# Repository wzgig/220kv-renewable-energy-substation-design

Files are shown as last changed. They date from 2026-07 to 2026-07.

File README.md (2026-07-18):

<div align="center">

# 220kV 新能源汇集变电所电气一次部分初步设计



课程设计工程仓库：主接线方案、负荷与短路计算、设备选型、配电装置设计、CAD 图纸、说明书与答辩材料。

[正式报告](report/README.md) · [交付说明](deliverables/README.md) · [完整性复盘](docs/DESIGN_COMPLETENESS_AUDIT.md) · [执行提示词](docs/EXECUTION_PROMPT.md) · [假设台账](docs/DESIGN_ASSUMPTIONS_REGISTER.md) · [手绘指南](docs/HAND_DRAWING_GUIDE.md) · [总体规划](docs/MASTER_PLAN.md) · [接线基线](docs/MAIN_SCHEME_BASELINE.md) · [设备预筛](docs/EQUIPMENT_SELECTION_BASELINE.md) · [设计输入](data/design_inputs.yaml) · [标准台账](docs/STANDARDS_REGISTER.md) · [需求追踪](docs/REQUIREMENTS_TRACEABILITY.md) · [CAD 工作流](docs/CAD_WORKFLOW.md) · [项目日志](PROJECT_LOG.md)

</div>

> [!IMPORTANT]
> 当前公开树及 `main` 可达历史只保留原创且已脱敏的成果。任务书原件、课程讲义、教材手册、他人设计书、参考 DWG、手稿照片和带个人元数据的文件均保留在本地私有材料区；旧 DWG 与身份记录已通过历史重写从 `main` 可达历史移除，可编辑 DWG 仅在本地保留。

本仓库固定对应第5组。第7组“220kV城市负荷中心变电所”已建立[独立公开仓库](https://github.com/wzgig/220kv-city-load-center-substation-design)，两组只共享通用工作流程，不共享设计数据和成果文件。

## 项目目标

完成一座 220/35/10kV 新能源汇集变电所的电气一次部分初步设计，形成可复核、可编辑、可打印和可答辩的完整交付物。当前任务书对应第 5 组，主变初始方案为 2×180MVA。

| 设计项 | 已确认输入 |
| --- | --- |
| 电压等级 | 220/35/10kV，另设 0.4kV 所用电系统 |
| 主变压器 | 2×180MVA、220/35kV、YNd11、uk=14% |
| 220kV 出线 | 2 回，预留 1 回；LGJ-400/50 |
| 35kV 集电线路 | 12 回，预留 2 回；WA-1～4、WB-1～3 为架空线并配置入口MOA，PVA-1～2、PVB-1～2、ES-1 为电缆并配置零序CT |
| 10kV 系统 | 2×31.5MVA、35/10.5kV、YNd11、uk=8% 的 T10；2×±12Mvar SVG；站用及辅助负荷 |
| 所用电系统 | 2×200kVA、10/0.4kV、SCB14 干式、Dyn11、uk=4%；轮换暗备用 |
| 短路计算基准 | 100MVA；平均额定电压 230/37/10.5kV |
| CAD 图纸范围 | 三张必交图：主接线、配电装置断面、平面布置；一张增强详图：SEC-220-L1-01 L1 线路间隔断面详图 |

## 当前设计基线

| 项目 | 已冻结结论 |
| --- | --- |
| 主变容量 | 2×180MVA、220/35kV、YNd11、uk=14%；正常负载率 77.857%；主变 N-1 需限发 35.780% |
| 10kV 电源与无功 | 2×31.5MVA、35/10.5kV、YNd11、uk=8% 的 T10；2×±12Mvar SVG |
| 所用变 | 2×200kVA、SCB14、Dyn11、uk=4%；正常一台运行，另一台暗备用 |
| 220kV 送出与分段职责 | 正常每回 367.780A；单回全送出及分段事故转供课程持续职责均取 735.559A；41℃课程保守允许载流量 475.242A |
| 220kV 短路职责 | 分列4.033kA/10.266kA，分段条件闭合7.385kA/18.798kA（RMS/峰值，含新能源课程上界）；电网单独3.607/6.500kA不是最终控制职责 |
| 10kV 短路等级 | 单台 T10 条件性最大综合上限 15.638kA；两台健康 T10 并列属禁止方式，敏感性为 28.472kA |
| 正常运行方式 | 220kV分段断路器、35/10kV母联正常断开；0.4kV母联正常闭合，一台所用变运行、另一台暗备用 |
| 中性点接地 | 220kV 中性点经中性点 CT 直接接地；35kV为2×1000kVA ZN接地变+低电阻、400A/10s、R≈50.5Ω；10kV为2×200kVA、200A/10s、R≈28.9Ω |
| 接地源联锁 | 正常分列时每段1套；母联合闸前退出受电/故障段接地源，仅保留健康侧1套；禁止母联闭合且两套接地源并联；重新分列后恢复每段1套 |
| MOA/零序CT | 220/35/10kV分别采用YH10W-204/532、YH5WZ-51/134、YH5WZ-17/45；7回35kV架空入口设MOA，5回35kV电缆及10kV电缆/SVG回路设零序CT；TOV/能量和精确型号待专题 |

这些数值是任务书缺项条件下的课程设计基线；教师明确口径、现行标准原文或厂家项目资料可以覆盖相应假设。

## 已形成的核心交付物

- 技术设计说明书：DOCX/PDF，正式 PDF 35 页 A4。
- 技术设计计算书：DOCX/PDF，29 页 A4。
- 课程设计总结：DOCX/PDF，4 页 A4。
- 答辩汇报：PPTX/PDF，11 页 16:9。
- 答辩问题清单：DOCX/PDF，7 页 A4。
- CAD 图纸按“三张必交图 + 一张增强详图”组织，共四张 A1 图：SLD-01、LAY-220-01、SEC-220-01 和 SEC-220-L1-01；公开 DXF/PDF/PNG，并在本地生成可编辑 DWG。四图已完成统一语义校验、AutoCAD AUDIT、A1 PDF/PNG 导出和逐图目检。
- 可再生的计算数据、脚本和 CAD 数据源。

## 仓库结构

~~~text
calculations/   可复核的负荷、电流、短路和设备校验计算
data/           任务书参数与后续设备数据
deliverables/   最终交付说明；压缩包本身不进入 Git 历史
docs/           项目范围、总体计划、决策、追踪矩阵与发布边界
drawings/       CAD 标准、块库、源图、导出图和绘图脚本
report/         说明书、计算书、总结和答辩材料
scripts/        项目健康检查及后续自动化工具
materials-private/  本地私有资料，仅 README 进入公开仓库
~~~

## 当前进度

- [x] 完成 128 个文件、约 283MiB 资料的结构与公开风险审计
- [x] 提取并冻结本组任务书的核心参数与交付要求
- [x] 确认 AutoCAD Core Console、A1 打印和 PDF/PNG 复核环境可用
- [x] 建立公开/私有边界、仓库结构和持续同步规则
- [x] 建立负荷/变压器、无功、LGJ温度修正、短路和设备预筛的可重复计算
- [x] 完成主接线技术经济比较并冻结可推进基线
- [x] 建立现行标准、废止版本和原文复核门槛台账
- [x] 完成220/35/10kV三相短路、变流器课程上界和1.10s I²t预校核
- [x] 建立220/35/10kV设备职责注册表和额定值等级预筛
- [x] 完成制图前拓扑复核：补入两回35kV电源变间隔并修正0.4kV暗备用正常状态
- [x] 冻结2×±12Mvar SVG、2×31.5MVA T10、海拔/污秽/保护时间等课程假设
- [x] 生成三张必交 A1 CAD 工程底图；公开 DXF/PDF/PNG，本地 DWG 通过 AutoCAD 原生 AUDIT，且通过 PDF/PNG 目检和 47 项阶段单元测试
- [x] 生成第四张 SEC-220-L1-01 A1/1:50 线路间隔增强详图的 DXF/PDF/PNG
- [x] 对本轮四图集成结果统一重跑 AutoCAD AUDIT、PDF/PNG 目检与语义检查；四图均为0错误并通过语义一致性校验
- [x] 完成四份正式报告 DOCX/PDF，并通过隐私、可访问性、审阅残留和逐页视觉终审
- [x] 完成11页答辩 PPTX/PDF，通过逐页渲染、画布溢出和元数据复核
- [x] 补齐课程级CT/PT与零序CT、MOA、接地变/NGR和接地开关；220kV管母完成载流/热稳/简化弯曲/电晕，35/10kV母线完成载流/热稳，绝缘子/套管完成电压、LIWV和持续/短时/峰值检查
- [ ] 完成精确设备型号、完整二次负荷、厂家动热稳定/温升、TOV/能量、外绝缘和真实场址校验
- [x] 完成本轮当前树隐私扫描、70 项测试、68 项健康检查及 GitHub Actions 等价再生成核验
- [x] 经授权完成含旧身份/DWG 的公开历史改写和精确租约强推；可达历史、GitHub Actions、远端提交与本地工作树均已核验

## 本地验证状态

| 验证对象 | 已完成 | 尚待完成 |
| --- | --- | --- |
| 四份正式报告 | 正式 PDF 为 35/29/4/7 页 A4，DOCX 与 PDF 已逐页终审 PASS；说明书和计算书已补充正式论证、编号公式、代入过程与结果分析；隐私、可访问性和审阅残留检查 PASS | 若后续重新生成，需重做目录、PDF 和隐私闭环 |
| 11 页答辩汇报 | PPTX/PDF 逐页渲染、画布溢出、页数和元数据检查 PASS | 当前树发布检查已通过 |
| 四张 A1 CAD 图（3+1） | 四图均完成DXF语义一致性校验、AutoCAD原生AUDIT（0错误）、单页A1 PDF/PNG导出和逐图目检 | 厂家外形、真实场址和施工级净距仍由后续工程资料覆盖 |
| 仓库发布 | 当前树隐私扫描、70 项测试、68 项健康检查、四图再生成校验和公开历史治理均已通过 | 后续有效修改继续执行提交、推送、Actions 和远端一致性闭环 |

## 工作方式

每个有效修改批次都执行以下闭环：

1. 更新计算、文档或图纸源文件。
2. 更新 PROJECT_LOG.md 和相关决策/追踪状态。
3. 运行项目检查：

   ~~~powershell
   powershell -NoProfile -ExecutionPolicy Bypass -File scripts/project_health_check.ps1
   ~~~

4. 使用 Conventional Commit 提交并推送到 main。
5. 核对 GitHub Actions、远端提交和工作区状态。

> [!NOTE]
> 任务书写明文档一般手写、图纸手绘。用户已确认CAD图作为完整工程底稿，最终按图手绘临摹；课程假设均可由教师或真实工程资料覆盖。

## 权利与资料边界

仓库目前不附开放源代码或内容许可证。第三方资料不在仓库中；后续若拆分原创脚本与原创图纸的授权，将分别处理，不能将第三方材料的权利扩展到本项目。

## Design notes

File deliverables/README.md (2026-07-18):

# 最终交付区

本目录只记录交付边界和打包规则；提交压缩包本身不进入 Git 历史。当前课程成果已存放在 `report/` 和 `drawings/` 中。

## 已形成的交付成果

| 类别 | 成果 | 位置与格式 | 本地验证 |
| --- | --- | --- | --- |
| 正式报告 | 技术设计说明书、计算书、课程设计总结、答辩问题清单 | `report/`，DOCX/PDF，正式 PDF 为35/29/4/7页 A4 | 逐页终审及 DOCX 隐私/可访问性/审阅残留检查 PASS |
| 答辩汇报 | 220kV 新能源汇集变电所答辩汇报 | `report/`，PPTX/PDF，11 页 16:9 | 逐页渲染、画布溢出、PDF 页数和公开元数据检查 PASS |
| 电气主接线简图 | `single_line_a1` | 公开 DXF/PDF/PNG；DWG 本地生成 | AutoCAD AUDIT、A1 PDF/PNG 目检和生成测试通过 |
| 配电装置平面布置图 | `switchyard_plan_a1` | 公开 DXF/PDF/PNG；DWG 本地生成 | AutoCAD AUDIT、A1 PDF/PNG 目检和生成测试通过 |
| 配电装置断面图 | `switchyard_section_a1` | 公开 DXF/PDF/PNG；DWG 本地生成 | AutoCAD AUDIT、A1 PDF/PNG 目检和生成测试通过 |
| L1线路间隔增强详图 | `switchyard_line_bay_detail_a1`（SEC-220-L1-01） | 公开 DXF/PDF/PNG；DWG 本地生成 | A1/1:50；AutoCAD AUDIT、PDF/PNG目检和语义生成测试通过 |

## 提交包应包含

- 课程设计任务书（仅提交，不公开原件）；
- 技术设计说明书；
- 技术设计计算书；
- 三张必交图：电气主接线图、配电装置断面图、平面布置图；
- 一张增强详图：SEC-220-L1-01 220kV I段L1线路间隔断面详图；
- 课程设计总结与答辩材料；
- 必要时提供 CAD 可编辑源文件和兼容版。

任务书原件、课程资料和含个人信息的提交版只能从本地私有材料区取用，不应复制到公开仓库。用户已确认CAD图可作为完整工程底稿，后续按“三张必交图+一张增强详图”手绘临摹。

## 打包前检查

- [x] 四份正式 PDF 页数和 A4 纸张规格已核对。
- [x] 答辩 PPTX/PDF 的 11 页渲染、溢出和元数据已核对。
- [x] 四张 CAD PDF 均为单页横向 A1，四份 DWG 的 AutoCAD AUDIT 均为0错误，PDF/PNG逐图目检和DXF语义检查通过。
- [x] SEC-220-L1-01 已核对1:50、设备链、ES、MOA、基础、接地接口和课程净距。
- [x] SLD-01 已核对线路侧ES位置、35/10kV接地变容量、母联接地源联锁、7回架空入口MOA、35/10kV电缆ZCT和三相CT职责分离。
- [x] 公开版姓名、学号、班级和签字字段保持留空。
- [x] 完成本轮当前树隐私与公开边界扫描；公开文件未发现身份、邮箱、绝对用户路径或生成器残留。
- [x] 复跑 70 项测试并完成 68 项 `scripts/project_health_check.ps1` 检查。
- [x] 核对实际提交文件、Office/PDF 元数据、CAD PDF/PNG 与可打开性。
- [x] 经授权完成含旧身份/DWG 的公开历史改写和精确租约强推，并核对 `main` 可达历史、GitHub Actions、远端提交和工作树状态。

提交压缩包、视频、页面渲染中间件和大型临时导出文件不进入 Git 历史。

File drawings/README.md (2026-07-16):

# 图纸工作区

本目录保存本项目原创的 CAD 标准、块库、结构化绘图数据、源图和导出图。第三方参考 DWG 位于本地私有材料区，不进入仓库。

本项目按“三张必交图 + 一张增强详图”组织四张 CAD 图纸。

三张必交图纸：

1. 电气主接线简图；
2. 配电装置断面图；
3. 配电装置平面布置图。

一张增强详图：

4. 220kV I 段 L1 线路间隔断面详图，用于补足设备链、接地开关、基础和净距表达。

所有图纸共用一份设备表、间隔表和尺寸/净距数据。公开仓库以可再生 DXF 为编辑源，PDF/PNG 预览放在 exports/；AutoCAD 生成的 DWG 保留在本地并由 `.gitignore` 排除，避免公开机器写入的 LastAuthor 元数据。详细流程见 [CAD 工作流](../docs/CAD_WORKFLOW.md)。

## 四张工程底图范围

| 图号 | 图纸 | 图幅/比例 | 可再生源 | AutoCAD与预览 |
| --- | --- | --- | --- | --- |
| SLD-01 | 电气主接线简图 | A1/NTS | `data/single_line_layout.yaml`、`scripts/generate_single_line.py` | 公开 `source/single_line_a1.dxf`、`exports/single_line_a1.pdf/.png`；DWG 本地生成 |
| LAY-220-01 | 220kV户外AIS平面布置图 | A1/1:200 | `data/switchyard_layout.yaml`、`scripts/generate_switchyard_drawings.py` | 公开 `source/switchyard_plan_a1.dxf`、`exports/switchyard_plan_a1.pdf/.png`；DWG 本地生成 |
| SEC-220-01 | 220kV户外AIS典型间隔断面图 | A1/1:100 | 同上 | 公开 `source/switchyard_section_a1.dxf`、`exports/switchyard_section_a1.pdf/.png`；DWG 本地生成 |
| SEC-220-L1-01 | 220kV I段L1线路间隔断面详图 | A1/1:50 | `data/switchyard_layout.yaml`、线路间隔详图生成逻辑 | 公开 `source/switchyard_line_bay_detail_a1.dxf`、`exports/switchyard_line_bay_detail_a1.pdf/.png`；DWG 本地生成 |

平面图表达两段三相母线、正常断开的分段间隔、L1/L2、远期L3、T1/T2、母线PT/CVT、道路、主控楼和35/10kV配电楼。SEC-220-01 同页表达线路间隔A-A与主变间隔B-B，标注母线/构架标高、相间距、设备序列和课程净距表。SEC-220-L1-01 将线路设备链放大到 1:50，表达母线侧QS、QF、TA、线路侧QS+常开ES、CVT、MOA、出线构架、基础及接地连接；地下接地网只作接口示意，不虚构接地电阻、接触电压或跨步电压计算。

~~~powershell
.venv\Scripts\python.exe drawings\scripts\generate_single_line.py
.venv\Scripts\python.exe drawings\scripts\generate_switchyard_drawings.py
powershell -NoProfile -ExecutionPolicy Bypass -File drawings\scripts\export_all_drawings.ps1
pdftoppm -png -r 150 -singlefile drawings\exports\single_line_a1.pdf drawings\exports\single_line_a1
pdftoppm -png -r 150 -singlefile drawings\exports\switchyard_plan_a1.pdf drawings\exports\switchyard_plan_a1
pdftoppm -png -r 150 -singlefile drawings\exports\switchyard_section_a1.pdf drawings\exports\switchyard_section_a1
pdftoppm -png -r 150 -singlefile drawings\exports\switchyard_line_bay_detail_a1.pdf drawings\exports\switchyard_line_bay_detail_a1
~~~

`normalize_pdf.py` 会在规范化元数据时清除 AutoCAD 为 SHX 文字自动写入的 PDF 批注层；公开版四图必须保持单页横向 A1、`/Annots` 为 0，且规范化前后 PNG 像素哈希一致。

主接线图统一采用：主变2×180MVA、220/35kV、YNd11、uk=14%；T10 2×31.5MVA、35/10.5kV、YNd11、uk=8%；所用变2×200kVA、SCB14、Dyn11、uk=4%；SVG 2×±12Mvar。35kV每段采用1000kVA ZN接地变+低电阻，400A/10s、R≈50.5Ω；10kV每段采用200kVA，200A/10s、R≈28.9Ω。正常每段1套，母联合闸前退出受电/故障段接地源，只保留健康侧1套，禁止母联合闸且两套并联。7回35kV架空入口标MOA，5回35kV电缆及10kV电缆/SVG回路标ZCT。`R`表示预留；CT/PT完整二次负荷、ZCT窗口/负担、41℃厂家适配、MOA能量/TOV和真实场址资料仍由后续专题覆盖。

平断面图中的A1/A2/B1/B2/C/D来自课程第七章表7-2；14m典型间隔、4m相间距、9m母线标高、道路、建筑和设备外形均明确标为课程设计几何假设，不得当作施工放样尺寸。

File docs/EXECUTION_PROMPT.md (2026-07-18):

# 课程设计执行提示词

## 本轮说明书与计算书补充重构提示词

> 以当前项目中的技术设计说明书、技术设计计算书、统一 YAML 参数、可再生计算结果和已冻结设计决策为依据，对报告进行实质性补充与结构优化。保留可靠的原始数据、表格、图纸和结论，不把课程假设写成任务书原值，也不虚构尚缺的厂家或现场参数。每个设计与计算环节均按“设计目的与依据—计算或选择方法—符号及单位—公式—参数取值—逐步代入—结果—合理性校验—工程含义与边界”的顺序展开；将现有以表格汇总为主的表达改为“正文论证为主、公式推导支撑、表格归纳结果”的正式工科课程设计结构。重点补充主接线方案取舍、负荷与变压器容量、N-1限发、SVG与T10、所用电、持续电流、标幺短路计算、变流器贡献、设备额定/开断/峰值/I²t校验、母线、接地变与低电阻、MOA和事故运行联锁。所有新增数值优先从统一结果文件读取；发现不同计算口径时必须并列说明，不得用含混文字掩盖差异。完成后重新生成 DOCX/PDF，更新目录和页码，运行计算、测试、隐私清理及逐页渲染检查，并保留修改前原版。

## 可直接复用的重构版提示词

> 你是本项目的电力工程课程设计协作代理。总目标是完成“第5组 220kV 新能源汇集变电所电气一次部分初步设计”，形成计算可复核、图纸可手绘临摹、文档与图纸一致、公开仓库可持续维护的完整工程底稿。
>
> ### 1. 输入与证据优先级
>
> 1. 任务书、教师明确要求和本组原始数据优先级最高，不得用网络资料覆盖。
> 2. 任务书缺项时，优先使用现行国家标准、行业标准的官方题录或合法取得的正文，以及设备厂家正式样本。
> 3. 仍无法取得唯一值时，采用偏保守且适合课程设计的工程假设继续推进。每项假设必须记录类别、数值、理由、影响、替换触发条件和复核状态。
> 4. 教师新口径或真实场址/设备资料到达后，统一输入文件中的新值覆盖课程假设，并同步重算、重绘、重写。
>
> ### 2. 设计范围
>
> - 完成原始资料整理、主接线方案比较、负荷与变压器选择、最大持续工作电流、短路电流、设备选择与动热稳定校验、配电装置设计、说明书、计算书、总结和答辩提纲。
> - 必须完成任务书要求的三张图：电气主接线简图、220kV 户外 AIS 配电装置典型断面图、220kV 户外 AIS 平面布置图；另增加一张 `SEC-220-L1-01` 线路间隔 A1/1:50 断面详图，作为设备校核和手绘临摹增强成果。
> - CAD 图按完整工程底图绘制，并导出 DWG、DXF、PDF、PNG；最终由用户按底图手绘临摹。
>
> ### 3. 一致性规则
>
> - `data/design_inputs.yaml` 保存题目输入和显式假设，`data/design_baseline.yaml` 保存冻结方案；计算、设备职责、图纸和文档必须读取同一数据源。
> - 不允许在图纸、说明书或设备表中单独手填与统一输入不一致的容量、电流、编号、母联状态或设备数量。
> - 预留回路、正常断开、事故切换、条件性运行方式和禁止运行方式必须在计算与图纸中明确区分。
>
> ### 4. 研究与计算规则
>
> - 网络检索优先官方标准平台、政府/电网机构和厂家正式资料；搜索摘要、百科、论坛和营销转载只能作为线索，不能单独支撑数值结论。
> - 所有公式保留变量定义、单位、代入值、结果和判据。关键结果至少做自动测试或独立数量级复核。
> - 课程设计假设不能伪装成标准固定值；标准题录不能替代需要逐条核对的标准正文。
>
> ### 5. CAD 规则
>
> - 使用参数化 YAML/CSV、Python/ezdxf 和 AutoCAD Core Console 生成、审计、转换和出图。
> - CAD 批处理以 Core Console、PDF 渲染和 PNG 目检形成可重复闭环。
> - 平面图与断面图共用设备外形、间隔宽度、道路、净距和标高数据；不得从旧参考图按比例猜尺寸。
> - 每张图必须有图框、图号、比例、图例、设计说明、关键尺寸、设备编号和课程假设标识，且适合打印后手绘临摹。
> - 对照任务书、指导书和参考设计逐项检查设备完整性。确认需要的断路器、隔离开关、接地开关、三相CT、零序CT、PT/CVT、MOA、母线、绝缘子、套管及接地变+低电阻设备包必须同步进入数据、计算、图纸和报告；35/10kV母联转供必须固化“先退出受电/故障段接地源、仅保留健康侧1套”的联锁。经计算判定不需要的限流电抗器等设备，也要写明“不采用”的判据，不能以沉默代替设计结论。
> - 避雷器与避雷针分开处理：完成各电压等级 MOA 配置和课程级绝缘配合；缺少雷暴日、土壤电阻率、厂家外形等资料时，不伪造直击雷保护范围、接地网电阻或施工放样尺寸。
>
> ### 6. 版本与公开规则
>
> - 原始任务书、私人资料、受限标准全文、旧参考设计和第三方 DWG 仅保存在 `materials-private/`，不得进入公开 Git 历史。
> - 每个有效批次依次完成：重新生成结果、单元测试、项目健康检查、CAD/PDF 目检、项目日志更新、逐文件暂存、提交、推送、远端 Actions 核验。
> - 不使用 `git add .`；不得提交浏览器缓存、临时文件、自动保存文件或提交压缩包。
>
> ### 7. 完成判据
>
> - 任务书追踪矩阵覆盖全部要求；关键未决项只剩教师或真实工程数据才能替换的复核项。
> - 计算结果、设备表、主接线、平面图、断面图和说明书中的容量、电流、编号、运行方式完全一致。
> - 三张必交 CAD 图和一张增强详图均可编辑、可再生、无缺字和裁切，DXF 经语义检查，DWG 经 AutoCAD AUDIT，PDF/PNG 已逐图目检；用户能够据此手绘临摹。
> - 本地分支与 GitHub `main` 一致，自动检查通过，公开仓库不含私人或受限材料。

## 本轮已确认授权

- 用户已确认允许完成完整 CAD 工程底图，最终自行手绘临摹。
- 用户已允许对任务书未给参数进行官方资料检索，或采用明确标注的合理课程设计假设。
- 只有改变根本拓扑、造成明显安全风险或无法形成保守取值的问题才需要再次询问。

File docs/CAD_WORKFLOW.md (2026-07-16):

# CAD 制图与自动化工作流

## 已确认环境

本项目使用 AutoCAD Core Console、GB A0-A4 图框、DWG To PDF 打印配置和黑白打印样式。Core Console 已实测完成 DXF 原生 AUDIT、2018 DWG 保存和 A1 PDF 打印，并以 PDF/PNG 渲染目检完成闭环。

现有 17 个参考 DWG 仅作版式和布置理解。其中部分旧图引用本机缺失的第三方 SHX 字体，直接复用可能导致乱码和尺寸漂移，因此新图从统一标准与块库开始构建。

## 目录约定

~~~text
drawings/
├── standards/  图层、文字、标注、线宽、图框与打印标准
├── blocks/     一次设备与电气符号块
├── data/       拓扑、设备、间隔、坐标和净距参数
├── source/     公开原创 DXF；DWG 仅本地生成并忽略
├── scripts/    生成、校核、转换和批量打印脚本
└── exports/    PDF/PNG 预览与兼容版输出
~~~

## 技术路线

1. 用 YAML/CSV 保存主接线拓扑、设备表、间隔顺序、尺寸和安全净距。
2. 使用 Python ezdxf 参数化生成 ASCII DXF，保证源文件可再生。
3. 使用 AutoCAD Core Console 执行 SCR/AutoLISP 校核、转换和批量出图。
4. 使用项目 PowerShell 脚本调用 AutoCAD Core Console，执行 AUDIT、保存 2018 DWG 并通过官方 PC3/CTB 打印。
5. 用 Poppler 将 PDF 渲染为 PNG，目检文字、线宽、图框、比例、标注和打印范围。

Python 依赖统一写入根目录 `requirements.txt` 并安装到项目虚拟环境，不污染系统环境：ezdxf 用于 DXF 生成和语义审计，pypdf 用于规范化 AutoCAD PDF。

CI不直接比较平断面DXF的原始字节，而比较实体、图层、线型、字体和文字/几何的语义指纹；这样可忽略ezdxf在独立进程中可能出现的CLASSES表顺序差异，同时仍能阻止真实图面漂移。

## 当前四张图纸范围

~~~text
drawings/data/single_line_layout.yaml
drawings/data/switchyard_layout.yaml
drawings/standards/single_line_standard.yaml
drawings/standards/switchyard_standard.yaml
drawings/scripts/sld_symbols.py
drawings/scripts/generate_single_line.py
drawings/scripts/generate_switchyard_drawings.py
drawings/scripts/export_single_line.ps1
drawings/scripts/export_all_drawings.ps1
drawings/scripts/normalize_pdf.py
drawings/source/single_line_a1.dxf
drawings/source/switchyard_plan_a1.dxf
drawings/source/switchyard_section_a1.dxf
drawings/source/switchyard_line_bay_detail_a1.dxf
drawings/exports/single_line_a1.pdf
drawings/exports/single_line_a1.png
drawings/exports/switchyard_plan_a1.pdf
drawings/exports/switchyard_plan_a1.png
drawings/exports/switchyard_section_a1.pdf
drawings/exports/switchyard_section_a1.png
drawings/exports/switchyard_line_bay_detail_a1.pdf
drawings/exports/switchyard_line_bay_detail_a1.png
~~~

中文文字采用本机已验证的 `txt.shx + gbcbig.shx` 大字体组合，避免 Core Console 对 TTC 字体替换成问号。DXF 使用 R2018/AC1032、毫米单位、A1 横向 841×594 模型空间纸面坐标；DWG 作为本地 AutoCAD 兼容输出，不进入公开 Git 历史。

三张必交图已有AutoCAD Core Console原生AUDIT与目检PASS证据，SEC-220-L1-01的DXF/PDF/PNG也已生成。四图集成后必须统一重跑AUDIT、A1单页PDF、150dpi PNG、逐图目检和语义检查；PDF规范化还须清除AutoCAD SHX文字批注层并确认`/Annots=0`，且规范化前后PNG像素哈希一致。公开仓库使用DXF/PDF/PNG，本地DWG不进入Git。

## 制图顺序

### 1. 电气主接线简图

- 输入：最终主接线方案、主变/T10/所用变联结组与阻抗、回路/母线/母联、三相CT/PT、零序CT、MOA、接地变+低电阻和接地开关配置。
- 重点：220、35、10、0.4kV 电压层次清晰；本期与预留回路区分；设备编号唯一；220kV ES接在线路侧QS之后；35/10kV接地设备包容量与母联接地源联锁说明齐全。
- 验收：图中回路数与任务书、回路表、设备表完全一致；7回35kV架空入口MOA、5回35kV电缆ZCT、10kV电缆/SVG ZCT及“母联合闸前仅保留健康侧1套接地源”均可在图面或说明中定位。

### 2. 配电装置断面图

- 输入：典型间隔设备型号、外形尺寸、安全净距、支架和母线标高。
- 重点：剖切位置、设备中心线、相间/相地净距、基础与检修空间。
- 验收：所有尺寸有来源，不能从参考图按比例猜测。

### 3. 配电装置平面布置图

- 输入：间隔表、出线方向、道路、建筑/构架、设备坐标和断面参数。
- 重点：220kV 向西北出线，35kV 向东/向南，站内与备用电源方向合理；预留间隔清楚。
- 验收：平面与断面使用同一设备、间隔宽度、编号和标高体系。

### 4. SEC-220-L1-01 线路间隔增强详图

- 图幅与比例：A1横向、1:50。
- 设备链：220kV I段管形母线→母线侧QS→QF→TA→线路侧QS+常开ES→CVT→YH10W-204/532 MOA→出线构架。
- 表达内容：设备编号、课程额定参数、基础、构架与设备接地、地下接地网接口、主要标高、水平尺寸及A1/A2/C类净距。
- 边界：设备外形、基础荷载和端子方向由厂家图覆盖；缺少土壤电阻率和接地网几何时，不填写接地网电阻、接触电压、跨步电压，也不声称避雷针已覆盖全站。

## 平断面统一参数

- 220kV户外AIS、分相中型布置；分段正常断开；
- 相间中心距4.0m，典型相邻功能中心按14m节距组织；
- 母线中心标高9.0m、线路构架挂线点14.5m、主变构架挂线点11.5m；
- 课程表7-2净距：A1=1800、A2=2000、B1=2550、B2=1900、C=4300、D=3800mm；
- SEC-220-L1-01 采用A1/1:50放大线路间隔，净距、标高和设备编号必须与LAY-220-01、SEC-220-01同源；
- 设备外形、道路、建筑和基础是课程几何假设，精确厂家图优先覆盖。

## 图形标准草案

- 当前中文文字使用 AutoCAD 自带 `txt.shx + gbcbig.shx`，西文与数字使用兼容字体，并以最终 PDF/PNG 打印效果为准。
- 不提交版权不明的第三方 SHX；避免外部参照和绝对路径。
- 图层至少区分：母线、一次设备、导线、符号、文字、尺寸、中心线、构筑物、道路、预留和图框。
- 黑白打印依赖线宽表达，不以屏幕颜色代替最终线宽。
- 原生文件保存为 2018 格式，并输出 PDF 与 PNG；如教师或提交平台要求，再另存 2013 兼容版。

## CAD 质量检查

- 无缺失字体、代理对象、未绑定外部参照和不可解析路径；
- 图形范围正常，无远离原点的垃圾对象；
- 图层、块名、设备编号和属性命名稳定；
- 图框、比例、单位、线宽和打印区域正确；
- PDF 中无裁切、重叠、黑块、乱码或过细线条；
- 当前候选树以公开 DXF/数据/脚本重建关键图形，本地 DWG 不再进入新提交；既有历史的旧 DWG 待用户确认后清理。

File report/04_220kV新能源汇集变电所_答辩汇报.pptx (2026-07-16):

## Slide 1

《发电厂电气部分》课程设计 · 第5组

220kV新能源汇集变电所
电气一次部分初步设计

主接线 · 容量与短路 · 设备及防雷接地预筛 · AIS平断面与L1详图

公开答辩版｜姓名、学号、班级与签字留空

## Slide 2

本设计以270MW新能源汇集与四级电压系统为主线

设计对象

220 / 35 / 10 / 0.4kV

12回35kV集电线路

两回220kV本期送出，预留L3

交付范围

技术设计说明书 + 计算书

SLD-01 主接线图
LAY-220-01 平面图
SEC-220-01 典型断面图
SEC-220-L1-01 L1线路间隔详图

答辩清单与可追溯计算脚本

2

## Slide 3

最终主接线通过分段与分列运行控制风险

方案结论

220kV采用单母线分段；35kV和10kV均采用单母线两分段；0.4kV采用单母线分段。

正常运行：220kV分段断路器断开；
35/10kV母联断开；0.4kV母联闭合。

T1、T2分别带35kV I/II段，T10与SVG按段配置。

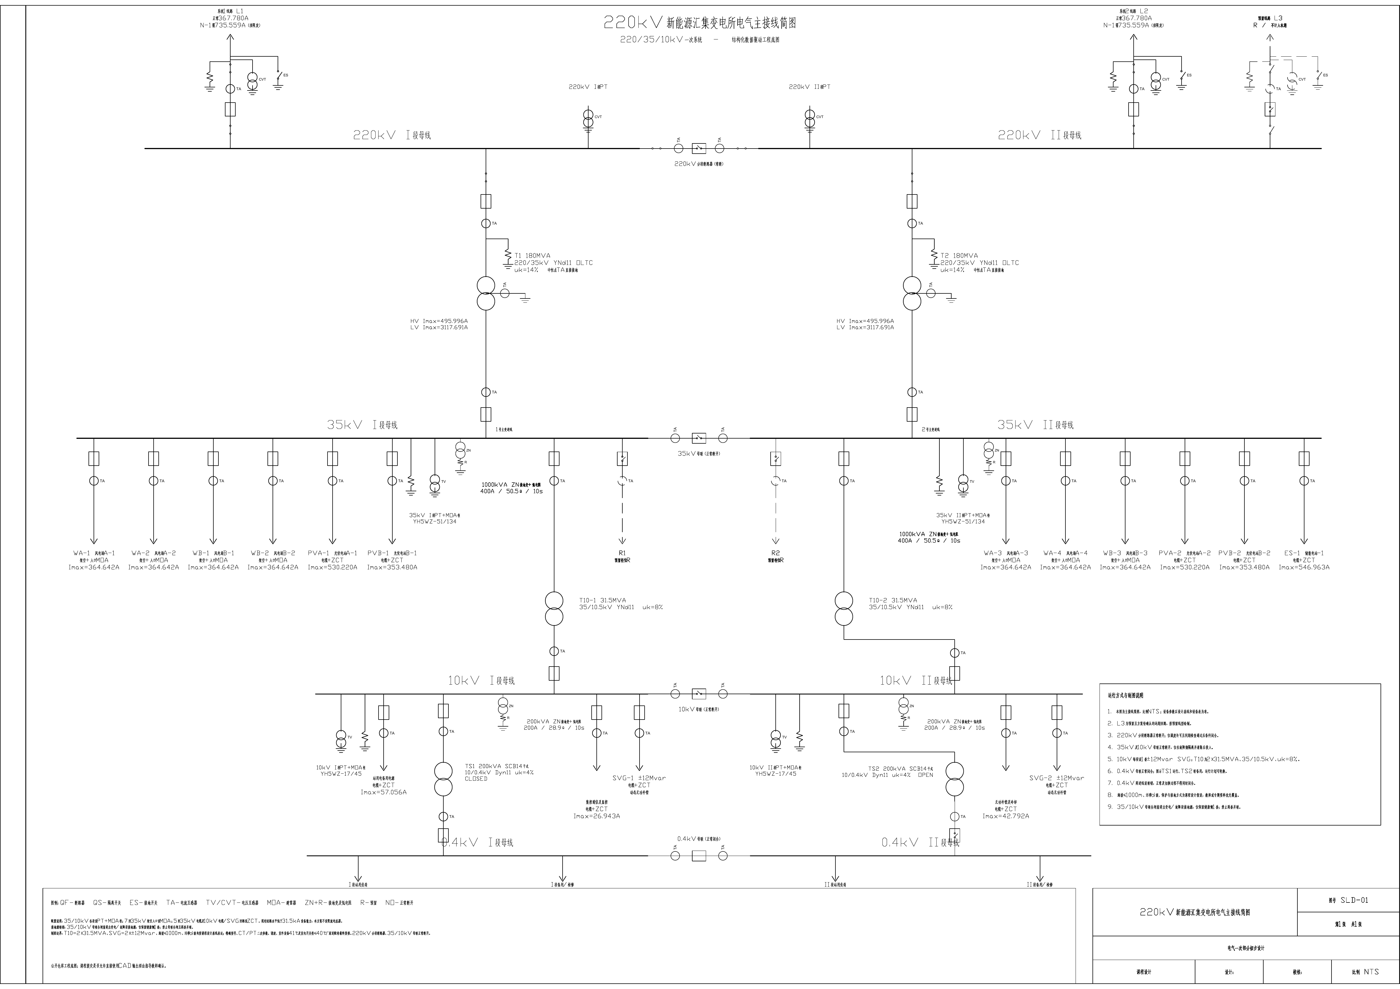
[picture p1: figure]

3

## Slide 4

2×180MVA主变满足正常方式，N-1成为容量约束

主变采用2×180MVA、220/35kV油浸有载调压、YNd11、uk=14%。35kV计算容量280.286MVA，正常负载率77.857%；N-1需限发35.780%。

77.857%

正常双机平均负载率

35.780%

主变N-1限发比例

100.286

单台容量缺口 / MVA

4

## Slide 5

T10、SVG与所用变构成完整的辅助供电链

容量选择与主接线保持逐段对应，兼顾正常运行、单元退出和站用电连续性。

2×31.5MVA T10

35/10.5kV，YNd11，uk=8%
正常均衡负载率39.58%
N-1最严负载率79.17%

2×±12Mvar SVG

总容量24Mvar
保守需求21.8875Mvar
补偿后功率因数0.98147

2×200kVA SCB14所用变

10/0.4kV，干式，Dyn11
uk=4%；最严192.913kVA
一运一备，0.4kV母联闭合

5

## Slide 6

主变N-1是当前控制瓶颈，线路裕量仅2.864A

正常方式

367.780A/回
双回平均分担

线路单回N-1

735.559A
单看线路需限发35.390%

主变N-1限发后

472.377A
距课程载流量仅2.864A

6

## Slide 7

短路职责支持设备等级，35/10kV无需限流电抗器

基准100MVA，设备按条件性最大职责预筛；16.291/15.638kA低于31.5kA能力。高压熔断器不作主回路设备；阻波器仅在采用电力载波时配置。

电压级 | 必选许可/kA | 条件最大/kA | 禁止敏感性/kA | 峰值预筛/kA | 候选开断/kA
220kV | 4.033 | 7.385 | — | 18.798 | 50
35kV | 13.265 | 16.291 | 25.694 | 41.470 | 31.5
10kV | 14.492 | 15.638 | 28.472 | 39.808 | 31.5

7

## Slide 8

220kV户外AIS按145m×90m课程站区组织

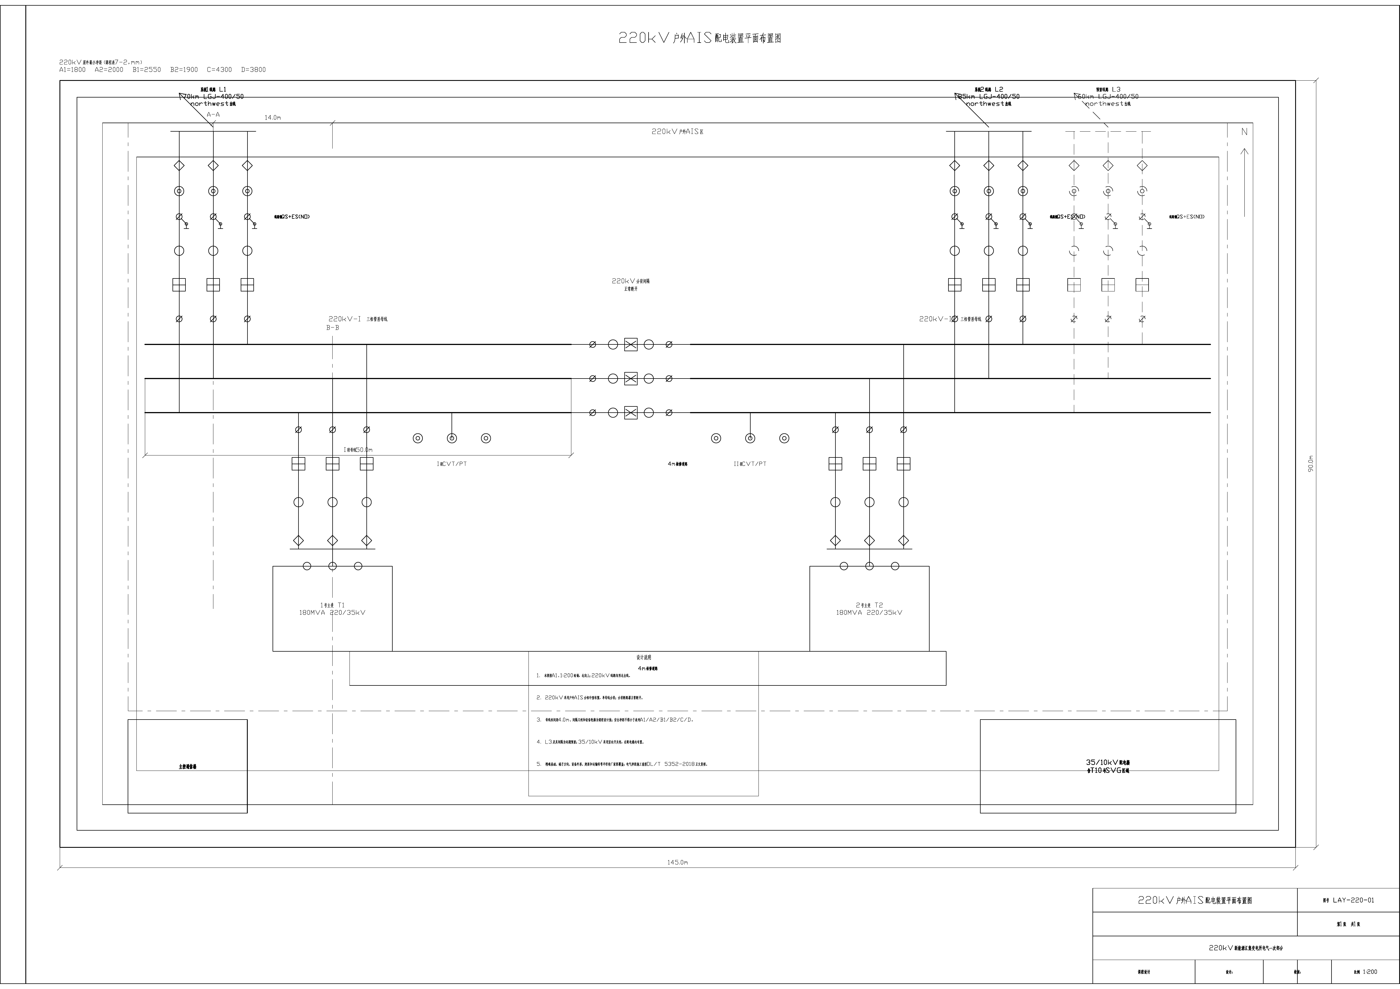
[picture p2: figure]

分相中型布置

线路、分段、主变间隔按14m典型功能节距组织

运输与检修

4m道路贯通，设备区、主变区与扩建区边界明确

课程几何

相间中心距4m；保留L3远期出线位置

8

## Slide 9

L1线路间隔详图补齐QS+ES、CVT与MOA设备链

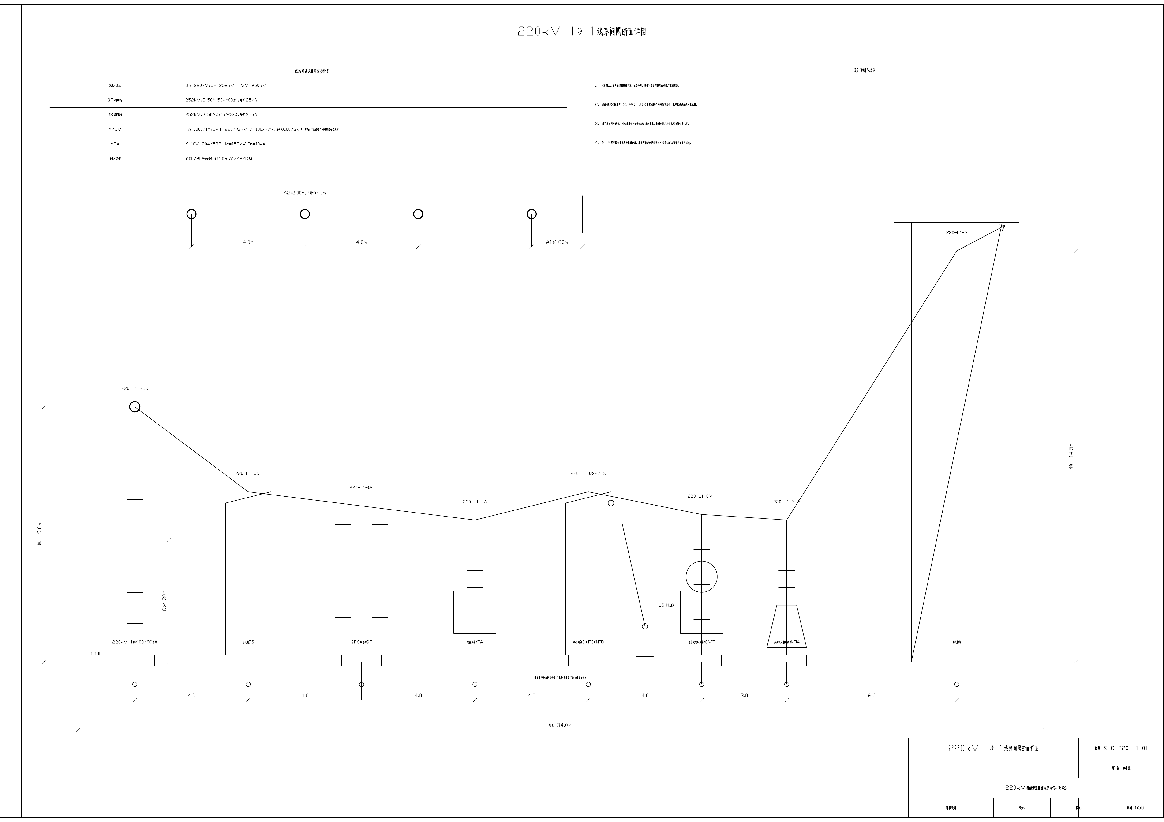
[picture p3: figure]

SEC-220-L1-01（A1，1:50）按管母—QS1—QF—TA—QS2+ES—CVT—MOA—出线构架组织；ES常开。设备外形与端子方向由厂家图覆盖。

A1
1800 mm

相对地
最小净距

C
4300 mm

带电体至
围栏/建筑

其余课程净距：A2=2000mm · B1=2550mm · B2=1900mm · D=3800mm

9

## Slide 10

220kV分段及35/10kV母联断开

分段并非默认并列。系统转供、检修或事故恢复必须满足调度许可、同期检查、限发与保护联锁条件。

正常保持分列

220kV分段断开
35kV母联断开
10kV母联断开

禁止未经许可并列两套220kV系统
禁止两台健康主变经35kV母联并列
禁止两台健康T10经10kV母联并列

仅0.4kV母联闭合

一台所用变运行
另一台进线断开
形成轮换暗备用

母联合闸前退出受电/故障段接地源
仅保留健康侧1套低电阻接地源
禁止两套低电阻接地源并联

10

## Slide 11

设计结论

方案完整，边界清晰，
四张A1图可直接临摹

2×180MVA主变 + 2×31.5MVA T10
2×±12Mvar SVG + 2×200kVA所用变
SLD-01 / LAY-220-01 / SEC-220-01
SEC-220-L1-01：四张A1图已完成

课程设计底稿，非施工图；工程实施前须按现行标准与厂家资料复核。

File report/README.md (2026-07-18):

# 课程设计文档与答辩成果

本目录已形成按学校模板编制的正式报告、答辩汇报和问题清单。说明书负责方案、依据、比较和结果；计算书保留公式、代入、单位和可追溯计算结果。

> [!IMPORTANT]
> 当前正式生成品已由最新 `report/scripts/build_reports.py` 统一再生成，并在 Word 中更新目录、导出 PDF、清理公开元数据后完成逐页视觉复核。页数以下方正式 Word PDF 为准；LibreOffice 对含 CAD 大图的说明书可能多分页 1 页，但不影响 Word/PDF 提交口径。

## 成果清单

| 序号 | 成果 | 格式 | 规模 | 本地验证状态 |
| --- | --- | --- | ---: | --- |
| 01 | 技术设计说明书 | DOCX / PDF | 35 页 A4 | 正式 PDF 逐页终审 PASS；DOCX 隐私、可访问性和审阅残留检查 PASS |
| 02 | 技术设计计算书 | DOCX / PDF | 29 页 A4 | 公式、数值、表格和分页逐页终审 PASS |
| 03 | 课程设计总结 | DOCX / PDF | 4 页 A4 | 逐页终审 PASS |
| 04 | 答辩汇报 | PPTX / PDF | 11 页，16:9 | PPTX/PDF 逐页渲染、PDF 检查和画布溢出检测 PASS；公开版元数据已清理 |
| 05 | 答辩问题清单 | DOCX / PDF | 7 页 A4 | 逐页终审 PASS |

## 文档质量与隐私状态

- 四份正式 DOCX/PDF 已完成独立只读终审，未发现裁切、重叠、表格破损或数值歧义；说明书、计算书、总结和问题清单正式 PDF 分别为35/29/4/7页。说明书各章按正式报告习惯另起页，章节前一页可能保留结构性留白。
- 四份 DOCX 已清除作者、最后修改者、自定义属性和修订标识；图片已补充替代文本。
- 答辩 PPTX/PDF 的标题已设为正式答辩标题，作者与最后修改者已统一为“课程设计项目组（公开版）”；清理前后 11 页渲染哈希一致。
- 公开版本保持姓名、学号、班级和签字字段留空；如需填写，应在本地私有提交版中完成。

## 本轮报告源同步范围

- 变压器冻结值：主变2×180MVA、220/35kV、YNd11、uk=14%；T10 2×31.5MVA、35/10.5kV、YNd11、uk=8%；所用变2×200kVA、SCB14、Dyn11、uk=4%。
- 35kV接口与接地：WA-1～4、WB-1～3为架空线并配置入口MOA，PVA-1～2、PVB-1～2、ES-1为电缆并配置ZCT；35kV采用2×1000kVA、10kV采用2×200kVA ZN接地变+低电阻课程设备包。
- 接地源联锁：正常分列时每段1套；35/10kV母联合闸前退出受电/故障段接地源，仅保留健康侧1套；禁止母联合闸且两套并联；重新分列后恢复每段1套。
- 补充设备：MOA参数及绝缘裕度、8类三相CT、35/10kV电缆零序CT、三类PT/CVT、管形/矩形母线、绝缘子/套管、220kV线路侧ES及35/10kV柜内ES。
- 校验边界：220kV管母完成载流、热稳、简化弯曲和电晕；35/10kV矩形母线只完成载流与热稳；套管完成最高电压、LIWV、持续、短时和峰值课程检查，机械/爬距仍待厂家。
- 负面选择：35/10kV短路职责低于31.5kA设备能力，当前不设限流电抗器；高压熔断器不作为主回路设备，仅在PT柜按厂家方案配置；阻波器仅在确定电力线载波通信时设置。
- 图纸口径：三张必交图+SEC-220-L1-01 A1/1:50增强详图，共四张CAD图；四图引用、DXF语义、AutoCAD AUDIT和PDF/PNG目检均已闭环。
- 工程边界：不虚构避雷针保护范围，也不虚构接地网电阻、接触电压或跨步电压；这些内容等待真实雷暴日、建筑高度、土壤电阻率和接地网几何。

## 再生成顺序

DOCX 每次重大修改后均需渲染为页面图片逐页检查，再输出最终 PDF。如果必须重新生成报告，顺序应为：

1. 生成 DOCX。
2. 在 Word 中更新目录并导出 PDF。
3. 对最终 DOCX/PDF 执行隐私和元数据清理。
4. 逐页渲染复核，确认页数、图表和数值未漂移。
5. 确认四张CAD图引用齐全，并复核四图语义、AutoCAD AUDIT和A1 PDF/PNG。

> [!WARNING]
> 已完成隐私清理的 DOCX 不应再用 Word 保存，否则可能重新写入本机的最后修改者信息。

报告与答辩成果、本轮当前树隐私扫描、70 项测试和 68 项健康检查均已通过；含旧身份/DWG 的公开历史已获授权完成重写并精确租约强推，后续每次修改继续由 GitHub Actions 复跑同等发布门。

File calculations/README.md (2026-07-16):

# 计算工作区

本目录用于保存可复核、可重复运行的设计计算，不把最终数值只写在说明书正文里。

当前已建立：

~~~text
load_and_transformers/         负荷、持续电流与主变/T10/所用变初算
short_circuit/                 220/35/10kV标幺网络、变流器课程上界与短路初算
equipment_selection/           回路职责、场景门控、设备额定值和一次设备专项预筛
results/                       JSON、CSV 和 Markdown 统一结果
~~~

设备模块当前已集成：

~~~text
conductor_and_bus_checks        LGJ、220kV管母及35/10kV矩形母线载流/热稳，220kV简化弯曲/电晕
instrument_transformers        三相CT、零序CT、PT/CVT的一次配置与课程职责
insulation_and_arresters        绝缘子/套管、MOA、Um、LIWV及电流/短时/峰值课程检查
grounding_packages              35/10kV接地变+低电阻设备包、馈线柜、CT目标及母联联锁
~~~

仍待工程专题闭合的内容包括：35/10kV母线机械与支撑受力、CT/PT/ZCT完整负担和暂态性能、套管爬距与机械破坏负荷、MOA TOV/能量、接地设备包厂家参数和接地故障/接地网计算。

计算规则：

- 原始参数统一读取 data/design_inputs.yaml；
- 每个结果同时保存输入、公式、单位、中间值和最终设计取值；
- 关键结果采用独立复算或单元测试；
- 报告中的表格和 CAD 标注优先从统一结果文件生成；
- 不使用参考设计书中的旧题数值替代本题输入。

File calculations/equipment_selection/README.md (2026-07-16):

# 主要电气设备预筛选模块

该模块把设备选择拆成三个层次：

1. 从现有负荷、持续电流、短路结果和主接线基线生成回路职责；
2. 用 `data/equipment_selection.yaml` 管理场景、回路组和候选分配；
3. 用 `data/equipment_catalog.yaml` 管理候选额定值及证据状态。

运行：

~~~powershell
python -m calculations.load_and_transformers.calculate
python -m calculations.short_circuit.calculate
python -m calculations.equipment_selection.calculate
python -m unittest discover -s tests -v
~~~

当前输出同时包含“开关设备额定值等级预筛选”和“课程设计专项闭环”，但不把课程目标表伪称为厂家订货型号。任何最终工程缺失值都会传播为 `pending`，不会被当成零、跳过或自动通过。

当前可以自动完成：

- 220kV线路N-1、主变高低压侧和35kV各类馈线持续电流职责；
- 220kV分段按735.559A保守持续职责闭环；
- 35kV两段按实际馈线分配的电流复核；
- 220kV、35kV、10kV必选、条件性和禁止运行方式的短路场景分级；
- 候选额定电流、开断电流、关合/峰值和短时耐受电流的算术预筛；
- 220kV Φ100/90铝合金管形母线、35kV每相3×125×10及10kV每相2×125×10铝母线的载流与C=87、t=1.10s热稳定校核；
- 220kV管形母线的简化动稳定与Peek公式电晕预校核；
- 220/35/10kV金属氧化物避雷器持续运行电压和LIWV/残压保护裕度校核；
- 35kV架空入口MOA与实际架空馈线组的接口映射，以及35/10kV电缆馈线ZCT覆盖与限定接地电流目标校核；
- CT变比、准确级目标及对应回路动热稳定预校核，以及PT、绝缘子/套管、接地开关课程选择表；套管补齐Um、LIWV、持续电流及动热稳定；
- 35kV每段一套ZN接地变+低电阻设备包（400A/10s、约50.5Ω、约8.083MVA、最小约808kVA、选1000kVA）和10kV每段一套设备包（200A/10s、约28.9Ω、约1.155MVA、最小约115.5kVA、选200kVA）；
- 接地变馈线开关柜、相/中性CT课程目标、保护功能及“母联合闸前退出受电/故障段接地源、禁止两套并联、分段恢复后各段一套”的联锁逻辑；
- 35/10kV短路水平低于31.5kA开关设备能力，课程方案不设限流电抗器；高压熔断器仅保留为PT柜厂家配置项。

当前必须保持待定：

- 厂家最终绝缘水平、外绝缘爬距、机械负荷、海拔和污秽适配；
- 最终保护配合、断路器开断数据及标准化短路热效应；
- 新能源和SVG的精确故障电流及动态峰值模型；
- 避雷器接地方式、能量耐受和完整绝缘配合；
- CT/PT负担、饱和、暂态级、铁磁谐振及二次回路最终分配；
- 母线支撑共振、端部受力、厂家温升和连接金具；
- 35/10kV矩形母线的支撑几何、共振、连接受力和机械动稳定（当前明确为 `pending`，不得视为已校核通过）；
- 接地变零序阻抗、接地电阻10s温升、相/中性CT饱和、保护定值、硬接点/软件联锁和完整厂家设备包；
- ZCT窗口尺寸、电缆屏蔽层接地回流路径、负担、拐点与精确型号；
- 厂家精确型号、当前样本、外形尺寸和室内40℃/室外41℃载流确认；
- 接地开关感应电流开合等级，以及PT柜熔断器的厂家配合与选择性。

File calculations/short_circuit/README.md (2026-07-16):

# 短路电流计算模块

该模块按任务书给定的100MVA标幺制、平均额定电压和X-only简化口径，完成220kV、35kV和10kV三相短路课程初算。GB/T 15544.1-2023作为最终复核依据，但本模块当前不是该标准的完整实现。

运行：

~~~powershell
python -m calculations.short_circuit.calculate
python -m unittest discover -s tests -v
~~~

当前计算点：

- 220kV分段断路器闭合的条件性最大方式，等待两系统并列许可确认；
- 220kV两段分列的正常可行方式；
- 35kV保持两段分列，并分别计算220kV分段断路器闭合与分列两种上游方式；
- 35kV 两台健康主变低压侧并列的非正常敏感性方式；
- 10kV两段分别由单台31.5MVA T10供电，并计算上游220kV分列/条件闭合方式；
- 两台健康T10经10kV母联并列的禁止敏感性方式；
- 220/35kV新能源贡献和10kV SVG贡献按额定电流1.1～1.2倍形成RMS课程上界。

10kV课程输入已冻结为2×31.5MVA、35/10.5kV、uk=8%的T10和2×±12Mvar SVG，因此10kV分列与禁止并列敏感性均已纳入可再生结果。

初算按任务书口径忽略电阻，并把k=1.8作为可配置的课程假设作用于电网和变流器RMS算术上界，形成等级预筛用的课程综合峰值。该k值不是由“忽略电阻”自动推导；设备最终校验必须结合R/X、标准电压系数、变压器修正系数、峰值系数κ和厂家变流器动态模型重新核对。

当前控制职责包括：220kV分列4.033kA/10.266kA、分段条件闭合7.385kA/18.798kA；35kV条件性上限16.291kA/41.470kA；10kV条件性上限15.638kA/39.808kA（RMS/课程综合峰值）。输出中的`grid_peak_current_ka`仍只表示电网分量，不能与课程综合峰值混用。新能源和SVG的精确动态、衰减、相位、R/X及标准峰值模型尚未建立，因此不得把课程峰值写成最终动稳定结论。第三回220kV线路L3不参加本期基准计算，远期投入场景另算。

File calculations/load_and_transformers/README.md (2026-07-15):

# 负荷与变压器计算模块

该模块直接读取 data/design_inputs.yaml，生成：

- 35kV、10kV 综合视在功率；
- 各类单回线路基础最大持续工作电流；
- 2×180MVA 主变正常负载率与 N-1 限发量；
- 220kV 出线均分电流基础值；
- 0.4kV 所用电连续/短时负荷统计和所用变初选；
- JSON、CSV 和 Markdown 结果文件。

运行：

~~~powershell
python -m calculations.load_and_transformers.calculate
python -m unittest discover -s tests -v
~~~

当前计算口径：

- 0.95 新能源同时出力系数只用于主变综合容量，不用于单回线路最大电流；
- 单回线路按该类最大负荷在回路间平均分配，并计 5% 线损；
- 主结果按乘 1.05 处理线损，同时保留除以 0.95 的敏感性值；
- 10kV 综合负荷暂计入主变总需求；
- 所用变初选的功率因数 0.80 为显式假设，最终设备选型前必须复核。

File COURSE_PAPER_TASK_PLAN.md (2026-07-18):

# 说明书与计算书补充重构计划

## 任务目标

将现有《技术设计说明书》和《技术设计计算书》从以结果表格为主的生成稿，扩充为具有完整设计论证、公式推导、数值代入、结果校核和工程边界说明的正式课程设计报告。

## 交付物

- 更新后的 `report/01_220kV新能源汇集变电所_技术设计说明书.docx/.pdf`
- 更新后的 `report/02_220kV新能源汇集变电所_技术设计计算书.docx/.pdf`
- 同步更新的报告生成脚本、报告说明、项目日志和验证期望
- 修改前 DOCX/PDF 的本地备份，位于忽略目录 `tmp/original_reports_20260718/`

## 内容约束

- 以 `data/*.yaml`、`calculations/results/**`、`docs/DESIGN_ASSUMPTIONS_REGISTER.md` 和既有设计决策为唯一数值来源。
- 不新增无法追溯的设备型号、标准数值、现场条件或保护定值。
- 每个关键环节至少包含方法说明、公式、符号和单位、代入、结果及工程解释。
- 保留“课程预筛”和“最终工程待复核”的边界，不把缺失输入按零处理或自动判为通过。
- 说明书突出方案与工程含义；计算书突出完整计算链，避免两份文档机械重复。

## 重点补充范围

1. 主接线方案比较、各电压级接线和事故转供逻辑。
2. 35kV/10kV负荷、主变、所用变、T10和SVG的容量计算。
3. 各回路持续工作电流、母线段多口径说明和LGJ-400/50温度修正。
4. 标幺基准、系统/线路/变压器电抗、220/35/10kV短路点及变流器贡献。
5. 设备额定电压、电流、开断、峰值与热稳定I²t校验。
6. 母线截面与热稳定、220kV管母简化弯曲和电晕。
7. 35/10kV接地电阻及接地变容量、MOA绝缘裕度和联锁边界。

## 验证清单

- 重新运行负荷、短路和设备选择计算，确认结果无漂移。
- 运行报告生成脚本、单元测试和项目健康检查。
- 用 Word 更新目录、域和页码并导出 PDF，随后清理公开元数据。
- 检查正文量、公式数量、章节编号、表格和图纸引用。
- 渲染两份最终 DOCX 的全部页面并逐页检查裁切、重叠、断表、孤立标题、公式换行和异常空白。
- 更新 `report/README.md`、`PROJECT_LOG.md` 和 PDF 页数测试。

## 完成状态（2026-07-18）

- 已先在 `docs/EXECUTION_PROMPT.md` 固化本轮重构提示词，再实施文档补充。
- 说明书已扩充至正式PDF 35页，正文约13307字符、28个表格、32个编号公式。
- 计算书已扩充至正式PDF 29页，正文约14082字符、19个表格、63个编号公式。
- 两份报告均已完成Word目录、域、罗马/阿拉伯页码和PDF导出闭环，全部64页逐页视觉复核通过。
- 表格窄列、孤立字符/单行、章节分页、项目符号和事故步骤编号等版式问题均已修复并复核。
- 已固化正式报告深度、前置页/正文页码、表格版式、列表编号语义和PDF页数回归测试；当前全量70项测试通过。
- 最终数值继续以结构化输入和三组计算脚本为准，35kV母线段多口径及3117.691A设备职责未被回退。

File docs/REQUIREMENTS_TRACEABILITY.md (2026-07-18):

# 需求追踪矩阵

来源页码指本地私有的本组任务书 PDF；公开仓库不包含原件。

| ID | 任务要求 | 来源 | 计划产物 | 验收证据 | 状态 |
| --- | --- | --- | --- | --- | --- |
| R-01 | 确定电气主接线 | 页 2、7-8 | 方案比较、最终拓扑、主接线图 | 技术经济比较表；图纸与回路表一致 | 基线完成，待教师口径复核 |
| R-02 | 确定主变台数、容量和型式 | 页 2、5、7-8 | 负荷计算、N-1 校验、设备参数表 | 容量、负载率、限发说明和型式依据 | 课程基线完成：主变2×180MVA、220/35kV、YNd11、uk=14%；T10 2×31.5MVA、35/10.5kV、YNd11、uk=8% |
| R-03 | 确定所用电接线及所用变压器 | 页 2-3、6-7；学生指导书页9 | 所用电负荷统计、0.4kV 接线、变压器选择 | 经常负荷、裕度、正常一台运行、母联闭合及暗备用切换校验 | 课程基线完成：2×200kVA、SCB14干式、Dyn11、uk=4%；正常一台运行、0.4kV母联闭合、另一台暗备用；精确型号待厂家资料复核 |
| R-04 | 确定各电压等级配电装置型式 | 页 2-3、8 | 220/35/10kV 型式比较与选择 | 环境、可靠性、占地和设备适配说明 | 基线完成：220kV户外AIS；35/10kV室内金属铠装开关柜 |
| R-05 | 配置电流、电压互感器 | 页 2、7-8 | CT/PT、零序CT配置表和主接线标注 | 测量、保护、同期、剩余电流/单相接地和自动装置需求覆盖 | 课程配置完成：8类三相CT、35kV五回电缆零序CT、10kV电缆/SVG零序CT、220kV CVT及35/10kV母线VT目标已冻结；负担、饱和、暂态性能、窗口尺寸、电缆压降和精确型号仍待工程复核 |
| R-06 | 选择主要电气设备并校验 | 页 2-3、7-8 | 开关设备、母线、互感器、绝缘子/套管、MOA、接地设备包、ES及适用性结论 | 电压、电流、开断、动稳、热稳、绝缘配合课程预筛；不适用设备有审查结论 | 课程闭环完成：220kV管母完成载流/热稳/简化弯曲/电晕，35/10kV母线完成载流/热稳；套管完成最高电压、LIWV、持续/短时/峰值检查；2×1000kVA与2×200kVA接地设备包、MOA、ZCT和ES已补齐。35/10kV母线机械、爬距、机械负荷、TOV/能量及精确厂家数据仍待复核 |
| R-07 | 编写技术设计说明书 | 页 3、8 | report/ 说明书 DOCX/PDF | 章节、表格、图号、引用和结论完整 | 完成：正式PDF 35页 A4，正文约1.33万字符、28个表格、32个编号公式，已补充方案论证、结果分析和工程边界；隐私、可访问性、审阅残留和逐页视觉终审 PASS |
| R-08 | 编写技术设计计算书 | 页 3、8 | report/ 计算书 DOCX/PDF | 每项结果可追溯到公式、输入和脚本 | 完成：正式PDF 29页 A4，正文约1.40万字符、19个表格、63个编号公式，关键计算均保留方法、代入、单位、结果和解释；逐页终审 PASS |
| R-09 | 计算各回路最大持续工作电流 | 页 3、8 | 回路电流表与计算文件 | 回路数、负荷分配、功率因数和电压一致 | 核心完成：含T10、SVG、10kV进线/母联职责 |
| R-10 | 计算三相短路电流 | 页 3、7-8 | 等值网络、标幺值表、短路结果表 | 100MVA 基准；关键母线和分段点齐全 | 课程模型完成：220kV控制职责为分列4.033kA/10.266kA、分段条件闭合7.385kA/18.798kA；电网单独3.607/6.500kA仅作分量；35/10kV及禁止并列敏感性齐全 |
| R-11 | 绘制电气主接线简图 | 页 3-4、8 | 公开 DXF/PDF/PNG；本地 DWG | 回路、设备、编号、CT/PT/ZCT、MOA、ES、接地设备包和联结组一致；35kV含两回T10电源变间隔；母联接地源联锁说明明确 | 完成：SLD-01已表达线路侧ES、架空MOA/电缆ZCT、接地变容量和母联转供接地源规则；重新生成后以语义校验、AutoCAD AUDIT和单页A1目检为发布门 |
| R-12 | 绘制配电装置断面图 | 页 3-4、8 | SEC-220-01与SEC-220-L1-01公开DXF/PDF/PNG；本地DWG | 设备尺寸、净距、标高、剖切位置、基础和接地接口可核查 | 完成：SEC-220-01 A1/1:100与SEC-220-L1-01 A1/1:50均通过语义校验、AUDIT和PDF/PNG目检 |
| R-13 | 绘制配电装置平面布置图 | 页 3-4、8 | 公开 DXF/PDF/PNG；本地 DWG | 间隔顺序、道路、出线方向和断面一致 | 完成：LAY-220-01 A1/1:200，AIS两段母线、间隔、道路、建筑和剖切线齐全，并通过语义校验、AUDIT和目检 |
| R-14 | 总结课题并准备答辩 | 页 3-4 | 总结、答辩提纲、关键问题表 | 能解释方案、公式、设备余量和图纸 | 完成：4页总结、11页答辩 PPTX/PDF 和7页问题清单；渲染、溢出、页数和公开元数据检查 PASS |
| R-15 | 文档一般手写、图纸一般手绘 | 页 4 | 三张必交图+一张增强详图的CAD工程底图与手绘临摹策略 | 四张CAD图完整可复核；用户按图手绘临摹 | 完成：四图已统一验证并冻结为临摹底图；用户后续按图手绘 |

## 验证边界

- 四份正式报告的正式PDF为35/29/4/7页，均已逐页审阅；DOCX已完成隐私、可访问性和审阅残留检查。
- 11 页答辩 PPTX/PDF 已完成逐页渲染、画布溢出、PDF 页数和元数据复核，清理前后渲染哈希一致。
- 四张A1图均已生成并完成统一验证：四份DWG的AutoCAD AUDIT均为0错误，DXF语义一致，PDF/PNG逐图目检通过。
- 当前树70项测试、68项健康检查、隐私扫描、计算结果再生成和四图DXF语义漂移检查均已重跑通过；远端由本次推送后的GitHub Actions再次复核。

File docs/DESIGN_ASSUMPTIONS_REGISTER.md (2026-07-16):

# 设计依据与假设台账

## 1. 分类规则

| 等级 | 含义 | 使用规则 |
| --- | --- | --- |
| A | 任务书或教师给定 | 不得被网络资料覆盖 |
| B | 现行标准、官方资料或本课程正式课件采用 | 记录版本、页码/链接和适用条件 |
| C | 课程设计假设 | 明确理由、保守性、影响和替换触发条件 |
| D | 最终待教师/真实场址复核 | 不阻塞课程底稿，但不得冒充施工设计条件 |

## 2. 已冻结输入

| ID | 项目 | 冻结值 | 等级 | 依据与理由 | 影响与替换条件 |
| --- | --- | --- | --- | --- | --- |
| A-001 | 题目与组别 | 第5组，220kV新能源汇集变电所电气一次部分初步设计 | A | 本组任务书 | 不变 |
| A-002 | 主变 | 2×180MVA，220/35kV，双绕组，`uk=14%`；课程联结组 `YNd11` | A/B/C | 容量、电压比来自任务书；阻抗按任务书允许值；联结组用于满足220kV中性点直接接地并使35kV侧采用独立接地变 | 教师或厂家参数覆盖阻抗与联结组 |
| A-003 | 220kV线路 | 本期2回、预留1回，LGJ-400/50，向西北出线 | A | 本组任务书 | 不变 |
| A-004 | 35kV集电线路 | 本期12回、预留2回，架空线与电缆混合，向东/南 | A | 本组任务书 | 不变 |
| A-005 | 自然温度 | 最高41℃、最低-12℃、年平均15℃ | A | 本组任务书 | 用于设备和导体环境校核 |
| B-001 | 220kV配电装置型式 | 户外AIS、分相中型布置 | B/C | 课程第七章说明110kV及以上通常采用屋外式；分相中型便于课程平断面表达 | 教师指定GIS或高型布置时重绘 |
| B-002 | 220kV屋外最小电气净距 | A1=1800mm，A2=2000mm，B1=2550mm，B2=1900mm，C=4300mm，D=3800mm | B/D | 本课程《第七章 配电装置》第13页表7-2的220J列；最终施工口径仍须按DL/T 5352-2018正文复核 | 作为课程CAD尺寸下限；标准正文核对值优先覆盖 |
| C-001 | 海拔 | `≤1000m`，按1000m上限校核 | C/D | 任务书缺失；采用高压设备常规使用条件，不进行高海拔修正 | 场址高于1000m时重做绝缘、净距和设备校核 |
| C-002 | 污秽等级 | d级（重污秽） | C/D | 任务书缺失；为新能源汇集站采用保守课程假设 | 设备外绝缘不低于d级；真实污区图或教师值覆盖 |
| C-003 | 220kV分段正常状态 | 正常断开 | C/D | 无调度并列许可和同期条件时避免系统1、系统2经本站并列 | 闭合只作条件性最大短路敏感性；调度许可可覆盖 |
| C-004 | 主保护动作时间 | 0.05s | C/D | 快速主保护课程统一假设 | 实际保护整定覆盖 |
| C-005 | 后备保护动作时间 | 1.00s | C/D | 偏保守课程统一假设 | 实际保护配合覆盖 |
| C-006 | 断路器固有分闸/全开断时间 | 0.04s / 0.08s | C/D | 课程预校核用暂定设备能力参数 | 精确型号厂家样本覆盖 |
| C-007 | 触头分离时刻 | 0.09s | C | 主保护0.05s加固有分闸0.04s | 用于开断时刻说明；初始短路电流预筛为保守上界 |
| C-008 | 热稳定计算时间 | 1.10s | C/D | 后备保护1.00s加全开断0.08s后向上取整 | 按 `I²t` 与设备额定短时耐受能力比较 |
| C-009 | 配电装置图范围 | 220kV户外AIS平面图A1 1:200；双典型间隔断面图A1 1:100；L1线路间隔详图A1 1:50 | C | 任务书未限定电压级、图幅、比例或张数；课程第七章说明断面图应按比例表达所取间隔，新增详图便于完整校核和手绘临摹 | 教师指定其他范围时调整 |
| C-010 | LGJ-400/50课程参考载流量 | 25℃参考592A；41℃修正系数0.802773；课程保守允许载流量475.242A | C/D | 本地课程温度公式与标注GB1179-83的旧版二手参数表；条件不完整，故只作保守课程参考 | 现行厂家在明确风速、日照和环境下的热额定值覆盖 |
| C-011 | LGJ-400/50 N-1结论 | 正常双回通过；单回独立承担全送出需限发35.390%；主变N-1限发35.780%略严，故总N-1仍由主变控制 | C/D | 475.242A对比367.780A/735.559A；主变限发后线路约472.377A | 厂家热额定值或运行限额覆盖 |
| C-012 | 220kV AIS平断面课程几何 | 站区145m×90m、道路4m、相间4m、典型功能中心14m；母线至线路构架29m、至主变构架20m、至主变中心27m；母线+9.0m、线路构架+14.5m、主变构架+11.5m | C/D | 为A1/1:200平面和A1/1:100断面建立同源、可临摹的几何基线 | 精确设备、基础、运输和厂家端子图覆盖 |
| C-013 | 35kV与10kV中性点接地方式 | 各分段按接地变压器加低电阻接地 | A/C | 任务书已规定35kV、10kV属于非直接接地系统；具体采用低电阻而非不接地或消弧线圈，是考虑多回电缆、快速选择性切除和限制暂态过电压的课程假设 | 教师口径、系统电容电流和保护专题覆盖 |
| C-014 | 中性点接地课程参数 | 35kV每段1套ZN接地变+低电阻，2×1000kVA、400A/10s、`R≈50.5Ω`；10kV每段1套，2×200kVA、200A/10s、`R≈28.9Ω` | C/D | 按 `R=Un/(√3Ig)` 取电阻，接地变容量按10s短时过载系数10形成可画图、可答辩的课程设备包 | 精确零序阻抗、损耗、温升、热容量、CT/NGR成套厂家参数和保护配合覆盖 |
| C-015 | 35kV馈线接口分配 | 7回风电线路按架空并在入口配置MOA；4回光伏与1回储能按电缆并配置零序CT | C/D | 任务书只给“架空线与电缆混合”；按场站距离和典型接入方式形成课程分配，用于MOA、零序CT和柜型配置 | 实际线路路径与场站接口资料覆盖 |
| C-016 | 变压器型式与联结组 | 主变、T10采用`YNd11`；所用变采用SCB14干式`Dyn11`、`uk=4%` | C/D | 使220/35/10/0.4kV接地路径自洽，并补齐任务书要求的所用变型式 | 厂家订货数据和教师口径覆盖 |
| B-003 | 无间隙金属氧化物避雷器课程系列 | 220kV `YH10W-204/532`；35kV `YH5WZ-51/134`；10kV `YH5WZ-17/45` | B/C/D | 220kV参数由国家电网采购规范与GB/T 11032系列核对；35/10kV采用课程常用站用型参数并做绝缘裕度校验 | 绝缘配合、TOV与能量专题及厂家样本覆盖 |
| C-017 | 220kV管母机械校核支撑跨距 | 8.0m；电动力校核相距取3.0m，不大于CAD布置4.0m | C/D | 8m为管母简化机械预校核的课程支撑跨距；3m相距比实际布置更不利，故用于保守电动力筛查 | 厂家支柱、金具、端部荷载、风冰震与共振计算覆盖 |
| C-018 | 35/10kV接地源母联联锁 | 正常每段1套；母联合闸前退出受电/故障段接地源，仅保留健康电源侧1套；禁止母联闭合且两套接地源并联；重新分列后恢复每段1套 | C/D | 避免两套低电阻接地源并联使目标接地故障电流和保护配合失去课程设定边界 | 最终硬接线/软件联锁、控制电源失效模式和保护跳闸矩阵由厂家与保护专业覆盖 |
| C-019 | 零序CT课程配置 | 35kV五回电缆馈线取100/1A；10kV两回SVG和三类电缆辅助馈线取50/1A | C/D | 零序CT承担剩余电流/单相接地保护，职责与三相相CT分开管理 | 电缆外径、窗口尺寸、屏蔽接地回路、负担、拐点和精确型号覆盖 |

## 3. 仍需工程专题覆盖的输入

| ID | 项目 | 当前方向 | 关闭条件 |
| --- | --- | --- | --- |
| P-004 | 220kV AIS设备外形及间隔尺寸 | 平断面已按共用课程几何基线完成；精确厂家外形、基础和端子方向仍待覆盖 | 精确型号厂家外形图到达后重出两图 |
| P-005 | 直击雷与接地网专题 | 课程图纸表达设备、构架和MOA接至站接地网；不虚构保护范围、接触电压或跨步电压 | 场址雷暴日、建筑高度、土壤电阻率与接地网几何齐全 |
| P-006 | CT/PT二次参数 | 已冻结一次变比量级、接线和用途；完整芯数、准确级组合、二次负荷与电缆压降仍需保护计量清册 | 二次系统与保护配置确定 |
| P-007 | 接地设备包与母联联锁 | 已冻结课程容量、电阻、电流、馈线等级、相/中性点CT目标和切换顺序 | 接地变/NGR厂家成套数据、接地故障计算、保护整定、联锁原理图和失效模式齐全 |

## 4. 使用声明

本台账服务于课程设计与手绘临摹底稿，不是现场施工设计输入。任何 A/B/C 类值被修改时，必须同步更新统一 YAML、计算结果、设备职责、四张图纸、说明书和项目日志。

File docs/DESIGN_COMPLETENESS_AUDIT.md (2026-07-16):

# 课程设计完整性复盘与补充决策

## 1. 审计目标

本次复盘以本组任务书为硬约束，以本地课程第六、七章课件、《发电厂变电所课程设计》学生指导书及现行标准台账为补充依据，对主接线、主要设备选择、过电压保护、接地、配电装置和图纸表达进行逐项核对。旧学生设计只用于识别内容范围，不直接继承其型号、数值或图形。

## 2. 关键结论

| 项目 | 任务书属性 | 复盘前状态 | 决策 |
| --- | --- | --- | --- |
| 避雷器 | 未逐字单列，但包含在“主要电气设备”工程完整性范围 | 220kV线路和主变已画MOA；35/10kV仅在报告中写原则 | 补35/10kV PT+MOA配置，并完成Ur、Uc、残压和绝缘裕度课程校验 |
| 接地开关 | 非独立硬项 | 主接线、平断面均未表达 | 220kV线路侧QS补常开ES；35/10kV柜内ES写入配置与联锁 |
| CT/PT | 任务书硬项 | 位置原则已完成，课程级一次参数不完整 | 冻结变比量级、一次/二次电压、接线和用途；完整二次负荷仍保留为工程边界 |
| 220kV短路职责 | 任务书计算项 | 文档混用电网单独贡献与含新能源课程上界 | 设备控制职责统一为分列4.033kA/10.266kA、分段条件闭合7.385kA/18.798kA；3.607/6.500kA仅保留为电网分量 |
| 中性点接地 | 任务书硬项 | 接地方式有文字，但接地变用纯接地符号表示，易误读 | 220kV直接接地并补中性点CT；35kV采用2×1000kVA、10kV采用2×200kVA的ZN接地变+低电阻课程设备包 |
| 接地源母联逻辑 | 工程完整性项 | 每段均画接地源，但未说明母联转供时如何避免两套并联 | 正常每段1套；母联合闸前退出受电/故障段接地源；禁止母联闭合且两套接地源并联；分列后恢复每段1套 |
| 母线/导体 | 任务书硬项 | CAD写管形母线，报告仍写“软导线或管母线待定” | 冻结220kV铝合金管形母线、35/10kV矩形母线；220kV完成载流、热稳、简化弯曲和电晕，35/10kV仅完成载流和热稳 |
| 绝缘子/穿墙套管 | 任务书参考目录明确期待 | 只有待复核边界 | 补最高电压、LIWV、套管持续电流、短时和峰值课程检查；爬距、机械破坏负荷及精确型号仍待厂家 |
| 35kV线路接口 | 任务书只给“架空+电缆混合” | 未分配到12回具体回路 | 风电7回按架空并在入口配置MOA；光伏4回与储能1回按电缆并配置零序CT，作为可替换课程假设 |
| 变压器联结组/所用变型式 | 任务书要求型式，未给联结组 | 容量、电压已定，联结组缺失 | 主变与T10取`YNd11`；所用变取SCB14干式`Dyn11` |
| 断面图 | 任务书硬项，未规定张数和比例 | 一张A1图含线路、主变两个典型断面 | 保留原图，新增A1 1:50 L1线路间隔详图，便于设备校核和手绘临摹 |

## 3. 避雷器与防雷边界

避雷器和避雷针不是同一设备。MOA用于限制线路、母线和变压器端的雷电/操作过电压；避雷针、构架避雷线用于直击雷保护。课程设计补齐MOA配置和绝缘配合，但不在缺少雷暴日、建筑高度和保护范围模型时虚构“避雷针已覆盖全站”。

课程选择采用：

- 220kV：`YH10W-204/532`，Ur=204kV、Uc=159kV、In=10kA、10kA雷电残压不大于532kV；
- 35kV：`YH5WZ-51/134`，Ur=51kV、Uc=40.8kV、In=5kA、残压不大于134kV；
- 10kV：`YH5WZ-17/45`，Ur=17kV、Uc=13.6kV、In=5kA、残压不大于45kV。

220kV参数已与国家电网220kV无间隙金属氧化物避雷器采购规范核对；35/10kV参数作为课程常用站用型参数，仍由最终TOV、能量和厂家样本覆盖。配置范围明确为：220kV线路入口和主变高压端，35kV母线PT柜、主变端及7回架空馈线入口，10kV母线PT柜和T10/SVG端。

## 4. 接地源、零序CT与母联联锁

- 35kV每段1套ZN接地变+低电阻，课程容量1000kVA/套，目标400A/10s、R≈50.5Ω；10kV每段1套，课程容量200kVA/套，目标200A/10s、R≈28.9Ω。容量按10s短时过载系数10形成课程假设，不能写成厂家订货型号。
- 正常分列时每个独立带电母线段各保留1套接地源。母联事故转供前先断开受电侧或故障侧接地源，仅保留健康电源侧1套；联锁禁止“母联闭合且两套接地源同时投入”。重新分列后再恢复每段各1套。
- 35kV五回电缆馈线单列零序CT，课程目标100/1A；10kV两回SVG及三类电缆辅助馈线单列零序CT，课程目标50/1A。零序CT承担剩余电流/单相接地保护，不套用三相CT职责。
- 两级接地变馈线均纳入1250A、31.5kA/4s、80kA峰值开关柜等级预筛；精确零序阻抗、CT负担、保护整定、联锁回路和厂家成套设计仍待专题闭合。

## 5. 新增线路间隔详图

新增图号 `SEC-220-L1-01`，图名“220kV I段L1线路间隔断面详图”，A1横向、比例1:50。设备链为：

`220kV I段管形母线 → 母线侧QS → QF → TA → 线路侧QS+ES → CVT → MOA → 出线构架`

详图同时表达基础、地下接地网、设备/构架接地、主要标高、水平尺寸、A1/A2/C类净距、设备编号和课程额定参数表。设备外形和基础仍以最终厂家图为准。

## 6. 已审查但不采用或不单独选型的项目

- **限流电抗器**：35kV与10kV最严允许运行方式下的课程短路电流水平均低于所选31.5kA开关设备能力，本方案不靠限流电抗器降低短路电流；若后续并列方式、SVG贡献或系统等值阻抗改变，应重新判定。
- **高压熔断器**：不作为35/10kV主回路开断设备。PT柜的一次熔断器及二次熔断器/小型断路器按柜内成套保护配置说明，不替代断路器职责。
- **阻波器**：只有在二次通信方案明确采用电力线载波时才配置；当前任务书未给通信制式，因此不画入一次主接线。
- **穿墙套管**：仅在裸母线或导体确实穿越建筑墙体的位置选用；当前220kV户外AIS线路间隔无此构造，不为凑齐设备表虚设套管。35/10kV成套柜和电缆终端按厂家柜体绝缘接口处理。

## 7. 不在本轮冒充完成的工程专题

- 直击雷保护范围、独立避雷针最终位置；
- 接地网电阻、接触电压和跨步电压；
- CT/PT完整二次负荷、保护芯暂态性能与电缆压降；
- MOA能量吸收、线路放电等级和完整TOV曲线；
- 35/10kV矩形母线电动力、支撑机械和厂家温升；
- 绝缘子/套管爬距、机械破坏负荷、端子荷载和精确厂家型号；
- 接地源硬接线/软件联锁、保护跳闸矩阵及接地变/NGR成套厂家协调；
- 厂家订货型号、基础荷载、端子荷载和施工放样尺寸。

这些边界不影响课程设计成果闭环，但在施工或设备订货前必须由真实场址、保护专题和厂家资料覆盖。

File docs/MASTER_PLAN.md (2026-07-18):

# 220kV 新能源汇集变电所课程设计总体计划

## 当前执行状态（2026-07-18）

| 阶段 | 当前状态 | 已形成证据或边界 |
| --- | --- | --- |
| P0-P4 | 课程设计基线完成 | 任务与公开边界、主接线、负荷/变压器、持续电流及 220/35/10kV 短路计算已闭环 |
| P5 | 课程设备闭环完成，工程定型待补 | 开关设备、变压器、三相CT/PT、零序CT、MOA、接地设备包和ES已纳入；220kV管母完成载流/热稳/简化弯曲/电晕，35/10kV母线仅完成载流/热稳；套管完成Um/LIWV/持续/短时/峰值课程检查，机械、爬距与厂家定型仍待复核 |
| P6 | 课程布置基线完成 | 220kV 户外 AIS、35/10kV 室内金属铠装开关柜及平断面共用几何基线已冻结 |
| P7 | 完成 | SLD-01、LAY-220-01、SEC-220-01与SEC-220-L1-01均已形成DXF/PDF/PNG；四图语义一致、AutoCAD AUDIT均为0错误，单页A1 PDF/PNG目检通过 |
| P8 | 完成 | 四份正式报告DOCX/PDF与11页答辩PPTX/PDF已形成；正式PDF为35/29/4/7页，其中说明书和计算书已补充正式论证、公式、代入与结果分析，并完成逐页视觉终审 |
| P9 | 当前树本地发布门通过 | 70项测试、68项健康检查、计算结果再生成、四图语义校验、Office/PDF元数据和当前树隐私检查通过；远端由每次推送触发GitHub Actions复核 |

## 1. 总体目标

在任务书截止窗口内完成 220/35/10kV 新能源汇集变电所电气一次部分初步设计。设计必须同时满足工程逻辑、课程格式、计算可复核、图纸一致和公开仓库合规五项要求。

当前日期为 2026-07-16，任务书截止日期为 2026-07-17。课程设计交付物已进入最终发布闭环；后续只允许修复验证发现的问题，不再无依据扩大工程定型范围。

## 2. 依赖关系

~~~mermaid
flowchart LR
    A[任务书与参数冻结] --> B[主接线方案比较]
    A --> C[负荷与主变配置]
    B --> D[回路与运行方式]
    C --> D
    D --> E[最大持续工作电流]
    D --> F[短路等值与短路电流]
    E --> G[设备选择与校验]
    F --> G
    G --> H[配电装置型式与尺寸]
    B --> I[主接线 CAD]
    G --> I
    H --> J[断面图与平面图 CAD]
    E --> K[说明书与计算书]
    F --> K
    G --> K
    I --> L[一致性审查]
    J --> L
    K --> L
    L --> M[最终交付与答辩]
~~~

## 3. 工作分解与验收标准

| 阶段 | 工作包 | 主要输入 | 主要输出 | 前置依赖 | 完成标准 |
| --- | --- | --- | --- | --- | --- |
| P0 | 项目治理与资料审计 | 全部本地文件 | 仓库结构、公开边界、设计输入、日志 | 无 | 私有材料未进入 Git；参数可追溯 |
| P1 | 任务与运行方式冻结 | 任务书、统一原则 | 决策清单、短路场景、图纸范围 | P0 | 未决问题有默认策略和责任人 |
| P2 | 主接线与变压器方案 | 回路数、负荷、可靠性要求 | 各电压等级候选方案、技术经济比较、最终方案 | P1 | 方案满足正常、检修、故障和扩建要求 |
| P3 | 负荷与持续电流计算 | 负荷表、功率因数、同时系数、线损 | 综合负荷、主变校验、各回路电流表 | P2 | 所有回路数和分配假设明确；单位统一 |
| P4 | 短路电流计算 | 系统容量、电抗、线路长度、变压器参数 | 标幺网络、计算点、三相短路结果和敏感性场景 | P2 | 100MVA 基准转换正确；关键母线/分段齐全 |
| P5 | 设备选择与校验 | P3、P4 结果、产品样本 | 开关设备、变压器、母线、三相CT/PT、零序CT、绝缘子/套管、MOA、接地设备包、ES及适用性结论 | P3、P4 | 课程目标有计算或边界；35/10kV母线机械等未完成项显式保留；工程定型项不冒充完成 |
| P6 | 配电装置设计 | 设备尺寸、净距、出线方向、环境 | 220/35/10kV 型式说明、间隔表、布置参数 | P5 | 型式与设备、气温、占地和检修条件匹配 |
| P7 | CAD 图纸 | P2、P5、P6 的统一数据 | 三张必交图+一张L1线路间隔增强详图的公开DXF/PDF/PNG，本地DWG | P5、P6 | 四图设备链、编号、间隔、净距和接地接口一致；无缺字 |
| P8 | 说明书与计算书 | 全部计算、决策、图纸 | 课程模板下的 DOCX/PDF | P3-P7 | 目录、公式、表格、图号、引用和结论完整 |
| P9 | 总审与答辩 | 全部交付物 | 检查报告、总结、答辩提纲和最终包 | P7、P8 | 追踪矩阵全覆盖；关键结论可口头解释 |

## 4. 分阶段执行细目

### P1 - 冻结任务与运行方式

1. 确认第 5 组题目和 220/35/10kV 系统范围。
2. 明确 220kV 两回在运、一回预留的本期与远期场景。
3. 明确 35kV 两段母线的馈线分配、母联运行方式和 N-1 限发策略。
4. 明确 10kV 系统是由主变第三绕组供电，还是由 35/10.5kV 辅助变压器供电；两种方案都要先做可行性核对。
5. 明确 0.4kV 所用电采用两台所用变、单母线分段、轮换暗备用；正常一台运行、母联闭合、另一台进线断开。
6. 将 110kV 通用负荷项标记为本题不适用，避免误计。
7. 决定主短路场景与敏感性场景：预留线投入/不投入、35kV 新能源贡献忽略/保守估算。
8. 冻结35kV接口：WA-1～4、WB-1～3按架空，PVA-1～2、PVB-1～2、ES-1按电缆；冻结各段接地变+低电阻的课程参数。

### P2 - 主接线与变压器方案

#### 220kV 侧

至少比较以下方案：

- 单母线分段：经济、清晰，但母线检修和故障影响范围较大；
- 双母线接线：运行灵活、检修便利，但设备多、占地和投资高；
- 必要时将带旁路或简化旁路作为课程比较项，而不是默认采用。

比较维度：回路数量、可靠性、检修方式、倒闸复杂度、扩建、占地、断路器数量和课程图纸可表达性。

#### 35kV 侧

以单母线分段的金属铠装开关柜方案为优先候选。两台主变分别接入两段，12 回本期集电线路和 2 回预留均衡分配；另在两段分别设置 `T10-1-HV`、`T10-2-HV` 电源变馈线间隔，设置母联并明确正常分列/并列方式。

#### 10kV 与 0.4kV

10kV 优先采用单母线分段，分别承载站用、无功补偿和辅助系统；0.4kV 按任务书采用三相四线制单母线分段，两台所用变轮换暗备用，正常一台运行并经闭合母联带两段。最终供电来源在 P1 冻结。

#### 变压器

- 计算每类 35kV 电源的视在功率并叠加 0.95 同时出力系数和 5% 线损。
- 校验 2×180MVA 的正常负载率、单台退出时的可送出比例和需要限发的容量。
- 对双绕组 220/35kV + 35/10.5kV 辅助变方案与三绕组主变方案进行结构、短路、运行和设备可得性比较。
- 所用变容量按全部经常负荷并留约 10% 裕度选择，短时负荷用于校验。
- 冻结主变2×180MVA、220/35kV、YNd11、uk=14%；T10 2×31.5MVA、35/10.5kV、YNd11、uk=8%；所用变2×200kVA、SCB14、Dyn11、uk=4%。

### P3 - 负荷与最大持续工作电流

统一使用以下计算链：

1. 单项视在功率：S_i = P_i / cosφ_i。
2. 35kV 综合汇集容量：各项 S_i 求和后乘 0.95，同时考虑 5% 线损。
3. 10kV 综合负荷：各项视在功率求和后乘 0.80，同时考虑 5% 线损。
4. 线路单回负荷按任务书给定回路数平均分配；计算书保留未取整值和最终设计值。
5. 三相回路电流：I = S / (sqrt(3) U)；最大持续工作电流所用系数必须说明来源。
6. 计算主变高、低压侧，220kV 线路，35kV 各类集电线路，35/10.5kV电源变馈线，10kV 各回路，母联和所用变回路电流；依赖未确认容量的职责必须显式保持待定。
7. 对 4% 年增长率进行远景敏感性说明，但不与本期设备额定值混写。

初步数量级校核：35kV 已装有功容量合计为 270MW；在逐项功率因数、0.95 同时出力和 5% 线损处理后，主变正常总负荷约处于 280MVA 量级。该值仅用于发现输入错误，正式结果以计算文件为准。

### P4 - 短路电流计算

1. 采用 100MVA 基准容量和 230/37/10.5kV 平均额定电压。
2. 系统电抗换算：X*_sys = x_c × S_B / S_i。
3. 线路电抗换算：X*_line = x × L × S_B / U_B^2。
4. 变压器电抗换算：X*_T = (u_k% / 100) × S_B / S_N；三绕组方案需先完成绕组电抗分解。
5. 至少设置 220kV 母线、35kV I/II 段及分段处、10kV I/II 段短路点；必要时增加设备端点。
6. 对最大运行方式计算三相短路初始对称电流、冲击电流和热效应所需量。
7. 主结果按新能源贡献忽略计算，保守场景按额定电流 1.1～1.2 倍补充，避免设备裕度判断偏乐观。
8. 用独立复算表或脚本进行一次基准值、串并联和单位检查。

### P5 - 设备选择与校验

每类设备至少核对：

- U_e >= U_n；
- I_e >= I_max；
- 断路器额定开断电流不小于计算短路电流；
- 额定峰值耐受电流不小于冲击电流；
- 短时耐受电流与持续时间满足热稳定；
- 环境温度、安装方式、海拔（任务书未给时不得擅自假定高海拔）和污秽条件适配。

设备范围：220kV SF6 断路器、隔离开关和线路侧接地开关，35kV/10kV开关柜及柜内接地开关，母线/导体、绝缘子和套管、三相CT、零序CT、PT/CVT、MOA、主变、T10、接地变+低电阻成套设备和所用变。

母线按适用范围校验长期载流、温度修正和热稳定；220kV管母补充简化弯曲与电晕。35/10kV矩形母线电动力、支撑机械、连接金具及厂家温升在输入不足时显式保持待复核，不得笼统宣称动稳定完成。所有最终型号必须有可追溯的厂家样本或可靠产品数据。

课程级选择同步包含负面结论：35/10kV条件短路职责低于31.5kA设备能力，当前不设限流电抗器；高压熔断器不作为主回路设备，只在PT柜按厂家方案设置；阻波器仅在通信专业确定采用电力载波时配置。

### P6 - 配电装置设计

- 220kV：比较户外 AIS 与 GIS。课程断面/平面表达优先考虑户外 AIS，但最终以可靠性、占地、气候、设备尺寸和教师要求为准。
- 35kV：优先室内金属铠装移开式开关柜，形成两段母线、母联、主变进线、12 回本期馈线、2 回T10电源变馈线和 2 回预留的间隔表。
- 10kV：室内开关柜，按站用、无功补偿、冷却及备用电源组织间隔。
- 35kV每段采用1000kVA ZN接地变+低电阻400A/10s、R≈50.5Ω；10kV每段采用200kVA、200A/10s、R≈28.9Ω。正常每段1套；母联合闸前退出受电/故障段接地源，禁止母联闭合且两套并联，分列后恢复每段1套。220kV线路侧QS配置常开ES，35/10kV柜内ES落实机械/电气联锁。
- 断面与平面必须使用同一设备外形尺寸、安全净距、间隔宽度、道路和出线方向参数。

### P7 - CAD 图纸

1. 建立 GB 图框、图层、线型、线宽、文字、标注和设备编号规范。
2. 建立断路器、隔离开关、CT、PT、避雷器、变压器、母线和接地符号块库。
3. 用结构化拓扑生成主接线简图，人工复核回路和设备配置。
4. 设备与净距冻结后绘制典型间隔断面图。
5. 按出线方向、间隔顺序、道路和检修要求绘制平面布置图。
6. 新增SEC-220-L1-01 A1/1:50线路间隔详图，表达管母→QS→QF→TA→QS+ES→CVT→MOA→构架、基础、接地接口和课程净距。
7. 通过 accoreconsole 批量检查图层、范围、字体、打印和格式。
8. 对四张最终 PDF/PNG 完成逐图目检和打印范围复核。
9. 交付可再生 DXF/数据、PDF 和 PNG 预览；本地保留可编辑的 2018 兼容 DWG。

### P8 - 说明书、计算书与答辩

说明书按任务书建议目录组织：原始资料、主接线、负荷与变压器、持续电流与短路结果、设备选择、配电装置、设备总表。计算书保留完整代入、单位和中间结果。图纸以附录或独立图册提交。

答辩材料至少覆盖：为什么选该主接线、2×180MVA 是否合理、N-1 如何处理、短路点为何这样选、断路器开断与动热稳定如何通过、为什么不设限流电抗器/主回路高压熔断器/阻波器、35kV 如何分段、四张图如何保持一致。

## 5. 冲刺日程

| 时间 | 主线任务 | 可并行任务 | 当日出口条件 |
| --- | --- | --- | --- |
| 7 月 15 日 | P1-P3：方案、负荷、变压器、持续电流框架 | 建立计算模板、设备资料清单、报告骨架 | 主接线候选与变压器路径冻结 |
| 7 月 16 日上午 | P4：短路等值与结果 | 搜集设备样本、建立 CAD 标准与块库 | 关键短路点结果复核通过 |
| 7 月 16 日下午 | P5-P6：设备校验、配电装置和间隔表 | 开始主接线 CAD、填充说明书 | 设备表和布置参数冻结 |
| 7 月 16 日晚至 17 日上午 | P7-P8：三张必交图+一张增强详图、说明书、计算书 | 答辩提纲、一致性检查 | 全部产物形成可审阅版本 |
| 7 月 17 日 | P9：总审、打印/手绘策略、最终交付 | GitHub 发布验证 | 追踪矩阵关闭，最终包可提交 |

## 6. 质量门槛

- 输入门：设计输入表与任务书逐项核对，无未解释的 110kV 或旧题参数。
- 计算门：两种独立方式复核关键负荷、标幺电抗和短路结果。
- 设备门：设备表中的每个额定值都能回指计算结果和产品数据。
- 图纸门：主接线、间隔表、断面和平面编号一致；无缺字、外部参照丢失或超图框内容。
- 文档门：公式编号、表图标题、单位、参考文献和附录完整；DOCX/PDF 逐页目检。
- 发布门：健康检查通过，私有材料与机器写入元数据的 DWG 未被跟踪，远端分支与本地一致。

当前门槛状态：

| 门槛 | 状态 |
| --- | --- |
| 输入门 | 通过：第 5 组任务及 220/35/10/0.4kV 范围已冻结 |
| 计算门 | 课程模型通过：负荷、持续电流、短路及设备等级结果可由脚本复算；工程精细模型仍保留边界 |
| 设备门 | 条件通过：课程等级预筛和 I²t 预校核完成；精确型号和环境适配待补 |
| 图纸门 | 通过：四张A1图完成DXF语义一致性检查、AutoCAD原生AUDIT（0错误）、PDF/PNG目检和可再生性测试 |
| 文档门 | 通过：正式PDF为35/29/4/7页，四份报告及11页答辩PPTX/PDF完成逐页终审、溢出和元数据复核；说明书与计算书已达到正式课程设计报告的叙述与计算深度 |
| 发布门 | 本地当前树通过：70项测试、68项健康检查、计算结果再生成、四图DXF语义检查、隐私/元数据检查和`git diff --check`纳入最终提交门；远端由推送后的GitHub Actions复核 |

## 7. 主要风险与缓解

| 风险 | 严重度 | 缓解措施 |
| --- | --- | --- |
| 截止时间紧，先画图导致返工 | 高 | 先冻结方案、设备和净距；CAD 数据驱动生成 |
| CAD 与手绘提交要求冲突 | 高 | 尽早确认；CAD 同时作为打印/临摹底稿 |
| 主变 10kV 供电路径不明确 | 高 | 对三绕组与 35/10.5kV 辅助变两案比较后冻结 |
| 参考设计沿用旧题 110kV 参数 | 高 | 输入文件只使用本题参数；自动检查禁用不适用项 |
| 短路贡献和预留线路场景不确定 | 中 | 主场景 + 保守敏感性场景并列报告 |
| 设备型号资料陈旧或不可追溯 | 高 | 优先厂家现行样本；记录来源与访问日期 |
| 旧 DWG 字体缺失、图形错位 | 中 | 不复用旧底图；统一字体和块库；PDF 目检 |
| 公开仓库泄露原始材料 | 高 | 允许清单、健康检查、逐文件暂存和远端核验 |

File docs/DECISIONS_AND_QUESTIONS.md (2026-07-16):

# 设计决策与待确认事项

## 已作出的项目级决策

| 编号 | 决策 | 理由 | 状态 |
| --- | --- | --- | --- |
| D-001 | 当前任务按第 5 组“220kV 新能源汇集变电所”执行 | 任务书标题与九组任务包中的第 5 组一致 | 已确认 |
| D-002 | 采用公开成果允许清单，原始资料全部本地私有 | 避免第三方版权、个人信息和团队权属风险 | 已执行 |
| D-003 | 仓库暂不附统一开放许可证 | 原创与第三方材料的权利边界尚未最终拆分 | 已执行 |
| D-004 | CAD 采用“结构化数据 -> DXF/DWG -> 核心控制台校核 -> PDF/PNG渲染目检” | 可复现、便于版本控制，并保证三张必交图和一张增强详图参数一致 | 已执行 |
| D-005 | 参考 DWG 只用于理解，不作为最终底图 | 旧图字体缺失、版权不明，且不匹配本题参数 | 已确认 |
| D-006 | 主接线和设备型号在技术经济比较与计算完成前不提前定稿 | 防止图纸、报告和计算发生返工 | 已确认 |
| D-007 | 主变容量主校核按35kV汇集负荷，10kV负荷作为保守敏感性场景 | 符合任务书“按汇集容量校验”口径，同时保留供电路径未冻结的不确定性 | 已确认 |
| D-008 | 所用变采用2×200kVA、10/0.4kV、SCB14干式、Dyn11、uk=4%，轮换暗备用；正常一台运行、0.4kV母联闭合、另一台进线断开 | 连续/经常负荷、10%裕度和0.80功率因数保守校核均落在200kVA以内；学生指导书第9页明确正常仅一台所用变运行 | 课程设计冻结值，精确型号待厂家覆盖 |
| D-009 | 220kV采用单母线分段、不设旁路；35/10/0.4kV采用单母线两分段 | 当前回路规模下兼顾可靠性、经济性、扩建和课程图纸可表达性 | 基线冻结 |
| D-010 | 主变采用220/35kV双绕组，10kV由两台35/10.5kV电源变供电 | 任务书阻抗齐全，独立T10可限制10kV短路电流并便于事故切换 | 基线冻结 |
| D-011 | 设备选择采用“职责注册表—场景门控—候选证据”三层结构 | 防止把全站总电流、禁止运行方式、缺失值或厂家家族上限误当成精确设备结论 | 已执行 |
| D-012 | 35kV进线/母联按3150A、馈线按1250A、全系统按31.5kA等级预筛 | 3117.691A主变回路和16.291kA条件性RMS上界可被覆盖；进线仅余32.309A，必须依赖室内≤40℃控制及厂家温升确认 | 条件性预筛，不是最终订货选型 |
| D-013 | 35kV-I、II段分别设置T10-1-HV、T10-2-HV电源变馈线间隔 | 两台35/10.5kV电源变必须具有独立、可保护和可隔离的35kV电源回路 | 拓扑和545.596A职责已冻结 |
| D-014 | CAD图按完整工程底图继续绘制，最终由用户手绘临摹 | 用户已明确确认；既满足可复核和持续修改，也符合任务书手绘提交口径 | 已确认 |
| D-015 | 10kV采用2×±12Mvar SVG，T10采用2×31.5MVA、35/10.5kV、uk=8% | 目标功率因数0.98时保守所需21.8875Mvar，取24Mvar有9.65%裕度；T10 N-1最严负载率79.17% | 课程设计冻结值，待专题与精确型号覆盖 |
| D-016 | 220kV分段正常断开，闭合仅作调度许可下的条件性最大方式 | 无调度并列许可和同期条件时不得把系统1、系统2经本站长期并列 | 已冻结 |
| D-017 | 海拔按≤1000m、污秽按d级；热稳定按1.10s；平断面优先画220kV户外AIS | 任务书缺项，采用可替换的保守课程设计假设继续完成计算和CAD | 已冻结，教师/真实场址数据优先覆盖 |
| D-018 | LGJ-400/50按41℃课程保守载流量475.242A校核 | 592A旧表基准经课程公式修正；正常双回通过，单回需限发35.390%，但主变N-1限发35.780%略严 | 课程结论冻结，厂家热额定值待覆盖 |
| D-019 | 主变、T10联结组取YNd11；35kV采用2×1000kVA、10kV采用2×200kVA的ZN接地变+低电阻课程设备包 | 使220kV直接接地、35/10kV非直接接地路径自洽；课程值分别取400A/10s、50.5Ω和200A/10s、28.9Ω，容量按10s短时过载系数10形成假设 | 课程设计冻结值；精确零序阻抗、热容量、损耗、温升及厂家成套参数待覆盖 |
| D-020 | 220/35/10kV配置MOA，220kV线路侧和35/10kV柜内配置接地开关；电缆回路另配零序CT | 7回35kV架空入口需MOA，5回35kV电缆及10kV电缆/SVG回路需零序CT，才能完整表达过电压、单相接地保护和检修接地 | 课程配置完成；TOV、能量、零序CT负担/窗口和感应电流开合等级待专题 |
| D-021 | 保留SEC-220-01双典型断面，并新增SEC-220-L1-01 A1/1:50线路间隔详图 | 放大表达QS+ES、QF、TA、CVT、MOA、基础、接地、标高和净距，便于校核及手绘临摹 | 已完成并通过AutoCAD AUDIT与PDF/PNG目检 |
| D-022 | 35/10kV不设限流电抗器；高压熔断器不作为主回路设备 | 条件性短路16.291/15.638kA低于31.5kA设备能力；熔断器只作为PT柜厂家成套保护项 | 已审查并记录不采用判据 |
| D-023 | 35/10kV母联转供前退出受电/故障段接地源，只保留健康电源侧1套 | 两套低电阻接地源并联会改变接地故障电流和保护配合；正常分列时仍需每个独立带电段各有1套接地源 | 联锁禁止母联闭合且两套接地源同时投入；重新分列后恢复每段1套 |
| D-024 | 母线与绝缘校验按实际完成度表述 | 220kV管母已完成载流、热稳、简化弯曲和电晕；35/10kV矩形母线仅完成载流/热稳；套管已做持续、短时和峰值课程检查 | 不宣称35/10kV机械动稳定、爬距和机械破坏负荷已完成 |

## 待确认事项

| 优先级 | 问题 | 不确认的影响 | 默认处理 |
| --- | --- | --- | --- |
| 高 | 组员姓名、学号、分工与共同成果公开授权 | 影响封面、签字和公开范围 | 公开版本持续脱敏，提交版最后填写 |
| 中 | 教师是否要求平断面另覆盖35kV或10kV室内开关柜 | 可能增加一张附加图 | 必交两张先按220kV AIS完成；35/10kV在总平面表示配电楼并保留柜列方案 |
| 中 | 第三回 220kV 预留线路是否参与本期最大运行方式短路计算 | 影响 220kV 等值电抗 | 本期不投入，远期场景单列敏感性计算 |
| 中 | LGJ-400/50现行厂家在明确风速、日照和环境下的热额定值 | 决定是否可放宽课程保守限额 | 当前按475.242A保守值；不采用条件不明的735/800/835/922A搜索摘要 |
| 中 | 35kV开关柜精确厂家、型号、3150A配置与安装外形图 | 决定室内≤40℃温升、柜体尺寸、泄压和CAD平断面 | 暂按目标等级预筛，不采用网页与目录冲突的3150A声明定稿 |
| 中 | SVG/T10与10kV开关柜精确厂家型号、谐波与变流器短路模型 | 决定最终产品；室外设备按41℃、室内柜按≤40℃复核 | 当前2×12Mvar、2×31.5MVA、2500A进线及31.5kA等级作为课程冻结基线 |
| 中 | CT/PT保护、计量、同期和自动装置二次清册 | 决定负担、饱和、拐点、暂态级、电缆压降和最终型号 | 一次变比、芯级/准确级目标已冻结；精确二次参数保持pending |

## 任务书中的一致性问题

所用电负荷表含 110kV 配电装置电源和 110kV 断路器加热，但本项目电压等级为 220/35/10kV。除非指导教师另有说明，这两项在本题所用电容量计算中标记为“不适用”，并在计算书中解释。

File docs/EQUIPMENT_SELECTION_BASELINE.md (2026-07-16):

# 主要电气设备选择与校验基线

## 1. 当前结论

本阶段已完成“回路职责 + 额定值等级 + 1.10s热效应 + 课程级补充设备”的预筛闭环，覆盖开关设备、变压器、母线、三相CT/PT、零序CT、绝缘子/套管、MOA、接地变+低电阻和接地开关，但不等于厂家精确订货定型。220kV管母已完成载流、热稳、简化弯曲及电晕课程预筛；35/10kV矩形母线仅完成载流和热稳，电动力、支撑机械与厂家温升仍待复核。绝缘子/套管已完成最高电压、LIWV、套管持续电流、短时及峰值课程检查，爬距和机械破坏负荷仍为 `pending`。凡仍缺少室外41℃或室内受控≤40℃厂家适配、完整二次负荷、TOV/能量、精确变流器模型、标准完整短路计算或厂家页级证据的项目，最终工程状态保持 `pending`。

任务书要求的设备章至少覆盖：高压断路器、隔离开关、母线、绝缘子与穿墙套管、电流互感器、电压互感器、配电装置及主要设备结果总表。依据本地私有《本组任务书.pdf》第2、7、8页。

统一校验链为：

- 额定电压：设备额定电压等级不低于系统要求；
- 持续电流：额定电流或环境修正后允许电流不小于最大持续工作电流；
- 断路器开断：额定短路开断电流不小于触头分离时的短路全电流有效值；
- 关合与动稳定：额定关合电流、峰值耐受电流不小于短路峰值；
- 热稳定：设备允许的短时耐受热量不小于短路等值热效应；
- 环境：复核最高温度、海拔、污秽、安装位置及厂家特殊使用条件。

课程公式及边界核对自本地私有《发电电气部分-第六章-导体和电气设备的选择与原理.pdf》第3-10、80-83、92-94、133-151页。旧指导书中的历史型号、价格和例题数值均不作为本项目输入。

## 2. 变压器与35kV线路接口冻结值

| 设备/接口 | 课程采用值 | 说明 |
| --- | --- | --- |
| 主变 T1/T2 | 2×180MVA、220/35kV、YNd11、uk=14% | 220kV星形中性点经中性点CT直接接地，35kV三角形绕组 |
| T10-1/T10-2 | 2×31.5MVA、35/10.5kV、YNd11、uk=8% | 分别由35kV-I/II段供电，健康T10禁止经10kV母联并列 |
| 所用变 TS1/TS2 | 2×200kVA、10/0.4kV、SCB14干式、Dyn11、uk=4% | 轮换暗备用；正常一台运行，0.4kV母联闭合 |
| 35kV架空接口 | WA-1～WA-4、WB-1～WB-3 | 共7回风电线路，按架空入口配置MOA及线路保护接口 |
| 35kV电缆接口 | PVA-1～PVA-2、PVB-1～PVB-2、ES-1 | 共5回光伏/储能线路，柜内配置接地开关与零序CT |
| 35kV接地设备包 | 2×1000kVA、ZN接地变+低电阻 | 每段1套；400A/10s、R≈50.5Ω；馈线按1250A柜、600/1A相CT和400/1A中性点CT课程配置 |
| 10kV接地设备包 | 2×200kVA、ZN接地变+低电阻 | 每段1套；200A/10s、R≈28.9Ω；馈线按1250A柜、300/1A相CT和200/1A中性点CT课程配置 |

## 3. 已生成的回路职责

| 回路 | 最大持续工作电流 | 采用口径 |
| --- | ---: | --- |
| 220kV线路间隔 | 735.559A | 一回线路退出，另一回承担全部本期汇集负荷 |
| 主变220kV侧 | 495.996A | 180MVA额定电流乘课程1.05系数 |
| 主变35kV侧、35kV母联预筛 | 3117.691A | 180MVA额定电流乘课程1.05系数 |
| 35kV-I段实际馈线分配基础值 | 2230.732A | 按I段6回馈线逐回累加，不使用简单均分 |
| 35kV-II段实际馈线分配基础值 | 2404.371A | 按II段6回馈线逐回累加，不使用简单均分 |
| 35kV单回馈线最大值 | 546.963A | 储能电站单回，含5%线损，不重复叠加同时系数 |
| 35kV至T10-1/T10-2馈线 | 545.596A | 31.5MVA T10额定电流乘1.05 |
| 10kV T10进线及母联 | 1909.586A | 31.5MVA按10kV设备口径并乘1.05 |
| 10kV SVG馈线 | 692.820A | 单套12Mvar按10.5kV额定电流乘1.05 |
| 10kV三类辅助负荷馈线 | 57.056/42.792/26.943A | 负荷自身最大值计5%线损 |
| LGJ-400/50课程载流量 | 41℃修正475.242A | 正常每回367.780A通过；单回735.559A需限发35.390%，主变N-1限发35.780%略严 |

220kV分段设备按“一段事故转供全部本期送出功率”的课程保守场景冻结持续职责735.559A。该值服务于课程等级选择，不等同于最终潮流分布；第三回线路投运、母线保护分区和调度转供方案明确后仍须复核。

## 4. 短路职责分级

| 场景 | RMS职责 | 峰值职责 | 用途 |
| --- | ---: | ---: | --- |
| 220kV分列必选方式 | 4.033kA，含新能源课程上界 | 10.266kA | 正常分列方式控制职责；电网单独贡献3.607kA仅作分量说明 |
| 220kV分段闭合条件性方式 | 7.385kA，含新能源课程上界 | 18.798kA | 条件性最大预校核；电网单独贡献6.500/16.546kA不是最终控制职责 |
| 35kV分列必选方式 | 13.265kA，含新能源RMS上界 | 峰值模型未完整 | 正常允许方式 |
| 35kV上游分段闭合条件性方式 | 16.291kA，含新能源RMS上界 | 课程敏感性41.470kA | 当前额定值预筛控制场景 |
| 两台健康主变低压侧并列 | 25.694kA，含新能源RMS上界 | 课程敏感性65.406kA | 基线禁止，仅用于提示联锁与误操作风险 |

课程敏感性峰值按固定k作用于保守RMS上界得到，只用于额定值预筛，不能替代现行标准下的R/X、直流分量和变流器动态模型。220kV已计新能源RMS课程上界，但精确动态、衰减、相位和峰值模型尚未建立，因此开断与动稳定仍不是最终值。

## 5. 目标额定值等级

| 设备用途 | 目标等级 | 当前证据状态 | 结论 |
| --- | --- | --- | --- |
| 220kV户外SF6断路器 | 252kV、3150A、50kA开断、125kA关合/峰值、50kA/3s | 仅为目标等级；CHINT LW43-252官方页面证明252kV户外SF6活罐式家族存在，未公开核实所列电流组合 | 数值预筛通过，型号和参数待厂家样本 |
| 220kV隔离开关 | 252kV、3150A、125kA峰值、50kA/3s | 尚无精确厂家候选证据 | 只作目标等级，不得写成已选型号 |
| 35kV主变进线、母联开关柜 | 40.5kV、3150A、31.5kA、80kA峰值 | Siemens NXAirS官方页面证明最高3150A/31.5kA家族可得；峰值和持续时间待精确样本 | 余量仅32.309A，约1.04%；必须依赖室内受控≤40℃及厂家温升确认，保持待定 |
| 35kV馈线开关柜 | 40.5kV、1250A、31.5kA、80kA峰值、31.5kA/4s | CHINT KYN61-40.5(Z)官方目录第22页提供家族参数 | 家族级数值预筛通过，精确柜型和订单配置待定 |
| 35kV接地变馈线柜 | 40.5kV、1250A、31.5kA、80kA峰值、31.5kA/4s | 与35kV馈线柜共用课程等级 | 覆盖400A课程馈线职责；接地变、NGR、CT和保护须成套协调 |
| 10kV T10进线、母联开关柜 | 12kV、2500A、31.5kA、80kA峰值、31.5kA/4s | 目标等级；厂家家族可得性已登记 | 相对1909.586A余590.414A；按室内受控≤40℃，精确柜型和厂家温升待定 |
| 10kV SVG及辅助负荷馈线 | 12kV、1250A、31.5kA、80kA峰值、31.5kA/4s | 目标等级；厂家家族可得性已登记 | 数值与1.10s I²t预筛通过，精确柜型待定 |
| 10kV接地变馈线柜 | 12kV、1250A、31.5kA、80kA峰值、31.5kA/4s | 与10kV馈线柜共用课程等级 | 覆盖200A课程馈线职责；接地变、NGR、CT和保护须成套协调 |

官方可访问证据：

- [CHINT LW43-252官方产品页](https://www.chintglobal.com/global/en/products/power-transmission-and-distribution/transmission/lw43-252.html)
- [Hitachi Energy LTB E官方产品页](https://www.hitachienergy.com/products-and-solutions/high-voltage-switchgear-and-breakers/air-insulated-switchgear/live-tank-circuit-breaker-ltb-e-72-5-800-kv)
- [CHINT KYN61-40.5(Z)官方目录](https://www.chintglobal.com/content/dam/chint/global/product-center/power-transmission-and-distribution/distribution/mv-switchgear/mv-air-insulated-switchgear/kyn61-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)
- [Siemens NXAirS官方页面](https://www.siemens.com/zh-cn/products/energy-systems/nxairs/)

目标等级与厂家家族证据分开管理。一个家族“最高可到某额定值”不能证明本项目所需组合已经形成精确订单型号。

## 6. CT/PT课程级配置

### 6.1 电流互感器

| 安装位置 | 课程变比 | 课程芯级组合 | 短时/峰值等级 |
| --- | --- | --- | --- |
| 220kV线路 | 1000/1A | 0.2S计量、0.5测量、5P30保护，按需要设PX差动 | 50kA/3s、125kA峰值 |
| 220kV主变回路 | 600/1A | 0.2S、0.5、5P30、PX差动 | 50kA/3s、125kA峰值 |
| 220kV主变中性点 | 600/1A | PX限制接地故障保护、5P30中性点过流 | 单相接地/零序专题待定，不沿用三相回路职责 |
| 220kV分段 | 1000/1A | 0.5测量、5P30母线保护、PX母差 | 50kA/3s、125kA峰值 |
| 35kV主变进线/母联 | 4000/1A | 0.2S、0.5、5P30、PX差动 | 31.5kA/4s、80kA峰值 |
| 35kV馈线/T10 | 800/1A | 0.2S、0.5、5P30 | 31.5kA/4s、80kA峰值 |
| 10kV进线/母联 | 2500/1A | 0.2S、0.5、5P30、PX差动 | 31.5kA/4s、80kA峰值 |
| 10kV馈线/SVG | 1000/1A | 0.2S、0.5、5P30 | 31.5kA/4s、80kA峰值 |

### 6.2 零序电流互感器

| 安装范围 | 数量/覆盖回路 | 课程变比与目标 | 安装边界 |
| --- | --- | --- | --- |
| 35kV电缆馈线 | 5套：PVA-1/2、PVB-1/2、ES-1 | 100/1A；一次剩余电流目标400A；5P20或厂家等效零序保护级 | 三相电缆芯线同穿窗口，屏蔽接地回流线不得穿入；窗口、负担和拐点待精确电缆/厂家核对 |
| 10kV电缆馈线/SVG | 5套：SVG-1/2及三类辅助负荷馈线 | 50/1A；一次剩余电流目标200A；5P20或厂家等效零序保护级 | 三相电缆芯线同穿窗口，屏蔽接地回流线不得穿入；窗口、负担和拐点待精确电缆/厂家核对 |

零序CT单列是为了承担单相接地/剩余电流保护，不能把三相相CT的额定电流、动热稳定职责直接套用为零序CT职责。

### 6.3 电压互感器

| 电压级 | 课程配置 | 二次绕组与准确级目标 |
| --- | --- | --- |
| 220kV | 每段单相CVT组，220/√3kV | 100/√3V测量、100/√3V保护、100/3V开口三角；0.2、3P |
| 35kV | 每段三台单相电磁式VT，35/√3kV | 100/√3V测量、100/√3V保护、100/3V开口三角；0.5、3P |
| 10kV | 每段三台单相电磁式VT，10/√3kV | 100/√3V测量、100/√3V保护、100/3V开口三角；0.5、3P |

上述为课程目标配置，不是订货规范。CT负担、饱和、拐点电压、暂态级和电缆压降，以及PT/CVT容量、铁磁谐振、同期抽取和精确型号仍需保护计量清册与厂家设计闭合。

已核验但尚未定型的220kV家族参考包括：[CHINT LB-35~275 CT](https://www.chintglobal.com/global/en/products/power-transmission-and-distribution/transmission/lb-35~275.html)、[CHINT LVB-35~275 CT](https://www.chintglobal.com/global/en/products/power-transmission-and-distribution/transmission/lvb-35~275.html)、[CHINT TYD-35~220 CVT](https://www.chintglobal.com/global/en/products/power-transmission-and-distribution/transmission/tyd-35~220.html)和[CHINT JDCF-66~220 VT](https://www.chintglobal.com/global/en/products/power-transmission-and-distribution/transmission/jdcf-66~220.html)。这些公开页面未提供本项目所需的完整变比、芯数、准确级、额定负荷和暂态保护参数，只能证明产品家族范围。

## 7. 母线、绝缘子/套管与MOA课程级选择

### 7.1 母线

| 电压级 | 课程选择 | 主要课程校验 |
| --- | --- | --- |
| 220kV | 铝合金管形母线Φ100/90mm | 41℃修正允许电流1605.546A＞735.559A；1.10s热稳定允许123.785kA＞7.385kA；简化弯曲应力10.048MPa＜70MPa；电晕起始相电压330.444kV＞最高运行相电压145.492kV |
| 35kV | 每相3×125×10mm矩形铝母线 | 课程表载流量4194A＞3117.691A；1.10s热稳定允许311.067kA＞16.291kA |
| 10kV | 每相2×125×10mm矩形铝母线 | 课程表载流量3282A＞1909.586A；1.10s热稳定允许207.378kA＞15.638kA |

220kV管母已完成载流、热稳、简化弯曲和电晕课程预筛；支撑共振、连接金具、温升、无线电干扰和精确厂家机械参数仍属于最终工程复核。35/10kV矩形母线当前只完成载流和热稳，不得表述为机械动稳定已完成；电动力、支撑绝缘子受力、连接金具和厂家温升仍待复核。

### 7.2 绝缘子与套管

| 电压级 | 最高电压/雷电冲击耐受 | 套管持续/短时/峰值课程目标 | 课程用途与边界 |
| --- | --- | --- | --- |
| 220kV | 252kV/950kV | 630A；50kA/3s；125kA峰值 | 户外支柱绝缘子及主变套管，按d级污秽提出目标；爬距和机械破坏负荷待厂家型号 |
| 35kV | 40.5kV/185kV | 4000A；31.5kA/4s；80kA峰值 | 室内支撑绝缘子及主变/开关柜套管；户外接口按d级污秽，机械及安装图待核 |
| 10kV | 12kV/75kV | 2500A；31.5kA/4s；80kA峰值 | 室内支撑绝缘子及T10/开关柜套管；户外接口按d级污秽，机械及安装图待核 |

当前35/10kV方案没有裸母线直接穿墙，独立裸母线穿墙套管不作为单列设备；若最终改为裸母线穿墙，则按持续电流、短路动热稳定、爬距和厂家安装图重新选择。

### 7.3 无间隙金属氧化物避雷器

| 电压级 | 课程型号 | Ur/Uc/In/雷电残压 | 课程绝缘裕度 |
| --- | --- | --- | --- |
| 220kV | YH10W-204/532 | 204kV/159kV/10kA/≤532kV | Uc比Um/√3余13.508kV；950/532=1.786＞1.15 |
| 35kV | YH5WZ-51/134 | 51kV/40.8kV/5kA/≤134kV | Uc比40.5kV仅余0.300kV（约0.74%）；185/134=1.381＞1.15 |
| 10kV | YH5WZ-17/45 | 17kV/13.6kV/5kA/≤45kV | Uc比12kV余1.600kV；75/45=1.667＞1.15 |

220kV MOA布置在线路入口和主变高压端；35kV布置在母线PT柜、主变端及7回架空馈线入口；10kV布置在母线PT柜和T10/SVG端。上述仅完成持续运行电压与LIWV/残压课程预筛；其中35kV Uc余量仅约0.74%，必须专项复核接地方式、10s TOV、能量吸收和引线压降。线路放电等级与精确厂家型号同样待专题覆盖。可得性参考为[CHINT YH10W家族](https://www.chintglobal.com/global/en/products/power-transmission-and-distribution/transmission/yh10w.html)和[Hitachi Energy PEXLIM](https://www.hitachienergy.com/products-and-solutions/surge-arresters/high-voltage-surge-arresters/silicone-housed-surge-arrester-pexlim)。

## 8. 中性点接地、接地开关与适用性结论

### 8.1 中性点接地与接地开关

- 220kV主变星形中性点经600/1A专用中性点CT直接接地。
- 35kV每段采用1套ZN接地变+低电阻，课程设备包为2×1000kVA、400A/10s、R≈50.5Ω；10kV每段为2×200kVA、200A/10s、R≈28.9Ω。10s容量按短时过载系数10形成课程假设，精确零序阻抗、损耗、温升和热容量仍待厂家协调。
- 正常分列时每个独立母线段各投入1套接地源；母联转供前先退出受电侧/故障侧接地源，只保留健康电源侧1套。联锁禁止“母联闭合且两套接地源同时投入”；重新分列后再恢复每段各1套。
- 35kV和10kV接地变馈线均按1250A开关柜、31.5kA/4s和80kA峰值课程等级预筛；相CT分别取600/1A、300/1A，中性点CT分别取400/1A、200/1A。
- 220kV线路侧配置常开ES，课程等级252kV、50kA/3s、125kA峰值；线路感应电流开合能力待厂家专用等级。
- 35kV与10kV开关柜内ES分别按40.5kV和12kV、31.5kA/4s、80kA峰值提出课程目标，并与断路器、隔离位置及带电显示设置机械/电气联锁。

接地变、低电阻和ES的课程参数不等于接地网已完成。土壤电阻率、接地网电阻、接触电压、跨步电压和单相接地保护配合仍须真实场址专题闭合。

### 8.2 已审查但不适用或暂不配置

| 设备 | 结论 | 依据与复核触发条件 |
| --- | --- | --- |
| 限流电抗器 | 当前35kV 16.291kA、10kV 15.638kA均低于所选31.5kA开关设备能力，课程方案不设 | 最终电网、变流器或允许并列方式使短路职责超过31.5kA时重审 |
| 高压熔断器 | 不作为主回路设备 | 仅在35/10kV PT柜按厂家方案设置一次熔断器及二次保护，型号、整定和选择性由VT柜设计确定 |
| 阻波器 | 当前不配置 | 仅在通信专业确定采用电力线载波通信及相应耦合方案时配置 |

## 9. 必须补齐后才能转为最终选型

1. 室外主变/T10/可能的户外SVG及LGJ-400/50按41℃复核，35/10kV室内开关柜和柜内母线统一按受控≤40℃复核；LGJ当前仅按475.242A课程保守参考闭环；
2. 220kV分段断路器精确潮流及第三回线路远期运行方式；
3. 按GB/T 15544.1-2023复核R/X、电压系数、触头分离电流与峰值；
4. 新能源变流器、SVG和必要的电动机反馈及衰减模型；
5. 厂家精确型号、正式样本版本、页码、室外41℃/室内受控≤40℃服务条件、d级外绝缘和外形安装图；
6. SVG无功电压/谐波专题及T10精确损耗、温升和接地参数；
7. CT/PT二次负荷、保护与计量准确级、同期和自动装置清册；
8. 接地故障、接地源切换联锁、接地网、接触/跨步电压与接地开关感应电流开合专题；
9. 35/10kV母线电动力和支撑机械、绝缘子/套管爬距与机械破坏负荷，以及避雷器TOV/能量和精确厂家参数；
10. 第四张SEC-220-L1-01详图中的设备外形、基础荷载和端子方向由最终厂家图覆盖。

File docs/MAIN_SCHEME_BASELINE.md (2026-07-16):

# 电气主接线与变压器配置基线

## 结论

本项目先按以下基线进入短路计算、设备选择和 CAD：

| 电压等级 | 基线方案 | 正常母联状态 |
| --- | --- | --- |
| 220kV | 单母线分段，不设旁路母线 | 正常断开；仅调度许可并经同期检查后条件闭合 |
| 35kV | 单母线两分段，室内金属铠装移开式开关柜 | 断开 |
| 10kV | 单母线两分段，由2×31.5MVA、35/10.5kV电源变分别供电，每段1套±12Mvar SVG | 断开 |
| 0.4kV | 单母线分段，两台 10/0.4kV 所用变轮换暗备用 | 一台所用变运行时闭合 |
| 主变 | 2×180MVA、220/35kV 双绕组、`YNd11`、油浸、有载调压、户外 | 两台正常运行 |

该结论为“课程设计冻结基线”，不是现场施工定值。只有指导教师口径、无功电压/谐波专题、真实场址条件或已核验设备参数改变设计基础时才修改，并同步更新计算、图纸和决策记录。

## 220kV 方案比较

| 方案 | 优点 | 主要问题 | 结论 |
| --- | --- | --- | --- |
| 内桥 | 两线两变时断路器少、经济 | 第三回线路扩建改造大；运行灵活性和可靠性较低 | 作为比较方案，不采用 |
| 单母线分段 | 清晰、经济；母线故障限制在一段；便于预留第三回线 | 一段检修会退出该段线路和主变 | 当前推荐 |
| 双母线不带旁路 | 母线检修灵活、扩建方便、可靠性高 | 隔离开关多、占地与投资大、倒闸复杂 | 教师提出更高可靠性时升级 |

现代 SF6 断路器可靠性和检修周期较高，本题无需默认设置旁路母线。

## 35kV 分段与馈线分配

两台主变各接一段，母联正常断开。12 回本期集电线路按 6+6 分配，2 回预留按 1+1 设置：

| 母线段 | 本期馈线 | 有功容量/MW | 预留 |
| --- | --- | ---: | ---: |
| 35kV-I | 风A 1-2、风B 1-2（架空）；光A-1、光B-1（电缆） | 130 | 1 |
| 35kV-II | 风A 3-4、风B-3（架空）；光A-2、光B-2、储能-1（电缆） | 140 | 1 |

除 12 回集电线路和 2 回预留外，35kV-I、II 段还分别设置 `T10-1-HV`、`T10-2-HV` 电源变馈线间隔，接至两台31.5MVA、35/10.5kV变压器；每回1.05倍最大持续电流职责为545.596A。

多回路场站尽量拆分到两段，避免单段母线故障切除整个场站。母联只在一台主变或一侧电源已经隔离且故障清除后投入，不允许两台健康主变通过 35kV 母联长期并列。

## 主变与 10kV 电源路径

### 当前推荐

- 主变：2×180MVA、220/35kV 双绕组，`YNd11`，短路电压暂按 14%；220kV星形中性点经中性点CT直接接地，35kV为三角形绕组。
- 10kV 电源：2×31.5MVA、35/10.5kV、`YNd11`、`uk=8%`，分别经 `T10-1-HV`、`T10-2-HV` 间隔接 35kV-I/II 段。
- 动态无功补偿：2×±12Mvar SVG，分别接10kV-I/II段；按目标功率因数0.98的保守计算需21.8875Mvar，选24Mvar后裕度9.65%。
- 0.4kV 所用变：2×200kVA、SCB14干式、10/0.4kV、`Dyn11`、`uk=4%`，分别接 10kV-I/II 段，轮换暗备用；正常仅一台运行并通过闭合的 0.4kV 母联向两段供电。

### 中性点与过电压保护

- 任务书规定220kV为直接接地系统，35kV和10kV为非直接接地系统。
- 35kV-I、II段各设1套ZN接地变+低电阻，课程设备包取2×1000kVA、400A/10s、`R≈50.5Ω`；10kV-I、II段各设1套ZN接地变+低电阻，取2×200kVA、200A/10s、`R≈28.9Ω`。容量按10s短时过载系数10形成课程假设，精确零序阻抗、损耗、温升和厂家成套参数仍待覆盖。
- 正常分列时，每个独立带电母线段各保留1套接地源。35kV或10kV母联事故转供前，必须先退出受电侧或故障侧接地源，只保留健康电源侧1套；联锁禁止“母联合闸且两套接地源同时投入”。母线重新分列后，再恢复每段各1套接地源。
- 220kV线路入口和主变高压端配置MOA；35kV、10kV各段设置PT+MOA柜。7回35kV架空馈线在入口配置MOA，5回35kV电缆馈线配置零序CT；10kV电缆馈线和SVG回路配置零序CT，零序CT职责与三相CT分开管理。
- 220kV线路侧隔离开关配置常开接地开关；35/10kV柜内接地开关与断路器、隔离位置、带电显示和接地源切换设置机械/电气联锁。

### 为什么暂不采用 220/35/10kV 三绕组主变

1. 任务书明确给出 220/35kV 双绕组和 35/10.5kV 变压器阻抗，却未给出本题三绕组容量比与三对短路电压。
2. 已知 10kV 辅助计算负荷仅约 1.757MVA，相对 180MVA 主变很小，低压绕组可能严重闲置。
3. 独立 35/10.5kV 电源变有利于限制 10kV 短路电流，10kV 故障不直接迫使主变退出。
4. 本轮已确认10kV接入2×±12Mvar SVG；独立T10在N-1最严满额吸收时负载率79.17%，无需改为三绕组主变。

## 运行方式

### 正常方式

- L1、L2 和 T1、T2 投入，L3 为远期预留。
- 35kV、10kV 母联断开；0.4kV 母联闭合。
- 35kV和10kV各自分列运行，每个带电母线段投入本段1套接地变+低电阻；两级均为每段1套、全站各2套。
- 两台所用变按运行计划轮换，正常仅一台所用变及其进线断路器投入，另一台所用变和进线断路器处于暗备用；三只主开关设置联锁，禁止两个进线同时闭合并列运行。
- 220kV 分段断路器正常断开；只有调度许可且同期检查通过时才允许条件闭合。

### 一台主变退出

1. 完全隔离故障主变。
2. 退出待转供35kV母线段的接地变+低电阻，确认健康主变侧仅保留1套接地源。
3. 故障清除、接地源联锁许可后合 35kV 母联。
4. 将存活主变通过容量限制在 180MVA 以内。
5. 按当前负荷基线限发约 35.780%，容量缺口约 100.286MVA。
6. 优先保留 10kV、0.4kV 重要负荷。

### 一回 220kV 线路退出

另一回线路若独立承担约280.286MVA，电流约735.559A。按旧版课程参考592A和41℃温度修正系数0.802773，课程保守允许载流量为475.242A，单看线路需限发35.390%。主变N-1本身需限发35.780%，对应线路电流约472.377A，略低于课程保守限值，因此当前总N-1仍由主变容量控制，但导线余量仅约2.864A；现行厂家热额定值到达后必须覆盖复核。

### 35kV 或 10kV 母线段故障

母联不得向故障母线强送。故障段隔离，健康段继续运行。最大短路方式也不能虚构两台健康变压器低压侧长期并列。

### 35kV/10kV母联转供时的接地源切换

1. 先隔离退出的主变、T10或故障母线段，确认故障已清除且受电段允许转供。
2. 母联合闸前断开受电侧/故障侧接地变馈线，只保留健康电源侧1套接地变+低电阻。
3. 联锁同时校验母联位置和两套接地源状态；禁止母联闭合且两套接地源并联，否则目标接地故障电流将失去课程设定边界。
4. 母联断开、两段恢复独立供电后，再分别恢复每段自己的接地源。

### 0.4kV 所用变切换

正常运行所用变退出时，先隔离故障所用变及其进线，再投入备用所用变进线；0.4kV 母联保持闭合。任何切换步骤都不得造成两台所用变经低压侧并列。

## 证据来源

- 本组任务书页 5-7：2×180MVA、220kV 2+1 回、35kV 12+2 回、N-1 可限发、0.4kV 单母线分段、双绕组与 35/10.5kV 阻抗。
- 主接线讲解 PDF 第 2-6 页：单母线、单母线分段、双母线和桥形接线适用范围。
- 课程第四章 PPT 第 33、37、48-49、59、69-71、96-100 页：接线适用条件、旁路需求、桥形扩建和主变绕组选择。
- 学生指导书第 2、3、6、8、9、18 页：35/10kV 分段、桥形、三绕组经济性、N-1、所用电暗备用和设备资料可得性；其中第 9 页明确正常仅一台所用变运行，另一台暗备用。

以上来源均保存在本地私有材料区，公开仓库只保留脱敏后的工程结论。

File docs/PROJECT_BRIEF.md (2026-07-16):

# 项目执行规范

## 重构后的工作提示词

> 以“完成第5组220kV新能源汇集变电所电气一次部分课程设计，并形成可手绘临摹、可复核、可持续维护的完整工程底稿”为总目标。完整使用本地任务书、课程资料和已冻结计算；CAD图作为正式工程底图，用户最终按图手绘临摹。参数采用三级证据优先级：第一，任务书和教师口径；第二，现行国家/行业标准及官方厂家资料；第三，任务书确实缺失时采用偏保守、适合课程设计的工程假设。所有第三类取值必须写明“课程设计假设”、选择理由、适用条件和对结果的影响，但不因缺少非关键现场数据而无限期停留在pending。设计计算、设备职责、主接线、平面图、断面图、说明书和计算书必须使用同一数据源；每个有效批次完成再生成、测试、CAD/PDF目检、日志、提交、推送和GitHub Actions核验。只有会改变根本拓扑、造成明显安全风险或无法合理保守取值的问题才再次向用户提问。

完整、可直接复用的结构化版本见 [课程设计执行提示词](EXECUTION_PROMPT.md)，全部题目给定值、标准采用值和课程设计假设见 [设计依据与假设台账](DESIGN_ASSUMPTIONS_REGISTER.md)。

## 本轮用户授权

- CAD图可以完整绘制并作为手绘临摹依据；最终提交形式仍按课程要求由用户手绘。
- 任务书未给出的海拔、污秽、保护时间、无功容量、系统运行许可等参数，可以通过现行标准、官方资料和课程设计计算自行拟定。
- 拟定值不是现场施工设计参数；若后续获得教师或真实场址数据，必须由统一输入文件触发计算、图纸和文档同步更新。

## 成功标准

项目只有在以下条件同时满足时才算完成：

1. 任务书中的每项内容都有明确产物，并能在需求追踪矩阵中定位。
2. 说明书、计算书、设备表、三张必交图和一张增强详图使用同一组参数，不互相矛盾。
3. 每个适用设备按其职责完成可用输入范围内的额定电压、持续电流、开断、峰值/动稳定、热稳定和绝缘检查，并明确未完成项；35/10kV母线机械、爬距、机械破坏负荷、中性点CT及零序CT等依赖专题的项目保持待定，不套用错误职责。
4. CAD 图纸可编辑、可打印、字体不缺失，并导出兼容版 DWG 与 PDF。
5. 原始资料和公开成果严格分离，Git 历史中不出现隐私或第三方受限文件。
6. 每个有效修改批次完成检查、日志、提交、推送和远端验证。
7. 任务书缺失参数形成独立假设台账，能区分“题目给定”“标准采用”“课程假设”和“最终待教师复核”。
8. 35/10kV母联转供必须先退出受电/故障段接地源，只保留健康侧1套；测试、图纸和报告均不得出现母联闭合且两套低电阻接地源并联的允许状态。

## 工作边界

- 不把参考设计书直接改名为本项目成果。
- 不从旧参考图按比例猜尺寸；缺失尺寸必须来自现行标准、官方厂家外形图或明确标注的课程设计假设。
- 不把课程设计假设伪装成任务书原始条件或现场施工定值。
- 不把 CAD/Office 自动保存文件、提交压缩包或本地环境写入仓库。

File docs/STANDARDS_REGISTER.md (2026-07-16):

# 标准与权威资料台账

## 1. 文档目的

本台账用于管理本项目采用的国家标准、电力行业标准、工程建设标准和设备厂家正式样本，为以下工作提供可追溯依据：

- 220kV 新能源汇集变电站电气主接线方案比选；
- 三相短路电流计算；
- 导体和一次设备选择、动稳定及热稳定校验；
- 220kV 户外配电装置与 35kV、10kV 开关设备布置；
- 接地、过电压保护和绝缘配合；
- 电气主接线简图、配电装置断面图和平面布置图的 CAD 制图；
- 技术设计说明书、计算书、设备表和答辩材料的引用核查。

核验日期：2026-07-15。

本台账中的“现行”“废止”和替代关系，按核验日期从国家标准全文公开系统、全国标准信息公共服务平台、国家数字标准馆等官方来源确认。标准在后续设计阶段仍可能修订，正式交付前应再次核验状态。

## 2. 使用规则

### 2.1 证据优先级

1. 国家标准及工程建设国家标准；
2. 国家能源局发布的电力行业标准；
3. 与上级标准不冲突的其他现行行业标准；
4. 最终选定设备厂家的当前正式样本、外形图和技术协议；
5. 教材、设计手册和既有课程设计仅作解释或复核材料，不作为标准状态和强制数值的最终证据。

当不同文件规定不一致时，不直接自行选择较宽松数值，应核对适用范围、标准层级、实施日期、强制性条文及最新替代关系，并在设计决策记录中说明处理结论。

### 2.2 数值条文和表格复核门槛

> 安全净距、通道宽度、设备安装高度、海拔修正值、短路计算系数、允许温度、动热稳定公式、接触电压、跨步电压、接地导体截面以及其他数值性条文，不得仅依据搜索摘要、网络转载、教材转述或本台账直接采用。必须从合法取得的对应版本标准全文中核对，并记录标准编号、年份、条文号或表号、页码、适用条件和复核日期后，方可进入正式计算、设备表或 CAD 图纸。

受版权限制的标准全文和厂家受限资料应保存在非公开资料区，不得上传到公开 Git 仓库。公开仓库可以保存标准题录、官方链接、核对记录和依法形成的设计结果。

### 2.3 状态标识

- 现行：截至 2026-07-15，官方标准平台显示该版本有效。
- 核心：本项目相应设计环节的直接依据，必须获得原文并逐条核对。
- 配套：用于设备或专项设计的补充依据。
- 条件适用：仅在选定对应方案或设备时使用。
- 废止：不得作为本项目主设计依据，只能用于识别旧资料。

## 3. 主接线、总体布置与设计深度

| 标准 | 状态 | 项目应用 | 官方来源 |
| --- | --- | --- | --- |
| DL/T 5218-2012《220kV～750kV变电站设计技术规程》 | 现行；核心；替代 DL/T 5218-2005 | 220kV 主接线、主变压器配置、站用电、无功补偿及变电站电气总体设计 | [全国标准信息公共服务平台](https://std.samr.gov.cn/hb/search/stdHBDetailed?id=8B1827F23CB5BB19E05397BE0A0AB44A) |
| DL/T 5452-2025《变电工程初步设计内容深度规定》 | 现行；核心；2026-03-28 实施；替代 DL/T 5452-2012 | 约束说明书、计算书、设备表、主接线图、平面图和断面图应达到的初步设计深度 | [全国标准信息公共服务平台](https://std.samr.gov.cn/hb/search/stdHBDetailed?id=424790975E72BCA9E06397BE0A0A3788) |
| DL/T 5056-2024《变电工程总布置设计规程》 | 现行；核心；替代 DL/T 5056-2007 | 站区功能分区、主变及配电装置相对位置、道路、运输和检修通道 | [全国标准信息公共服务平台](https://std.samr.gov.cn/hb/search/stdHBDetailed?id=1B4DE7F0E05DB814E06397BE0A0A5DEE) |
| DL/T 5458-2012《变电工程施工图设计内容深度规定》 | 现行；配套 | 辅助检查 CAD 平面图、断面图和设备标注的信息完整性，不替代课程任务书对初步设计的要求 | [全国标准信息公共服务平台](https://std.samr.gov.cn/hb/search/stdHBDetailed?id=8B1827F23CCEBB19E05397BE0A0AB44A) |

适用边界：本项目最高电压等级为 220kV。GB 50059-2011《35kV～110kV变电站设计规范》不能替代 DL/T 5218-2012 作为全站总体设计依据。

## 4. 短路电流、导体与电器选择

| 标准 | 状态 | 项目应用 | 官方来源 |
| --- | --- | --- | --- |
| GB/T 15544.1-2023《三相交流系统短路电流计算 第1部分：电流计算》 | 现行；核心；替代 GB/T 15544.1-2013 | 最大和最小短路电流、初始对称短路电流、峰值电流及开断相关电流计算 | [国家标准全文公开系统](https://openstd.samr.gov.cn/bzgk/gb/newGbInfo?hcno=D86399BB0989F89A79B6CACBB666DA09) |
| GB/T 15544.2-2017《三相交流系统短路电流计算 第2部分：短路电流计算应用的系数》 | 现行；配套 | 核对短路计算所用系数及适用条件 | [国家标准全文公开系统](https://openstd.samr.gov.cn/bzgk/gb/newGbInfo?hcno=5D0E7DDDB4F76AB1891D0B35977E958D) |
| GB/T 15544.3-2017《三相交流系统短路电流计算 第3部分：电气设备数据》 | 现行；配套 | 规范系统、线路、变压器等元件数据的选取 | [国家标准全文公开系统](https://openstd.samr.gov.cn/bzgk/gb/newGbInfo?hcno=691C753840801F6FD5E17A86BBA9E50D) |
| GB/T 15544.5-2017《三相交流系统短路电流计算 第5部分：算例》 | 现行；配套 | 用标准算例复核短路计算程序和手算链路 | [国家标准全文公开系统](https://openstd.samr.gov.cn/bzgk/gb/newGbInfo?hcno=B46A703A3A607C50E04F95E5C7831596) |
| DL/T 5222-2021《导体和电器选择设计规程》 | 现行；核心；替代 DL/T 5222-2005 | 3kV～1000kV 导体和电器的额定电压、持续电流、开断、动稳定、热稳定和环境修正 | [全国标准信息公共服务平台](https://std.samr.gov.cn/hb/search/stdHBDetailed?id=D961281962894C9BE05397BE0A0A7A39) |
| GB/T 1179-2017《圆线同心绞架空导线》 | 现行；配套 | 核查任务书给定 LGJ-400/50 出线导线的产品参数和材料要求 | [国家标准全文公开系统](https://openstd.samr.gov.cn/bzgk/gb/newGbInfo?hcno=F936B58052E9B750D1FEF196B660A084) |
| GB/T 5585.1-2018《电工用铜、铝及其合金母线 第1部分：铜和铜合金母线》 | 现行；条件适用 | 采用铜母线时核对材料和截面产品要求 | [国家标准全文公开系统](https://openstd.samr.gov.cn/bzgk/gb/newGbInfo?hcno=942B6BCC24D80C0796F31F217A4A4370) |
| GB/T 5585.2-2018《电工用铜、铝及其合金母线 第2部分：铝和铝合金母线》 | 现行；条件适用 | 采用铝或铝合金硬母线时核对材料和截面产品要求 | [国家标准全文公开系统](https://openstd.samr.gov.cn/bzgk/gb/newGbInfo?hcno=D70AA7B5DFC0D0845CD88820A94B5D24) |

LGJ-400/50当前592A基准来自标注GB1179-83的旧版二手课程参数表，仅用于41℃保守课程校核；GB/T 1179-2017是产品结构标准，不能替代在明确风速、日照、环境温度和最高导体温度下的现行厂家热额定值。

短路计算原文复核重点包括：电压系数、变压器修正系数、峰值系数、最大和最小运行方式、故障前条件、开断时刻、短路持续时间，以及风电、光伏和储能变流器短路贡献的建模边界。

## 5. 配电装置、开关设备与一次设备

### 5.1 户外配电装置和绝缘配合

| 标准 | 状态 | 项目应用 | 官方来源 |
| --- | --- | --- | --- |
| DL/T 5352-2018《高压配电装置设计规范》 | 现行；核心；替代 DL/T 5352-2006 | 220kV 户外 AIS 型式、带电体安全净距、构架、母线、围栏、道路及检修空间 | [全国标准信息公共服务平台](https://std.samr.gov.cn/hb/search/stdHBDetailed?id=8B1827F25307BB19E05397BE0A0AB44A) |
| GB 50060-2008《3～110kV高压配电装置设计规范》 | 现行；核心；适用 35kV 和 10kV，不适用 220kV 净距 | 35kV、10kV 配电装置及开关柜室的安全和布置要求 | [国家数字标准馆](https://www.ndls.org.cn/standard/detail/089c7f70db68305bddb5572bcfe46f3c) |
| GB/T 50064-2014《交流电气装置的过电压保护和绝缘配合设计规范》 | 现行；核心 | 避雷器配置、雷电和操作过电压保护、设备绝缘水平配合 | [国家数字标准馆](https://www.ndls.org.cn/standard/detail/bb1e1526e905c478b1e95bac24d96379) |
| GB/T 311.1-2012《绝缘配合 第1部分：定义、原则和规则》 | 现行；配套 | 设备耐受电压、绝缘水平和绝缘配合的基础规则 | [国家标准全文公开系统](https://openstd.samr.gov.cn/bzgk/gb/newGbInfo?hcno=B101E5946B69F7ADA8ADA3D09622A37D) |
| GB/T 11032-2020《交流无间隙金属氧化物避雷器》 | 现行；核心 | 220kV、35kV和10kV无间隙金属氧化物避雷器的额定值、试验和保护性能 | [国家标准全文公开系统](https://openstd.samr.gov.cn/bzgk/std/newGbInfo?hcno=861E4F271389864CF8B0FFA403A87E00) |
| Q/GDW 13039.2-2018《220kV交流无间隙金属氧化物避雷器采购标准 第2部分：Y(H)10W-204/532专用技术规范》 | 国家电网企业标准；设备参数核验依据 | 核对220kV MOA 的204kV额定电压、159kV持续运行电压、10kA标称放电电流和不大于532kV雷电残压 | 国家电网有限公司正式PDF；核验副本仅保留本地私有材料区 |

DL/T 5352-2018 中的安全净距类别、相间和相地距离、带电体对围栏及道路距离、设备和母线安装高度、跨越高度以及海拔修正值，必须依据标准全文逐条核对后才能冻结断面图和平面图。

### 5.2 35kV、10kV 开关设备

| 标准 | 状态 | 项目应用 | 官方来源 |
| --- | --- | --- | --- |
| GB/T 3906-2020《3.6kV～40.5kV交流金属封闭开关设备和控制设备》 | 现行；核心 | 10kV、35kV 开关柜分类、隔室、联锁、内部电弧及型式试验要求 | [国家标准全文公开系统](https://openstd.samr.gov.cn/bzgk/gb/newGbInfo?hcno=074ACACFFF9618BF5F3E922120A87E5B) |
| DL/T 404-2018《3.6kV～40.5kV交流金属封闭开关设备和控制设备》 | 现行；配套；替代 DL/T 404-2007 | 补充电力行业对 35kV、10kV 开关设备的技术要求 | [全国标准信息公共服务平台](https://std.samr.gov.cn/hb/search/stdHBDetailed?id=8B1827F15147BB19E05397BE0A0AB44A) |
| GB/T 11022-2020《高压交流开关设备和控制设备标准的共用技术要求》 | 现行；核心 | 高压开关设备的环境、额定值、试验和通用技术条件 | [国家标准全文公开系统](https://openstd.samr.gov.cn/bzgk/gb/newGbInfo?hcno=196F732DBD167D2F302AF52BA6FAFAA1) |
| DL/T 593-2016《高压开关设备和控制设备标准的共用技术要求》 | 现行；配套；替代 DL/T 593-2006 | 补充电力行业通用技术要求 | [全国标准信息公共服务平台](https://std.samr.gov.cn/hb/search/stdHBDetailed?id=8B1827F2299ABB19E05397BE0A0AB44A) |
| GB/T 1984-2024《高压交流断路器》 | 现行；核心；替代 GB/T 1984-2014 | 断路器开断、关合、操作顺序、耐受和机械性能校验 | [国家标准全文公开系统](https://openstd.samr.gov.cn/bzgk/gb/newGbInfo?hcno=05878AD1D8427B64705075DB83FD468C) |
| GB/T 1985-2023《高压交流隔离开关和接地开关》 | 现行；核心；替代 GB/T 1985-2014 | 隔离开关和接地开关额定值、耐受及关合能力 | [国家标准全文公开系统](https://openstd.samr.gov.cn/bzgk/gb/newGbInfo?hcno=66EC8A1CCDF11D2CA3826648ECF3BB4F) |
| GB/T 7674-2020《额定电压72.5kV及以上气体绝缘金属封闭开关设备》 | 现行；条件适用 | 仅在 220kV GIS 方案进入正式比选或被选用时采用 | [国家标准全文公开系统](https://openstd.samr.gov.cn/bzgk/gb/newGbInfo?hcno=614C6271842A7CE4B08512846AF2BD9D) |

GB/T 3906 和 DL/T 404 不提供可直接用于本项目 CAD 的统一柜体外形尺寸。柜宽、柜深、柜高、泄压通道、后维护空间和电缆弯曲空间必须取自最终型号的当前厂家正式样本和外形图。

### 5.3 互感器和变压器

| 标准 | 状态 | 项目应用 | 官方来源 |
| --- | --- | --- | --- |
| GB/T 20840.1-2010《互感器 第1部分：通用技术要求》 | 现行；核心 | CT、VT 和 CVT 的通用环境、额定值和试验要求 | [国家标准全文公开系统](https://openstd.samr.gov.cn/bzgk/gb/newGbInfo?hcno=A40AEB77EBAB85616E49BD48E25C0C44) |
| GB/T 20840.2-2014《互感器 第2部分：电流互感器的补充技术要求》 | 现行；核心 | CT 变比、准确级、热稳定和动稳定等选型依据 | [国家标准全文公开系统](https://openstd.samr.gov.cn/bzgk/gb/newGbInfo?hcno=9D2A5ECCC914E53080EBF5E3DFC7233E) |
| GB/T 20840.3-2013《互感器 第3部分：电磁式电压互感器的补充技术要求》 | 现行；核心 | 电磁式 VT 的额定参数和准确级 | [国家标准全文公开系统](https://openstd.samr.gov.cn/bzgk/gb/newGbInfo?hcno=0C1DC45D6A311BCF9BD3C9E8AA9B0F16) |
| GB/T 20840.5-2013《互感器 第5部分：电容式电压互感器的补充技术要求》 | 现行；条件适用 | 220kV 侧采用 CVT 时的选型依据 | [国家标准全文公开系统](https://openstd.samr.gov.cn/bzgk/gb/newGbInfo?hcno=1B0D4AF1336CA344200B2CD79B631848) |
| GB/T 1094.1-2013《电力变压器 第1部分：总则》 | 现行；核心 | 主变压器及辅助变压器的通用技术条件 | [国家标准全文公开系统](https://openstd.samr.gov.cn/bzgk/gb/newGbInfo?hcno=C3539A02733314553221D30BB7A2A0DF) |
| GB/T 6451-2023《油浸式电力变压器技术参数和要求》 | 现行；核心；替代 GB/T 6451-2015 | 两台 180MVA 户外油浸式主变的参数和产品要求 | [国家标准全文公开系统](https://openstd.samr.gov.cn/bzgk/gb/newGbInfo?hcno=A75E4FE74ED07563EAD11D6379E0E3A5) |

### 5.4 无功补偿、运行与保护假设

| 标准 | 状态 | 项目应用 | 官方来源 |
| --- | --- | --- | --- |
| GB/T 29321-2012《光伏发电站无功补偿技术规范》 | 现行；配套 | 支撑集中无功补偿可设置在升压变低压侧、容量需结合接入条件确定的原则；不把0.98或24Mvar写成强制值 | [国家标准全文公开系统](https://openstd.samr.gov.cn/bzgk/std/newGbInfo?hcno=E6451F89B113960B614337BEDD30194A) |
| GB/T 19963.1-2021《风电场接入电力系统技术规定 第1部分：陆上风电》 | 现行；配套 | 风电场无功、电压与并网运行能力复核 | [国家标准全文公开系统](https://openstd.samr.gov.cn/bzgk/std/newGbInfo?hcno=F0127C2B431AC283CD6ED17CE67F8E46) |
| GB/T 19964-2024《光伏发电站接入电力系统技术规定》 | 现行；配套 | 光伏场站无功、电压与并网运行能力复核 | [国家标准全文公开系统](https://openstd.samr.gov.cn/bzgk/std/newGbInfo?hcno=40D8691DFD7EC3CBA423CCBA65D262F3) |
| GB/T 14285-2023《继电保护和安全自动装置技术规程》 | 现行；核心；替代2006版 | 保护配置与配合原则；本项目0.05s/1.00s仍是显式课程假设，不冒充标准固定整定值 | [国家标准全文公开系统](https://openstd.samr.gov.cn/bzgk/gb/newGbInfo?hcno=0F1C15A59731267D3A756D6AFBB32841) |
| GB/T 31464-2022《电网运行准则》 | 现行；配套；替代2015版 | 系统并列、调度许可和运行边界的原则性依据 | [国家标准全文公开系统](https://openstd.samr.gov.cn/bzgk/gb/newGbInfo?hcno=2E138E6A6D540124290DBBA47FFA1E14) |
| GB/T 26218.1-2010、GB/T 26218.2-2010 | 现行；配套 | d级污秽课程假设下的外绝缘选择与最终爬电距离复核 | [第1部分](https://openstd.samr.gov.cn/bzgk/gb/newGbInfo?hcno=5BC1117698E6281FAABB3CECFD85AF0C)；[第2部分](https://openstd.samr.gov.cn/bzgk/gb/newGbInfo?hcno=84465B7D3FDCD8B1F9498C236C5D550B) |

## 6. 接地

| 标准 | 状态 | 项目应用 | 官方来源 |
| --- | --- | --- | --- |
| GB/T 50065-2011《交流电气装置的接地设计规范》 | 现行；核心 | 接地网设计、接触电压、跨步电压、接地导体热稳定及故障电流分流 | [国家数字标准馆](https://www.ndls.org.cn/standard/detail/4a5f1191d275a706ce9a4e274db80130) |
| GB 50169-2016《电气装置安装工程 接地装置施工及验收规范》 | 现行；配套；替代 GB 50169-2006 | 接地装置焊接、连接、施工和验收；不替代接地设计计算 | [国家数字标准馆](https://www.ndls.org.cn/standard/detail/503cb582b61febf4ef65e73de7ff64e5) |

接地计算原文复核重点包括：故障持续时间、故障电流分流系数、地表层修正、接触和跨步电压限值、接地导体最小截面及腐蚀裕量。

## 7. 电气与 CAD 制图

| 标准 | 状态 | 项目应用 | 官方来源 |
| --- | --- | --- | --- |
| DL/T 5028.1-2015《电力工程制图标准 第1部分：一般规则》 | 现行；核心 | 图幅、比例、线型、线宽、文字、标注和图签 | [全国标准信息公共服务平台](https://std.samr.gov.cn/hb/search/stdHBDetailed?id=8B1827F20FAABB19E05397BE0A0AB44A) |
| DL/T 5028.3-2015《电力工程制图标准 第3部分：电气、仪表与控制部分》 | 现行；核心 | 主接线、电气设备编号以及电气平面和断面的表达 | [全国标准信息公共服务平台](https://std.samr.gov.cn/hb/search/stdHBDetailed?id=8B1827F20CF0BB19E05397BE0A0AB44A) |
| GB/T 4728.1-2018《电气简图用图形符号 第1部分：一般要求》 | 现行；核心 | 电气图形符号的一般规则 | [国家标准全文公开系统](https://openstd.samr.gov.cn/bzgk/gb/newGbInfo?hcno=AFB34DDA789F637546166983140B34C5) |
| GB/T 4728.2-2018《电气简图用图形符号 第2部分：符号要素、限定符号和其他常用符号》 | 现行；配套 | 组合符号、限定符号和常用符号 | [国家标准全文公开系统](https://openstd.samr.gov.cn/bzgk/gb/newGbInfo?hcno=30174DF769B49D331AB0682057955D9C) |
| GB/T 4728.3-2018《电气简图用图形符号 第3部分：导体和连接件》 | 现行；核心 | 母线、导体、连接点和端子表达 | [国家标准全文公开系统](https://openstd.samr.gov.cn/bzgk/gb/newGbInfo?hcno=6F06A509CE0C66B30F0A21D1B6CEE3E0) |
| GB/T 4728.6-2022《电气简图用图形符号 第6部分：电能的发生与转换》 | 现行；核心 | 发电、变压器及电能转换设备符号 | [国家标准全文公开系统](https://openstd.samr.gov.cn/bzgk/gb/newGbInfo?hcno=01195C7C62A31C6D9F84B2A6B106EA71) |
| GB/T 4728.7-2022《电气简图用图形符号 第7部分：开关、控制和保护器件》 | 现行；核心 | 断路器、隔离开关、接地开关和保护器件符号 | [国家标准全文公开系统](https://openstd.samr.gov.cn/bzgk/gb/newGbInfo?hcno=D0D8E532BD220616FADD0B9D3A4E1346) |
| GB/T 4728.11-2022《电气简图用图形符号 第11部分：建筑安装平面布置图》 | 现行；配套 | 平面布置图中的安装和设备符号 | [国家标准全文公开系统](https://openstd.samr.gov.cn/bzgk/gb/newGbInfo?hcno=CF672DA6DE990B8A0808524E9B9A4C24) |
| GB/T 6988.1-2024《电气技术用文件的编制 第1部分：规则》 | 现行；核心；替代 GB/T 6988.1-2008 | 电气技术文件的结构、简图编制和引用规则 | [国家标准全文公开系统](https://openstd.samr.gov.cn/bzgk/gb/newGbInfo?hcno=3FE198A10F973D18CF8CA9893E1E7C9E) |
| GB/T 14689-2008《技术制图 图纸幅面和格式》 | 现行；配套 | 通用图幅和格式 | [国家标准全文公开系统](https://openstd.samr.gov.cn/bzgk/gb/newGbInfo?hcno=6C3BD0FCD8FFFE7CEC6404FB0180EA96) |
| GB/T 14690-1993《技术制图 比例》 | 现行；配套 | 图纸比例 | [国家标准全文公开系统](https://openstd.samr.gov.cn/bzgk/gb/newGbInfo?hcno=C111329A862219BCCCAAF32E14FF4CD0) |
| GB/T 14691-1993《技术制图 字体》 | 现行；配套 | 制图字体 | [国家标准全文公开系统](https://openstd.samr.gov.cn/bzgk/gb/newGbInfo?hcno=44F8A8E5B9D37004AB8445B42992B1BC) |
| GB/T 17450-1998《技术制图 图线》 | 现行；配套 | 图线类型和表达 | [国家标准全文公开系统](https://openstd.samr.gov.cn/bzgk/gb/newGbInfo?hcno=ED5D794A6EFCD039618233C957C058DB) |

## 8. 厂家正式样本

设备标准规定额定值、结构和试验要求，但通常不提供可直接用于 CAD 的项目外形尺寸。最终图纸必须采用所选厂家的当前正式样本、外形图和安装资料。

已核验可公开访问的厂家样本示例：

- ABB《UniGear Product Guide》（Rev. 4；非本项目选型依据，仅作厂家资料格式示例）：[ABB Library PDF](https://library.e.abb.com/public/40813c97d07812bdc1257b13005735d2/Guide_UNIGEAR(en)_1VLM000005%20Rev4.pdf)。
- CHINT《KYN61-40.5(Z) MV Air Insulated Switchgear Catalog》：[官方目录](https://www.chintglobal.com/content/dam/chint/global/product-center/power-transmission-and-distribution/distribution/mv-switchgear/mv-air-insulated-switchgear/kyn61-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)。
- Siemens NXAirS 40.5kV开关柜：[官方产品页](https://www.siemens.com/zh-cn/products/energy-systems/nxairs/)。
- CHINT LW43-252户外SF6断路器：[官方产品页](https://www.chintglobal.com/global/en/products/power-transmission-and-distribution/transmission/lw43-252.html)。

上述资料仅说明厂家家族可得性和正式样本的资料形式，不代表本项目已经选定对应厂家。CHINT KYN61当前网页声称电流范围可到3150A，但链接目录第22页列出的母线/断路器电流最高为2500A，两者存在版本或配置差异；3150A配置必须取得更新样本或型式试验证明后再采用。设备定型时至少应记录厂家、产品系列、额定电压、额定电流、短路等级、柜型或设备型号、样本版本、发布日期、下载链接及外形图页码。

本轮另核对 Siemens 官方《NXAirS 40.5 kV Air-Insulated Medium-Voltage Switchgear》样本，其40.5kV主母线额定电流上限为3150A。因此当前35kV 3150A方案不能简单上调到4000A；课程设计通过把开关柜室控制在不高于40℃满足常规使用条件形成紧裕度方案，最终仍须取得明确支持3150A、项目环境和温升条件的厂家配置及型式试验资料。

## 9. 重点废止或被替代版本（非完整清单）

| 旧标准 | 官方状态或替代关系 | 本项目处理 | 官方来源 |
| --- | --- | --- | --- |
| DL/T 5218-2005 | 被 DL/T 5218-2012 替代 | 全站总体设计采用 2012 版 | [现行版本元数据](https://std.samr.gov.cn/hb/search/stdHBDetailed?id=8B1827F23CB5BB19E05397BE0A0AB44A) |
| DL/T 5452-2012 | 废止，被 DL/T 5452-2025 替代 | 不再作为初步设计内容深度依据 | [旧版元数据](https://std.samr.gov.cn/hb/search/stdHBDetailed?id=8B1827F23D0ABB19E05397BE0A0AB44A) |
| DL/T 5056-2007 | 被 DL/T 5056-2024 替代 | 总布置采用 2024 版 | [现行版本元数据](https://std.samr.gov.cn/hb/search/stdHBDetailed?id=1B4DE7F0E05DB814E06397BE0A0A5DEE) |
| GB/T 15544.1-2013 | 废止，被 GB/T 15544.1-2023 替代 | 不再用于短路计算 | [旧版官方页面](https://openstd.samr.gov.cn/bzgk/gb/newGbInfo?hcno=2EF5BD24DFB40A481218BEFE9FD94ABD) |
| DL/T 5222-2005 | 被 DL/T 5222-2021 替代 | 导体和电器选择采用 2021 版 | [现行版本元数据](https://std.samr.gov.cn/hb/search/stdHBDetailed?id=D961281962894C9BE05397BE0A0A7A39) |
| DL/T 5352-2006 | 被 DL/T 5352-2018 替代 | 220kV 户外配电装置采用 2018 版 | [现行版本元数据](https://std.samr.gov.cn/hb/search/stdHBDetailed?id=8B1827F25307BB19E05397BE0A0AB44A) |
| DL/T 404-2007 | 被 DL/T 404-2018 替代 | 35kV、10kV 开关设备采用 2018 版 | [现行版本元数据](https://std.samr.gov.cn/hb/search/stdHBDetailed?id=8B1827F15147BB19E05397BE0A0AB44A) |
| DL/T 593-2006 | 被 DL/T 593-2016 替代 | 开关设备行业共用要求采用 2016 版 | [现行版本元数据](https://std.samr.gov.cn/hb/search/stdHBDetailed?id=8B1827F2299ABB19E05397BE0A0AB44A) |
| GB/T 1984-2014 | 废止，被 GB/T 1984-2024 替代 | 旧断路器选型表必须按新版本复核 | [旧版官方页面](https://openstd.samr.gov.cn/bzgk/gb/newGbInfo?hcno=B4E75F2578A2D58E1D96B14F0FE015CA) |
| GB/T 1985-2014 | 废止，被 GB/T 1985-2023 替代 | 旧隔离开关、接地开关选型表必须按新版本复核 | [旧版官方页面](https://openstd.samr.gov.cn/bzgk/gb/newGbInfo?hcno=036A5E8A55CF987FBE2950AFDB50071D) |
| GB/T 6451-2015 | 废止，被 GB/T 6451-2023 替代 | 主变产品参数采用 2023 版 | [旧版官方页面](https://openstd.samr.gov.cn/bzgk/gb/newGbInfo?hcno=2A7013702A4DE775A78EC1944199FBD4) |
| GB 50169-2006 | 被 GB 50169-2016 替代 | 接地施工与验收采用 2016 版 | [现行版本元数据](https://www.ndls.org.cn/standard/detail/503cb582b61febf4ef65e73de7ff64e5) |
| GB/T 6988.1-2008 | 废止，被 GB/T 6988.1-2024 替代 | CAD 和技术文件编制采用 2024 版 | [旧版官方页面](https://openstd.samr.gov.cn/bzgk/gb/newGbInfo?hcno=40EDE34EABD26A911B9D993DCDD28873) |
| DL/T 621-1997《交流电气装置的接地》 | 废止 | 接地设计以 GB/T 50065-2011 为主，不引用该旧版作为现行依据 | [旧版元数据](https://std.samr.gov.cn/hb/search/stdHBDetailed?id=8B1827F18828BB19E05397BE0A0AB44A) |

旧教材、既有课程设计或设备资料如引用上述版本，必须标记为“历史资料”，不得把其中数值直接带入当前计算和图纸。

## 10. 本项目待确认条件

以下条件会直接影响标准条文选择或数值结果，未确认前不得冻结相应设备参数和 CAD 尺寸：

| 条件 | 影响 |
| --- | --- |
| 海拔 | 绝缘水平、外绝缘和安全净距修正 |
| 污秽等级 | 爬电距离、绝缘子和设备外绝缘选型 |
| 220kV 配电装置最终采用 AIS 或 GIS | 适用设备标准、站区占地和平断面结构 |
| 主变采用三绕组方案或 220/35kV 双绕组加 35/10.5kV 辅助变方案 | 主接线、短路网络、设备数量和布置 |
| 35kV、10kV 开关柜最终厂家和型号 | 柜体尺寸、维护通道、泄压方式和电缆空间 |
| 新能源短路电流贡献模型 | 最大短路电流、开断能力和设备裕度 |
| 任务书对 CAD 直接提交或作为手绘底稿的最终口径 | 图幅、出图比例和交付格式 |

## 11. 标准采用记录要求

每次从标准中采用数值、公式或强制性要求时，应在计算书、设计说明或独立核对记录中留下以下信息：

1. 标准编号、名称和年份；
2. 标准状态核验日期；
3. 条文号、表号、图号或附录号；
4. 原文页码和适用条件；
5. 本项目采用值及必要的修正过程；
6. 核对人和复核日期；
7. 若使用厂家数据，补充厂家、型号、样本版本和外形图页码。

标准状态或厂家样本发生变化时，应先更新本台账，再修改计算、设备表和图纸，避免说明书、计算书和 CAD 使用不同版本的依据。

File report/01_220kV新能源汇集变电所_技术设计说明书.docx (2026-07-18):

《发电厂电气部分》课程设计

220kV新能源汇集变电所电气一次部分初步设计

技术设计说明书

学 院 | 电气与信息工程学院
专 业 | 电气工程及其自动化
班 级 | ____________________________
姓 名 | ____________________________
学 号 | ____________________________
同组设计者 | ____________________________
指导教师 | ____________________________
任务起止日期 | 2026年7月6日—2026年7月17日

公开版：姓名、学号、班级及签字字段留空，提交时由学生手工填写。

课程设计底稿，非施工图；工程实施前须按现行标准及厂家资料复核。

# 摘 要

本课程设计面向一座220kV新能源汇集变电所，完成220/35/10/0.4kV电气一次部分初步设计。在任务书给定的系统容量、线路、负荷和自然条件基础上，采用单母线分段的220kV主接线，35kV和10kV均采用单母线两分段，0.4kV采用单母线分段暗备用。配置2×180MVA、220/35kV、YNd11、uk=14%的主变，2×31.5MVA、35/10.5kV、YNd11、uk=8%的T10，2×±12Mvar SVG，以及2×200kVA、SCB14、Dyn11、uk=4%的所用变。计算得到35kV汇集计算容量280.286MVA，主变正常负载率77.857%；主变N-1时需限发35.780%。课程短路模型下10kV条件性最大综合短路电流为15.638kA，禁止并列敏感性为28.472kA。设备按额定电压、持续电流、开断、峰值和1.10s热稳定进行等级预筛，并补齐CT/PT、零序CT、母线、绝缘子/套管、MOA、接地变+低电阻和接地开关的课程配置。35/10kV母联转供时仅保留健康侧1套接地源。CAD按三张必交图加一张L1线路间隔增强详图组织。

关键词：新能源汇集变电所；电气主接线；主变压器；短路电流；设备选择；配电装置

目 录

# 第一章 电气主接线设计

## 1.1 原始资料与设计范围

设计对象为第5组220kV新能源汇集变电所。本站通过12回35kV集电线路汇集风电、光伏和储能电能，经两台220/35kV主变升压后由两回220kV线路送出，并预留第三回线路。10kV系统承担站用备用电源、无功补偿、冷却和集控通信等辅助负荷，0.4kV系统向站内低压负荷供电。

本设计的工作链条由原始资料整理、运行方式冻结、负荷与容量计算、短路等值、设备职责确定、配电装置布置和图纸校核组成。说明书重点回答“为什么采用该方案、方案在什么条件下成立”，计算书则给出公式、代入和数值校验；两者均读取同一组YAML参数及计算结果，避免表格、图纸与正文各自取值。

参数采用分级证据管理：任务书和教师口径优先；现行标准及正式厂家资料用于补充；仍缺少唯一值时，采用偏保守的课程设计假设并在边界章节中单列。海拔不超过1000m、污秽d级、保护及开断时间、SVG容量和接地设备参数均属于可被后续真实资料覆盖的课程冻结值。

表1-1 主要原始资料

项目 | 任务书或冻结值 | 设计处理
电压等级 | 220/35/10/0.4kV | 覆盖一次主接线、辅助系统和所用电
主变压器 | 2×180MVA、YNd11、uk=14% | 220/35kV双绕组、油浸、户外、有载调压
220kV线路 | 2回在运、1回预留；LGJ-400/50 | 向西北出线；N-1校核温度修正载流量
35kV集电线路 | 12回在运、2回预留 | WA/WB共7回架空并设入口MOA；PVA/PVB/ES共5回电缆并设ZCT
10kV电源变 | 2×31.5MVA、YNd11、uk=8% | 35/10.5kV，分别供10kV-I/II段
所用变 | 2×200kVA、SCB14、Dyn11、uk=4% | 10/0.4kV，轮换暗备用
系统等值 | S1=2400MVA，xc1=0.40；S2=2000MVA，xc2=0.45 | 换算至100MVA基准
220kV线路长度 | L1=70km，L2=85km，L3=60km | L3不参加本期基准计算
自然条件 | 最高41℃，最低-12℃，平均15℃ | 设备和导体环境校核
场址补充假设 | 海拔≤1000m，污秽d级 | 课程假设；真实工程须替换

结果分析：原始资料决定了本站属于“多回35kV电源汇集、少回220kV集中送出”的典型结构。主变容量、220kV线路N-1载流量和35/10kV母联事故转供能力因此成为全设计的三条控制主线；第三回220kV线路仅作远期预留，不参加本期负荷和短路基准计算。

设计边界：计算、设备等级和CAD几何用于课程设计闭环。精确设备型号、厂家41℃服务条件、完整标准短路模型、CT/PT/ZCT完整负荷与暂态参数、35/10kV母线机械、MOA能量/TOV、接地源厂家联锁、避雷针保护范围和接地网接触/跨步电压不在本次课程底稿中冒充已完成。

## 1.2 主接线设计原则

主接线应满足安全可靠、运行灵活、检修方便、经济合理和便于扩建等要求。本站以新能源集中送出为主，正常运行时尽量保持各电源分列，事故转供前先隔离故障源，避免通过母联形成未经许可的系统并列。

可靠性评价不只看断路器数量，还要检查任一线路、主变或母线段退出后的停电范围和恢复路径。本期方案允许通过母联进行事故转供，但转供能力受存活主变或T10额定容量、线路载流量、短路水平及接地源联锁共同约束，不能把“母联可以闭合”等同于“所有负荷均可无条件恢复”。

经济性评价以满足本期回路规模和远期扩建为前提，避免为有限回路数配置过多母线、隔离开关和占地。运行灵活性则通过分段、预留间隔、明确的正常断开点和可执行的事故操作顺序实现，而不是依赖长期并列运行。

- 220kV侧应适应两回本期线路、两台主变和一回远期预留线路。
- 35kV侧应把同一场站回路分散到两段母线，并为两台T10和预留回路留出间隔。
- 10kV侧应保证两套SVG和重要辅助负荷分段供电，禁止两台健康T10长期并列。
- 0.4kV所用电采用两台所用变暗备用，任一台应能承担全部经常负荷。

## 1.3 220kV主接线方案比较

220kV侧本期包括两回线路、两台主变和一回远期预留线路。候选接线必须同时适应线路与主变成组运行、母线分区故障、设备检修以及第三回线路扩建。比较时不单纯追求断路器最少，而是综合回路规模、故障影响、倒闸复杂度、占地投资和课程图纸可表达性。

表1-2 220kV候选方案技术比较

方案 | 主要优点 | 主要不足 | 结论
内桥接线 | 断路器数量少，初投资低 | 远期第三回线路扩建困难；运行灵活性较差 | 仅作比较
单母线分段 | 接线清晰、经济；母线故障限制在一段；预留扩建方便 | 一段检修时该段线路和主变退出 | 采用
双母线不带旁路 | 检修灵活、供电可靠、扩建方便 | 隔离开关多、占地及投资高、倒闸复杂 | 可靠性要求提高时升级

综合本期回路数、课程图纸表达和经济性，220kV采用单母线分段。L1、T1接I段，L2、T2接II段，L3按远期预留间隔设置。分段断路器正常断开；只有调度许可且同期检查通过后才允许条件闭合。

内桥接线虽然断路器数量少、初投资较低，但新增第三回线路时桥臂和运行方式均需较大调整，且线路、主变之间的操作关联较强。双母线方案检修灵活，却会显著增加隔离开关、母线构架、倒闸步骤和占地，与本期有限回路数不匹配。单母线分段使每段形成“1回线路+1台主变”的清晰单元，母线故障影响限制在一段，同时为L3保留独立间隔，是本期可靠性与经济性的折中方案。

结果分析：正常分段运行时系统1和系统2不经本站并列；分段断路器闭合只作为调度许可下的条件方式。因此设备短路预筛既保留分列运行职责，也对分段闭合场景进行条件性校核，但不把该场景写成默认运行方式。

## 1.4 35kV、10kV与0.4kV接线

35kV侧回路数量最多，是本站一次接线组织的重点。两台主变分别接入I、II段母线，12回本期集电线路按6+6分配，同一风电或光伏场站的多回线路尽量跨段布置，以降低单段母线故障导致整个场站同时退出的概率。每段另设一回T10高压侧馈线和一回远期预留间隔，母联正常断开。

10kV系统由两台35/10.5kV T10分别供电，每段配置一套SVG及相应辅助馈线。采用独立T10而不从主变第三绕组直接取电，可使10kV无功补偿和辅助系统与主变220/35kV主送出功能分开组织，并便于分段检修；代价是增加两台电源变及相应间隔。0.4kV系统采用两台所用变轮换暗备用，正常一台运行、母联闭合、另一台进线断开。

表1-3 各电压等级接线与正常状态

电压等级 | 接线方式 | 正常分段/母联状态 | 运行要点
220kV | 单母线分段 | 断开 | 系统1、系统2分列；条件闭合须调度许可和同期
35kV | 单母线两分段 | 断开 | 两台主变各带一段；事故转供前隔离故障主变
10kV | 单母线两分段 | 断开 | 两台T10各带一段；健康T10禁止并列
0.4kV | 单母线分段 | 闭合 | 正常仅一台所用变运行，另一台暗备用

表1-4 35kV馈线分配

母线段 | 本期馈线 | 有功容量/MW | 附加间隔
35kV-I | WA-1、WA-2、WB-1、WB-2（架空）；PVA-1、PVB-1（电缆） | 130 | T10-1-HV；预留1回
35kV-II | WA-3、WA-4、WB-3（架空）；PVA-2、PVB-2、ES-1（电缆） | 140 | T10-2-HV；预留1回

35kV-I段接入130MW，II段接入140MW，两段本期馈线数量相同但负荷构成不同。按基础单回电流累加，I、II段分别为2230.732A和2404.371A；主变进线及母联设备仍按单台180MVA主变额定电流的1.05倍，即3117.691A确定持续职责，从而覆盖事故转供而不是只覆盖正常分段负荷。

结果分析：分段接线的价值在于把故障影响和检修范围局部化。其成立条件是母联不用于两台健康电源长期并列，并且事故转供前完成故障隔离、容量核对和接地源切换。主接线图中的常开点、预留间隔和接地设备因此都属于运行逻辑的一部分。

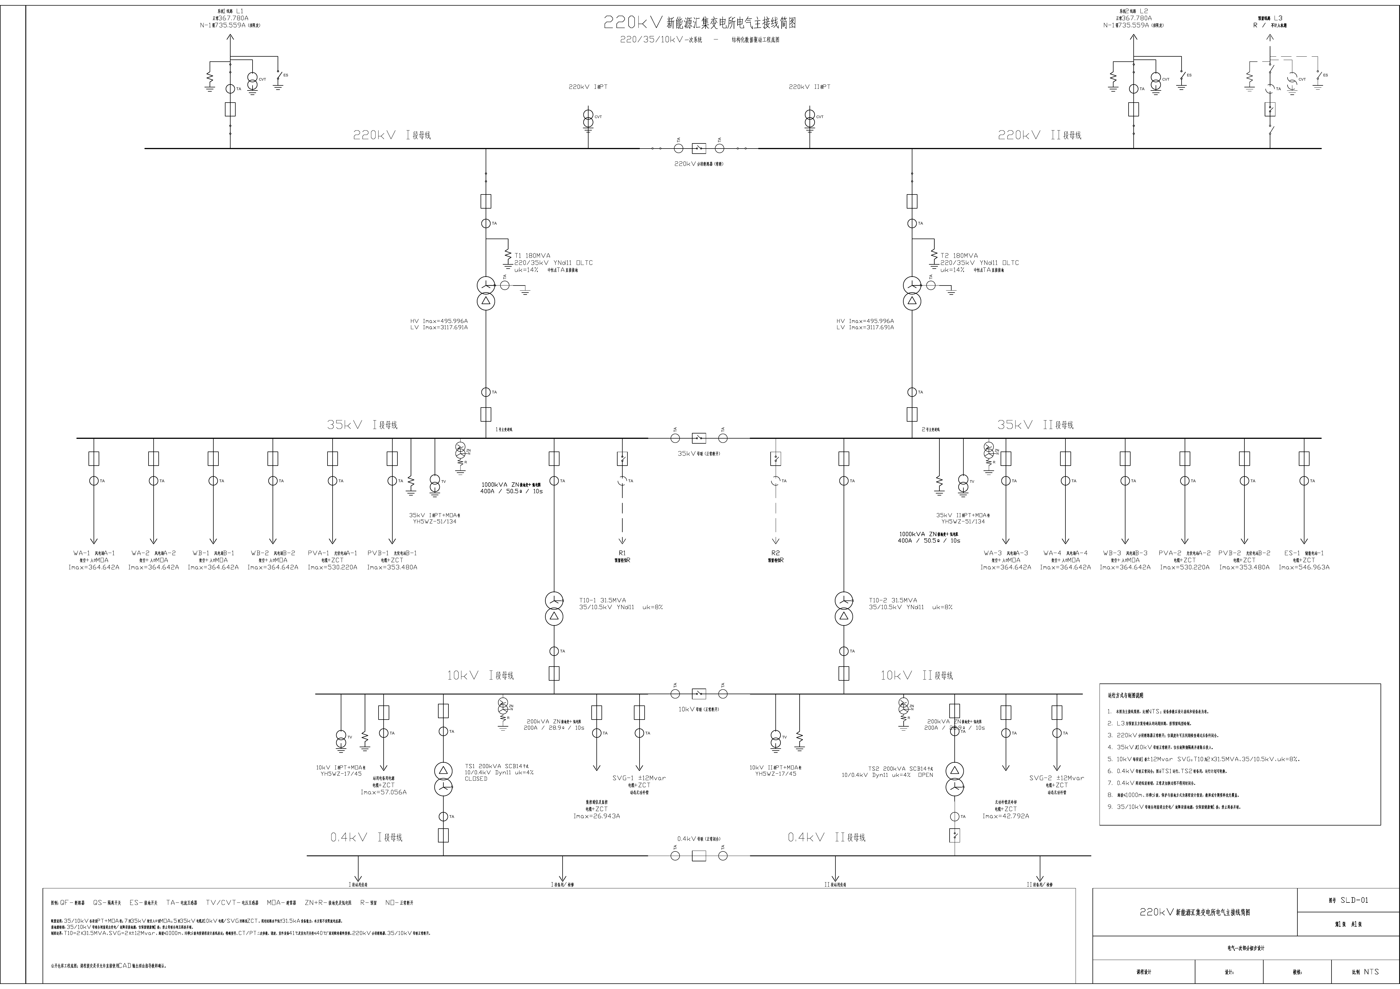
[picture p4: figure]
图1-1 SLD-01 220kV新能源汇集变电所电气主接线简图（A1，NTS，课程设计底图）

图1-1 SLD-01 220kV新能源汇集变电所电气主接线简图（A1，NTS，课程设计底图）

## 1.5 正常、条件与禁止运行方式

运行方式是后续持续电流和短路电流选取的前提。正常方式强调电源分列、故障影响受控；条件方式用于事故转供或系统许可下的临时操作；禁止方式只保留为误操作敏感性和联锁设计依据，不得用来提高日常设备负荷能力。

表1-5 运行方式门控

类别 | 运行方式 | 处理原则
允许 | 220/35/10kV分段分列；0.4kV单台所用变带两段 | 正常运行基准
条件允许 | 220kV分段闭合 | 调度许可并同期检查后方可闭合
事故转供 | 一台主变或一台T10退出后闭合下一级母联 | 先隔离故障源；退出受电段接地源，仅保留健康侧1套
禁止 | 两台健康主变经35kV母联并列 | 仅保留短路敏感性，不作为运行方式
禁止 | 两台健康T10经10kV母联并列 | 联锁闭锁；避免短路电流显著上升
禁止 | 35/10kV母联闭合且两套接地源同时投入 | 低电阻并联会改变接地故障电流与保护配合
禁止 | 两台所用变经0.4kV并列 | 两进线与母联设置电气、机械联锁

发生主变或T10故障时，事故转供按下列顺序进行：

1. 保护动作切除故障设备，并确认相应断路器、隔离开关已形成可靠电气隔离。
2. 核对健康电源、母线和联络回路的电压、容量、持续电流及短路职责，确认转供后不超过本报告的控制值。
3. 35kV或10kV母联合闸前，先退出受电侧或故障侧接地变+低电阻，仅保留健康电源侧1套接地源。
4. 满足同期、闭锁和调度许可后闭合母联；主变N-1时同步执行新能源限发，使存活主变负荷不超过180MVA。
5. 故障设备恢复、母联重新断开后，再恢复每个独立带电母线段各1套接地源。

结果分析：两套低电阻接地源经母联并联会降低等效接地电阻、改变目标单相接地电流和保护配合，因此“母联已闭合且两套接地源同时投入”被明确列为禁止状态。相同地，两台健康主变或T10并列会显著抬高短路电流，两台所用变并列还可能形成低压环流，均应由电气和机械联锁阻止。

# 第二章 负荷计算及变压器选择

## 2.1 35kV与10kV综合负荷

35kV新能源负荷按各项视在功率求和，再计0.95最大同时出力系数和5%线损；单回馈线电流按各类最大负荷在回路间平均分配，不重复乘同时系数。10kV辅助负荷按0.80同时系数和5%线损计算。

Sᵢ = Pᵢ / cosφᵢ (2-1)

I = S / (√3 U) (2-2)

式中：Pᵢ、Sᵢ分别为第i类负荷的有功功率和视在功率，cosφᵢ为功率因数；U为三相线电压，当S以MVA、U以kV代入时，I的结果为kA，换算为A需乘1000。

35kV五类负荷的视在功率分别为84.210526、63.157895、61.224490、40.816327和31.578947MVA，标量合计为280.988185MVA。主变容量按下式计入同时出力和线损：

S35 = 280.988185 × 0.95 × (1 + 0.05) = 280.285714 MVA (2-3)

10kV三类辅助负荷原始视在功率合计2.091503MVA，按0.80同时系数和5%线损得到1.756863MVA。该负荷在主变主校核中不与35kV汇集容量重复叠加，只作为保守敏感性保留。

表2-1 综合负荷计算结果

项目 | 结果 | 说明
35kV原始视在功率 | 280.988MVA | 270MW按逐项功率因数折算
计0.95同时出力 | 266.939MVA | 主变容量计算用
再计5%线损 | 280.286MVA | 本期主变校核容量
10kV辅助负荷 | 1.757MVA | 计0.80同时系数和5%线损
保守叠加10kV敏感性 | 282.043MVA | 不替代主校核口径

结果分析：将各项视在功率标量相加得到280.285714MVA，属于偏保守的课程口径；若先分别合成P、Q再求模，结果为279.840482MVA，两者相差0.445232MVA。为与任务书和既有容量计算保持一致，主变选择采用前者，向量结果只用于数量级复核。

## 2.2 主变压器选择

选用2×180MVA、220/35kV双绕组油浸式有载调压主变，联结组YNd11，短路电压uk=14%。220kV星形中性点经专用中性点CT直接接地，35kV侧为三角形绕组。两台正常运行时每台承担140.143MVA，负载率77.857%。一台退出时，另一台额定容量只能覆盖64.220%的最大计算负荷，缺口100.286MVA，因此按任务书允许的新能源限发策略，基准限发比例为35.780%。

主变采用220/35kV双绕组方案，并以两台独立35/10.5kV T10承担10kV电源功能。与三绕组主变相比，该方案使10kV辅助系统和SVG运行方式更独立，便于两段母线分别检修与控制；同时会增加T10及其35kV馈线间隔。结合任务书已给的2×180MVA容量和当前辅助系统规模，本阶段采用双绕组主变加T10方案。

Snormal,each = 280.285714 / 2 = 140.142857 MVA (2-4)

βnormal = 140.142857 / 180 × 100% = 77.857% (2-5)

KN-1 = 180 / 280.285714 × 100% = 64.220% (2-6)

Kcurtail = (1 − 180 / 280.285714) × 100% = 35.780% (2-7)

表2-2 主变容量与N-1校验

指标 | 计算值 | 结论
装机容量 | 360.000MVA | 2×180MVA
正常每台负荷 | 140.143MVA | 均衡分配
正常负载率 | 77.857% | 满足课程设计经济运行要求
N-1覆盖比例 | 64.220% | 低于全部最大负荷
N-1容量缺口 | 100.286MVA | 通过新能源限发处理
N-1限发比例 | 35.780% | 当前总N-1控制因素

结果分析：2×180MVA能够满足正常方式，但不能在不采取控制措施时满足全部最大出力下的主变N-1。方案成立的运行条件是新能源场站具备快速限发能力，并在事故转供前把存活主变负荷限制在180MVA以内。1.05系数仅用于主变回路设备持续电流预筛，不表示主变本体可以长期按189MVA运行。

## 2.3 10kV电源变与无功补偿

10kV由2×31.5MVA、35/10.5kV、YNd11、uk=8%的T10供电，每段配置±12Mvar SVG。按目标功率因数0.98，需补偿21.8875Mvar；选24Mvar后裕度9.65%，pf≈0.98147。T10正常负载率39.58%，N-1最严吸收工况79.17%。

无功补偿按不抵扣新能源变流器自身无功裕度的保守口径计算。35kV汇集负荷与10kV辅助负荷计损耗后，合计有功P=270.837MW，无功Q=76.883260Mvar。目标功率因数对应的允许无功为P·tan(arccos0.98)，两者之差即所需补偿容量。

Qc = Q − P tan(arccos cosφtarget) (2-8)

Qc = 76.883260 − 270.837 × tan(arccos0.98) = 21.887462 Mvar (2-9)

Kmargin = (24 / 21.887462 − 1) × 100% = 9.65% (2-10)

每台T10正常均衡承担12.468716MVA，负载率39.583%；N-1全吸收无功工况为24.937431MVA，负载率79.166%。因此2×31.5MVA既覆盖正常分段运行，也为单台T10事故承担两套SVG的最严课程场景保留约20%的容量余量。

表2-3 T10与SVG配置

设备 | 配置 | 正常状态 | 校验结论
T10-1、T10-2 | 2×31.5MVA，35/10.5kV，YNd11，uk=8% | 各带一段10kV母线 | N-1最严79.17%
SVG-1、SVG-2 | 2×±12Mvar | 每段一套，电压/无功/功率因数控制 | 补偿后pf≈0.98147

注：容量属于任务书缺项下的课程冻结值，最终由无功电压与谐波专题覆盖。

结果分析：两套SVG分置于10kV-I、II段可在正常方式下就地调节电压、无功或功率因数。24Mvar只比计算需求高9.65%，属于合理但不宽裕的课程选择；最终容量仍须由并网点电压偏差、动态响应、谐波和变流器持续过载能力专题复核。

## 2.4 所用变压器选择

扣除110kV不适用项后，连续负荷96.3kW，最严场景需192.913kVA。选用2×200kVA、10/0.4kV、SCB14干式、Dyn11、uk=4%的所用变，每台可带全部经常负荷并留约10%裕度。正常一台供电且0.4kV母联闭合，另一台及进线暗备用。

所用电负荷按连续、经常短时和不经常短时分类。基准场景取全部连续负荷96.3kW加空气压缩机同时投入值22.0kW，合计118.3kW；最严经常场景把两台空气压缩机44.0kW全部计入，合计140.3kW。110kV配电装置和110kV断路器加热负荷因本项目无该电压等级而明确剔除。

ST = Pscenario (1 + Km) / cosφ (2-11)

式中：Km为容量裕度，本设计取10%；所用电综合功率因数按课程假设取0.80。

Sbase = 118.3 × 1.10 / 0.80 = 162.6625 kVA (2-12)

Sworst = 140.3 × 1.10 / 0.80 = 192.9125 kVA (2-13)

结果分析：按最严场景选择200kVA标准容量，每台所用变均可单独承担全部课程负荷。暗备用方式避免两台变压器并列，同时通过母联闭合保证正常仅一台运行即可带两段低压母线；备用投入前仍须先切除故障进线并满足防并列联锁。

# 第三章 最大持续工作电流及短路计算

## 3.1 各回路最大持续工作电流

最大持续工作电流用于确定断路器、隔离开关、CT、母线和开关柜的额定电流。馈线按本类最大出力、实际回路数和5%线损计算，不再乘全站0.95同时出力系数；主变、T10和SVG回路则按设备额定容量乘1.05选型裕度确定。不同口径服务于不同对象，不能相互替代。

Ifeeder = P (1 + kloss) / (n √3 U cosφ) (3-1)

式中：n为同类负荷回路数，kloss=0.05；馈线计算反映单回线路可能承担的本类最大出力。

IES = 30 × 1.05 / (1 × √3 × 35 × 0.95) × 1000 = 546.963 A (3-2)

储能馈线只有1回，因而形成35kV单回馈线最大电流546.963A；风电A、B虽总容量不同，但80MW/4回与60MW/3回的单回有功均为20MW，故两者单回设计电流相同，均为364.642A。

表3-1 35kV单回馈线设计电流

负荷类别 | 回路数 | 单回电流/A | 计算口径
风电场A | 4 | 364.642 | 计5%线损，不乘0.95
风电场B | 3 | 364.642 | 计5%线损，不乘0.95
光伏电站A | 2 | 530.220 | 计5%线损，不乘0.95
光伏电站B | 2 | 353.480 | 计5%线损，不乘0.95
储能电站 | 1 | 546.963 | 计5%线损，不乘0.95

表3-2 主要回路持续电流职责

回路 | 最大持续电流/A | 设计说明
220kV线路间隔 | 735.559 | 一回退出时另一回承担全部本期送出
220kV分段 | 735.559 | 一段事故转供全部本期送出功率的课程保守职责
主变220kV侧 | 495.996 | 180MVA额定电流×1.05
主变35kV侧/35kV母联 | 3117.691 | 180MVA额定电流×1.05
35kV-I段 | 2230.732 | 按I段实际6回馈线累加
35kV-II段 | 2404.371 | 按II段实际6回馈线累加
T10 35kV侧 | 545.596 | 31.5MVA额定电流×1.05
T10 10kV设备口径 | 1909.586 | 按10kV开关设备电压基准×1.05
单套SVG馈线 | 692.820 | 12Mvar、10.5kV额定电流×1.05

35kV母线段存在三个容易混淆的电流口径。按未计线损的各馈线基础电流和实际分配累加，I、II段分别为2230.732A和2404.371A；若按各馈线基础视在功率标量求和后统一施加0.95同时系数和5%线损，则分别约为2225.155A和2398.360A；按各段P、Q向量合成则分别为2221.564A和2394.612A。若把每回馈线均按自身最大值计5%线损后直接相加，则分别约为2342.268A和2524.590A。前三者用于不同的正常负荷分析，最后一种是各馈线同时满出的保守和。

结果分析：主变进线、35kV母联及35kV主母线的最终设备持续职责不采用上述较小的正常段电流，而按单台主变额定电流1.05倍取3117.691A，以覆盖事故转供。35kV 3150A开关柜相对该职责仅余32.309A，后续必须维持室内温度不高于40℃并取得厂家温升确认。

## 3.2 220kV线路导线校核与N-1

任务书指定220kV送出导线为LGJ-400/50。课程参考载流量592A对应环境25℃、导体允许温度70℃，本站最高环境温度为41℃，因此必须先进行温度修正，再分别与正常双回和单回事故电流比较。

KT = √[(θallow − θproject)/(θallow − θreference)] (3-3)

KT = √[(70 − 41)/(70 − 25)] = 0.802773 (3-4)

Iallow,41 = 592 × 0.802773 = 475.242 A (3-5)

LGJ-400/50课程参考载流量为592A（25℃环境、70℃导体）。41℃修正系数0.802773，课程允许值475.242A；正常每回367.780A通过。单回全送735.559A时需限发35.390%；主变N-1限发后线路电流472.377A，余量2.864A，因此当前仍由主变容量控制。

Kline-curtail = (1 − 475.242 / 735.559) × 100% = 35.390% (3-6)

结果分析：主变N-1限发后，220kV线路电流为472.377A，比课程允许值只低2.864A。主变限发比例虽然略严于导线单独约束，但线路热裕度非常小；真实工程必须用明确风速、日照、环境和导体温度条件下的厂家热额定值覆盖本课程参考。

证据边界：592A来自旧版二手课程参数表，仅作保守校核；厂家热额定值须结合风速、日照、环境及导体温度复核。

## 3.3 短路计算方法与计算点

短路初算采用任务书规定的100MVA基准容量和230/37/10.5kV平均额定电压。网络按标幺电抗法处理，初步忽略电阻；主变电抗按uk=14%，T10按uk=8%。新能源和SVG贡献在敏感性中按额定电流1.1~1.2倍算术叠加，峰值采用课程系数k=1.8。该方法用于课程设备等级预筛，不替代GB/T 15544.1-2023完整计算。

计算时先把系统、线路和变压器电抗统一换算到100MVA基准，再按实际运行方式进行串并联组合。220kV分列时每段只有对应系统和线路路径；220kV分段条件闭合时两条路径并联；向35kV、10kV计算点继续串入主变和T10电抗。

X*sys = xc × SB / Ssys (3-7)

X*line = xL × SB / UB² (3-8)

X*T = (uk% / 100) × SB / SN (3-9)

Ik = SB / (√3 UB XΣ*) (3-10)

ip = √2 k Ik (3-11)

式中：xc为系统在自身容量基准上的标幺电抗，x为线路单位长度电抗，L为线路长度，uk为变压器短路电压百分数；XΣ*为故障点至各电源的等值标幺电抗。

系统1、系统2连同L1、L2后的路径电抗分别为0.069597和0.086772，分段闭合后的并联等值为0.038621。220kV分段闭合电网分量为6.500kA，叠加新能源上界后为7.385kA。

35kV条件性最大综合短路电流为16.291kA，10kV条件性最大值为15.638kA。两台健康主变或两台健康T10并列时分别升至25.694kA和28.472kA，只用于联锁和误操作风险提示。

表3-3 短路职责分级（禁止并列值仅作联锁与误操作风险提示）

电压级 | 正常必选/kA | 条件预校核/kA | 禁并敏感/kA | 课程峰值/kA
220kV | 4.033 | 7.385 | — | 18.798
35kV | 13.265 | 16.291 | 25.694 | 41.470
10kV | 14.492 | 15.638 | 28.472 | 39.808

结果分析：开关设备的条件性预校核职责取220/35/10kV的7.385、16.291和15.638kA，而不是只取正常分列的较小值。禁止并列敏感性不作为日常必选开断职责，但若联锁不能可靠阻止该方式，就必须重新提高设备等级或改变系统运行方案。

# 第四章 主要电气设备选择

## 4.1 选择与校验原则

一次设备按额定电压、最大持续工作电流、短路开断、关合/峰值耐受和热稳定逐项校验。热稳定等值时间按后备保护1.00s与断路器总开断0.08s向上取1.10s。环境最高温度41℃、海拔≤1000m和污秽d级作为课程设计条件。室外主变、T10、可能的户外SVG及导体按41℃复核，35/10kV室内开关柜统一按受控≤40℃；厂家精确服务条件未取得时，设备状态只能写为额定值等级预筛通过。

Ue ≥ Un；Ie ≥ Imax (4-1)

Ibr ≥ Ik；ipeak,rated ≥ ip (4-2)

Ith² tr ≥ Ik² t (4-3)

式中：Ue、Ie为设备额定电压和额定电流；Ibr为断路器额定开断电流；ipeak,rated为额定峰值耐受或关合能力；Ith、tr为设备短时耐受电流及其额定持续时间。

设备选择按“先确定回路职责、再选择额定值等级、最后逐项比较”的顺序进行。持续电流取正常或事故方式中的较大值；短路开断和峰值采用条件性最大课程职责；热稳定等值时间由1.00s后备保护和0.08s全开断时间相加后向上取1.10s。同一设备只有所有适用数值条件满足，且未完成的厂家/环境项目被明确保留时，才能写为“课程预筛通过”。

## 4.2 断路器、隔离开关和开关柜

表4-1 主要开关设备课程目标等级

安装位置 | 目标等级 | 额定电流/A | 开断/kA | 峰值/kA | 热稳定
220kV线路/主变/分段断路器 | 252kV户外SF6 | 3150 | 50 | 125 | 50kA/3s
220kV隔离开关 | 252kV户外 | 3150 | — | 125 | 50kA/3s
35kV主变进线/母联柜 | 40.5kV金属铠装 | 3150 | 31.5 | 80 | 31.5kA/4s
35kV馈线/T10柜 | 40.5kV金属铠装 | 1250 | 31.5 | 80 | 31.5kA/4s
35kV接地变馈线柜 | 40.5kV金属铠装 | 1250 | 31.5 | 80 | 31.5kA/4s
10kV进线/母联柜 | 12kV金属铠装 | 2500 | 31.5 | 80 | 31.5kA/4s
10kV SVG/辅助馈线柜 | 12kV金属铠装 | 1250 | 31.5 | 80 | 31.5kA/4s
10kV接地变馈线柜 | 12kV金属铠装 | 1250 | 31.5 | 80 | 31.5kA/4s

注：35kV 3150A相对3117.691A仅余32.309A（约1.04%）；10kV已升级为2500A，相对1909.586A余590.414A。接地变馈线分别覆盖400A/200A课程职责。35/10kV柜统一按室内受控≤40℃，仍须由厂家温升和精确柜型确认。

以35kV主变进线柜为例，额定电流3150A与职责3117.691A相比仅有32.309A裕度，约为1.04%；额定开断电流31.5kA高于条件性短路职责16.291kA，额定峰值耐受80kA高于41.470kA。热稳定比较为31.5²×4=3969kA²·s，大于16.291²×1.10=291.936kA²·s。

10kV进线和母联采用2500A而非较低等级，是因为T10按10kV设备口径并计1.05裕度后的职责达到1909.586A。2500A方案保留590.414A裕度，31.5kA开断和80kA峰值等级也分别覆盖15.638kA和39.808kA课程职责。

结果分析：35kV 3150A等级的短路和热稳定裕度较大，但持续电流裕度很小，故其通过结论必须附带“开关室≤40℃、通风空调可靠、厂家温升试验和精确柜型确认”的条件。不能因短路裕度充足而忽略长期发热控制。

表4-2 已审查设备的适用性结论

设备 | 课程结论 | 依据与复核条件
限流电抗器 | 35/10kV均不设置 | 16.291/15.638kA低于31.5kA设备能力；最终短路职责超过31.5kA时重审
高压熔断器 | 不作为主回路设备 | 仅在35/10kV PT柜按厂家方案设置一次熔断器及二次保护
阻波器 | 当前不配置 | 仅在通信专业确定电力线载波通信及耦合方案时配置

负面设备选择同样需要给出计算依据。35kV和10kV条件性短路职责分别为16.291kA和15.638kA，均明显低于所选31.5kA开关设备能力，因此本课程方案不设置限流电抗器。高压熔断器只可能作为PT柜成套保护元件，不承担主回路开断；阻波器则取决于通信专业是否采用电力线载波，当前任务书未给该条件。

## 4.3 CT与PT/CVT课程配置

各电压等级每段主母线配置电压互感器；凡装有断路器的回路原则上配置三相CT，电缆单相接地保护另设零序CT。下表冻结一次变比、课程芯级组合和职责，但负担、饱和、拐点电压、暂态性能、窗口尺寸、电缆压降和精确型号仍等待保护计量清册。

表4-3 CT课程目标配置

位置 | 变比 | 芯级目标 | 短时/峰值
220kV线路 | 1000/1A | 0.2S、0.5、5P30，按需PX | 50kA/3s；125kA
220kV主变 | 600/1A | 0.2S、0.5、5P30、PX | 50kA/3s；125kA
主变220kV中性点 | 600/1A | PX限制接地故障、5P30中性点过流 | 单相接地/零序专题待定
220kV分段 | 1000/1A | 0.5、5P30母线保护、PX母差 | 50kA/3s；125kA
35kV进线/母联 | 4000/1A | 0.2S、0.5、5P30、PX | 31.5kA/4s；80kA
35kV馈线/T10 | 800/1A | 0.2S、0.5、5P30 | 31.5kA/4s；80kA
10kV进线/母联 | 2500/1A | 0.2S、0.5、5P30、PX | 31.5kA/4s；80kA
10kV馈线/SVG | 1000/1A | 0.2S、0.5、5P30 | 31.5kA/4s；80kA
35kV电缆馈线ZCT | 100/1A | 5P20或厂家等效零序保护级 | 5回；一次剩余电流目标400A
10kV电缆/SVG ZCT | 50/1A | 5P20或厂家等效零序保护级 | 2回SVG+3类辅助；目标200A

注：短时栏峰值单位为kA；ZCT职责与三相CT分开，三相电缆芯线同穿窗口而屏蔽接地回流线不得穿入。课程芯级组合不作为订货清册。

CT一次变比先按最大持续电流选择，再检查短时、峰值及保护用途。35kV进线4000/1A覆盖3117.691A，10kV进线2500/1A覆盖1909.586A，35kV馈线800/1A覆盖最大单回546.963A；相同电压级内不机械统一变比，以避免馈线测量分辨率过低。0.2S/0.5级分别面向计量和测量，5P30及PX课程目标用于过流、差动或母差保护。

主变220kV中性点CT的持续和短路职责不能沿用主变相回路的三相短路电流。其600/1A、PX+5P30仅为课程配置目标，最终必须依据单相接地、零序网络、保护负担和拐点电压专题确定。35/10kV电缆回路另设ZCT，用于剩余电流和单相接地保护，窗口尺寸及屏蔽层接地回流路径需与电缆敷设共同复核。

表4-4 PT/CVT课程目标配置

电压级 | 型式与一次电压 | 二次绕组 | 准确级
220kV | 每段单相CVT组；220/√3kV | 100/√3V测量、100/√3V保护、100/3V开口三角 | 0.2、3P
35kV | 每段三台单相电磁式VT；35/√3kV | 100/√3V测量、100/√3V保护、100/3V开口三角 | 0.5、3P
10kV | 每段三台单相电磁式VT；10/√3kV | 100/√3V测量、100/√3V保护、100/3V开口三角 | 0.5、3P

注：容量、铁磁谐振、同期抽取和厂家精确型号仍待二次专业复核。

结果分析：PT/CVT配置满足测量、保护和开口三角零序电压取得的课程功能，但一次/二次电压和准确级并不能代替容量校验。最终二次负荷、导线压降、铁磁谐振抑制、CVT暂态特性及同期抽取回路应由保护计量清册和厂家资料闭合。

## 4.4 MOA、中性点接地与接地开关

表4-5 MOA参数与绝缘裕度课程预筛

电压级/型号 | Ur/Uc/In/残压 | 绝缘裕度 | 配置位置
220kV YH10W-204/532 | 204kV/159kV/10kA/≤532kV | Uc余13.508kV；950/532=1.786＞1.15 | 线路入口、主变高压端
35kV YH5WZ-51/134 | 51kV/40.8kV/5kA/≤134kV | Uc仅余0.300kV（约0.74%）；185/134=1.381＞1.15 | 母线PT柜、主变端、7回架空入口
10kV YH5WZ-17/45 | 17kV/13.6kV/5kA/≤45kV | Uc余1.600kV；75/45=1.667＞1.15 | 母线PT柜、T10/SVG端

注：仅为课程预筛；35kV的TOV、能量、引线压降、线路放电等级和精确型号待专题复核。

MOA课程预筛包括持续运行电压和雷电保护裕度两项。持续运行电压Uc应覆盖相应接地方式下的长期相对地电压，保护裕度以被保护设备雷电冲击耐受电压LIWV与避雷器残压之比进行初步判断。

Uc ≥ Uc,required；Kp = LIWV / Ures (4-4)

220kV设备最高电压252kV，有效接地课程口径下Uc,required=252/√3=145.492kV；选用159kV Uc后裕度13.508kV，LIWV/残压=1.786。

35kV系统按非有效接地课程上界取Uc,required=40.500kV，所选40.8kV Uc仅余0.300kV，约0.74%。该裕度是本组MOA预筛中最薄弱的一项，必须由10s TOV、能量和厂家曲线复核。

表4-6 接地参数与接地开关课程配置

位置 | 课程配置 | 等级/参数 | 工程边界
主变220kV中性点 | 经600/1A中性点CT直接接地 | PX+5P30课程目标 | 持续/短时/峰值按单相接地与零序专题，不沿用三相回路职责
35kV-I/II段 | 每段1000kVA ZN接地变+低电阻 | 400A/10s；R≈50.5Ω | 2套；1250A馈线柜；600/1A相CT+400/1A中性点CT
10kV-I/II段 | 每段200kVA ZN接地变+低电阻 | 200A/10s；R≈28.9Ω | 2套；1250A馈线柜；300/1A相CT+200/1A中性点CT
35/10kV母联转供 | 合母联前退出受电/故障段接地源 | 仅保留健康侧1套 | 联锁禁止母联合闸且两套接地源并联；分列后恢复每段1套
220kV线路侧ES | 线路侧QS配常开ES | 252kV、50kA/3s、125kA峰值 | 感应电流开合等级待厂家专题
35/10kV柜内ES | 柜内常开并设机械/电气联锁 | 31.5kA/4s、80kA峰值 | 精确柜型和联锁图待核

35kV和10kV绕组均不能直接提供中性点，因此每段采用ZN接地变形成中性点，并串入低电阻限制单相接地电流。电阻和接地变容量按相电压、目标接地电流及10s短时热容量计算。

Uφ = Un/√3；R = Uφ/Ig；Seq = Uφ Ig (4-5)

ST,min = Seq / Koverload (4-6)

35kV系统Uφ=20.2073kV，R=50.518Ω，取50.5Ω；10s等效功率8.083MVA，按10倍短时过载折算最小容量808.290kVA，故选1000kVA。

10kV系统相应得到R=28.868Ω，取28.9Ω；10s等效功率1.155MVA，最小接地变容量115.470kVA，故选200kVA。上述容量采用课程短时过载系数，不能直接作为订货参数。

结果分析：每段设置1套接地源可使分列运行时各母线都有明确的零序回路；母联合闸时只保留健康侧1套，既维持接地故障电流目标，又避免两套电阻并联。最终仍需由接地变/NGR厂家统一校核零序阻抗、损耗、温升、CT饱和和保护配合。

防雷与接地边界：MOA绝缘配合不等于直击雷保护完成。缺少雷暴日、建筑高度、土壤电阻率和接地网几何时，不虚构避雷针保护范围、接地网电阻、接触电压或跨步电压。

## 4.5 母线、绝缘子与套管

母线型式已从原则选择推进到课程级截面和性能预筛。220kV管母完成载流、热稳、简化弯曲和电晕；35/10kV矩形母线只完成载流与热稳，电动力、支撑机械、连接金具和厂家温升仍待复核。

母线热稳定采用铝导体课程常数C=87和等值时间1.10s。先由几何尺寸求截面积，再计算允许短时电流，并与本电压级条件性最大短路职责比较。长期载流量另按参考载流量、环境温度和布置方式校核。

Ith,allow = C S / (1000 √t) (4-7)

Smin = 1000 Ik √t / C (4-8)

式中：S为单相导体总截面积，单位mm²；Ith,allow和Ik以kA计，t=1.10s。

表4-7 母线课程级选择

电压级 | 课程选择 | 持续/热稳定 | 补充校验
220kV | 铝合金管母Φ100/90mm | 1605.546A＞735.559A；123.785kA＞7.385kA | 弯曲应力10.048＜70MPa；电晕330.444＞145.492kV
35kV | 每相3×125×10mm矩形铝母线 | 4194A＞3117.691A；311.067kA＞16.291kA | 机械/电动力和厂家温升待核
10kV | 每相2×125×10mm矩形铝母线 | 3282A＞1909.586A；207.378kA＞15.638kA | 机械/电动力和厂家温升待核

220kV Φ100/90mm管母截面积为1492.257mm²，41℃修正后载流量1605.546A，1.10s热稳定允许电流123.785kA。两者分别高于735.559A持续职责和7.385kA短路职责。

简化电动力计算按3.0m相距、8.0m支撑跨距和1.8动载系数进行，得到弯曲应力10.048MPa，低于70MPa课程允许值；Peek公式得到电晕起始相电压330.444kV，高于最高运行相电压145.492kV。

结果分析：220kV管母已形成载流、热稳、简化机械和电晕的完整课程链。35/10kV矩形母线虽在载流和热稳定上裕度充足，但缺少支撑跨距、相间距、固有频率、连接受力和厂家温升资料，因此只能写为“已完成电气与热稳定预筛，机械动稳定待核”。

表4-8 绝缘子与套管课程目标

电压级 | 最高电压/LIWV | 持续/短时/峰值课程目标 | 尚需厂家数据
220kV | 252/950kV | 630A；50kA/3s；125kA | d级；爬距、机械破坏负荷、精确型号
35kV | 40.5/185kV | 4000A；31.5kA/4s；80kA | 户外接口d级；爬距、机械与安装图
10kV | 12/75kV | 2500A；31.5kA/4s；80kA | 户外接口d级；爬距、机械与安装图

注：当前35/10kV方案无裸母线直接穿墙，独立裸母线穿墙套管不单列；方案改变时重新选择。

# 第五章 配电装置设计与运行

## 5.1 配电装置型式

表5-1 配电装置型式选择

电压等级 | 采用型式 | 选择理由
220kV | 户外AIS、分相中型 | 回路不多、课程断面表达清晰、扩建方便、投资低于GIS
35kV | 室内金属铠装移开式开关柜 | 回路多、分段明确、运行维护方便
10kV | 室内金属铠装移开式开关柜 | 适合T10进线、SVG和辅助负荷分柜组织
0.4kV | 室内低压开关柜 | 单母线分段、暗备用和联锁切换

220kV侧本期回路数量较少，户外AIS能够把母线、隔离开关、断路器、CT/CVT、MOA和构架的设备链清晰展开，便于检修隔离、远期L3扩建以及课程平面与断面表达。GIS虽占地较小、环境适应性好，但设备集成度和投资较高，且任务书未给出必须采用紧凑布置的场址约束，因此本阶段不选。

35kV和10kV回路多、分段与馈线组织明确，采用室内金属铠装移开式开关柜可缩短户外导体长度并便于防误联锁。0.4kV低压柜则围绕两进线一母联的暗备用方式配置，正常只有一台所用变进线带电。

## 5.2 220kV户外AIS课程几何

表5-2 平面与断面主要参数

参数 | 课程采用值 | 说明
站区范围 | 145m×90m | 课程总体边界
道路宽度 | 4m | 设备运输与检修通道
相间距 | 4m | 典型三相设备中心距
典型功能中心距 | 14m | 课程间隔节距
母线标高 | 9.0m | 断面课程值
出线构架标高 | 14.5m | 向西北出线
主变构架标高 | 11.5m | 主变进线构架
母线至出线构架 | 29m | 平断面一致
母线至主变构架/中心 | 20m/27m | 平断面一致

表5-3 220kV屋外配电装置课程最小净距

类别 | 采用值/mm | 含义
A1 | 1800 | 带电部分至接地部分
A2 | 2000 | 不同相带电部分之间
B1 | 2550 | 带电部分至栅栏/运输轮廓等课程控制距离
B2 | 1900 | 带电部分至网状遮栏
C | 4300 | 无遮栏裸导体至地面
D | 3800 | 检修或不同时间带电部分的课程控制距离

注：取自课程讲义表7-2的220J列；施工设计仍须按DL/T 5352-2018全文复核。

平面与断面图共用145m×90m站区、4m道路、4m相间距和14m典型功能中心距。母线、线路构架及主变构架标高分别为9.0m、14.5m和11.5m，使电气净距、设备检修通道和导线引接关系能够在两类图纸中相互核对。课程几何不等于厂家基础图，但所有尺寸均有统一数据源，避免平面图、断面图各自估算。

结果分析：A1、A2、B1、B2、C、D净距分别按1800、2000、2550、1900、4300和3800mm控制课程底图。这些值用于建立可手绘临摹、可复核的布置基线；施工设计阶段仍须结合现行标准全文、海拔、设备外形、端子方向、运输荷载和基础尺寸重新校核。

## 5.3 事故运行与联锁

主变N-1时先切除并隔离故障主变，故障清除后闭合35kV母联，并把存活主变负荷限制在180MVA以内，按当前计算限发35.780%。一回220kV线路退出时，剩余线路也必须受LGJ-400/50温度修正载流量约束。T10或所用变切换均先隔离故障进线，再投入备用电源，严禁两个健康电源通过低压母联并列。35/10kV母联合闸前还须退出受电侧接地源，仅保留健康电源侧1套；禁止母联闭合且两套低电阻接地源并联。

一回220kV线路退出时，剩余线路不能直接承担280.286MVA全部出力，因为41℃课程允许载流量只有475.242A。执行主变N-1限发后线路电流为472.377A，虽然满足当前课程参考，但仅余2.864A，因此事故运行时应同时监视主变容量和线路温度。

T10事故转供除检查31.5MVA容量外，还应限制两套SVG在吸收无功方向的最严组合；课程计算得到单台T10最大负载率79.17%。所用变切换则遵循“先断故障进线、再确认母联和备用进线闭锁、最后投入备用”的顺序，防止两台低压变压器并列。

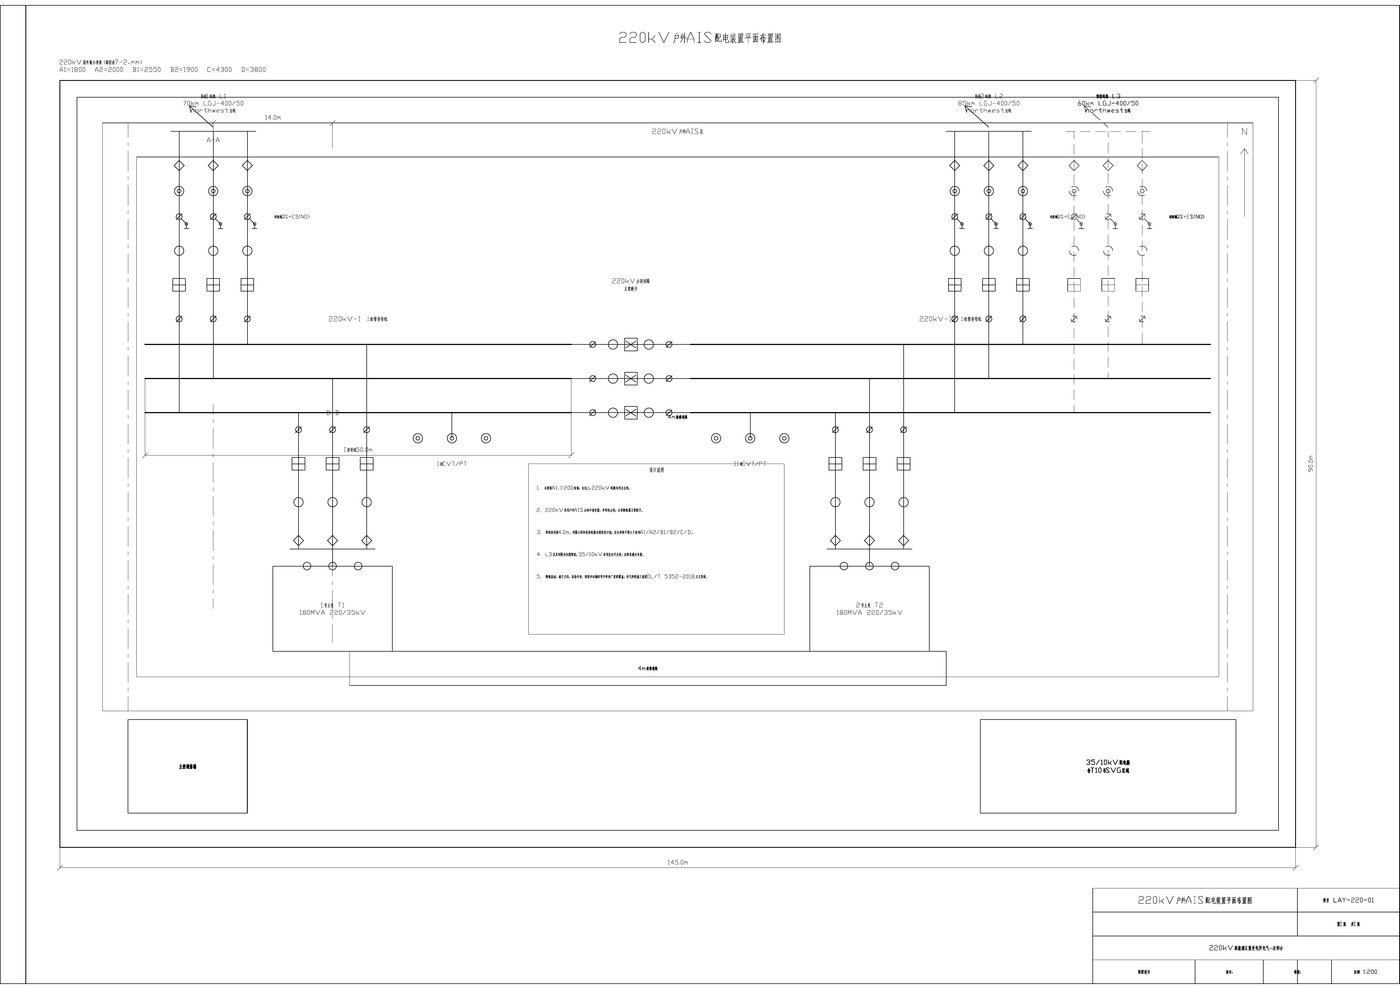
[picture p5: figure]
图5-1 LAY-220-01 220kV户外AIS配电装置平面布置图（A1，1:200，课程设计底图）

图5-1 LAY-220-01 220kV户外AIS配电装置平面布置图（A1，1:200，课程设计底图）

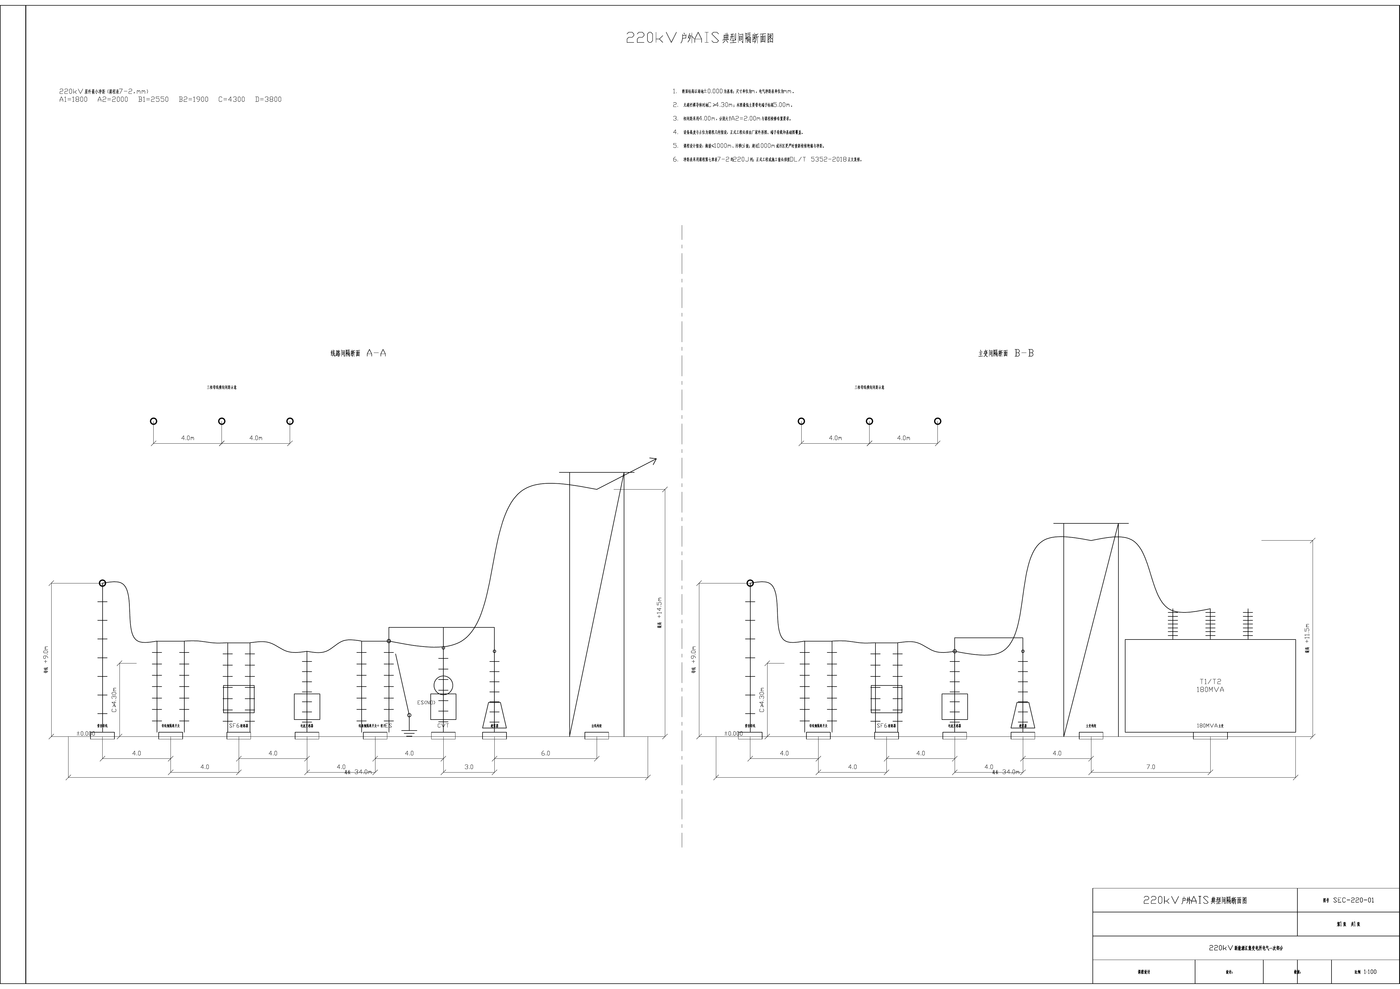
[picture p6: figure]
图5-2 SEC-220-01 220kV户外AIS典型间隔断面图（A1，1:100，课程设计底图）

图5-2 SEC-220-01 220kV户外AIS典型间隔断面图（A1，1:100，课程设计底图）

图5-3 SEC-220-L1-01 220kV I段L1线路间隔断面详图（A1，1:50，课程设计增强详图）

图5-3 SEC-220-L1-01 220kV I段L1线路间隔断面详图（A1，1:50，课程设计增强详图）

# 第六章 结论与设计边界

## 6.1 主要设计结论

本设计形成了从主接线、负荷、短路到设备和布置的同源闭环。各项结论并非孤立的表格结果：主接线确定运行方式，运行方式决定持续电流与短路职责，职责再控制设备等级、母线截面和事故操作边界。

- 主接线采用220kV、35kV和10kV单母线分段；220kV分段断路器、35/10kV母联正常断开，0.4kV母联正常闭合。
- 主变采用2×180MVA、220/35kV、YNd11、uk=14%，正常负载率77.857%；N-1需限发35.780%。
- 采用2×31.5MVA、35/10.5kV、YNd11、uk=8%的T10和2×±12Mvar SVG，补偿后功率因数约0.98147。
- 所用变采用2×200kVA、SCB14、Dyn11、uk=4%，暗备用，正常一台运行。
- 10kV条件性最大课程短路电流15.638kA，设备按31.5kA开断等级预筛。
- 220kV配电装置采用户外AIS分相中型，35/10kV采用室内金属铠装移开式开关柜。
- 35kV采用2×1000kVA、10kV采用2×200kVA ZN接地变+低电阻；正常每段1套，母联转供时仅保留健康侧1套。
- CAD按三张必交图加SEC-220-L1-01增强详图组织，共四张A1图。

结果分析：本方案的主要约束是主变N-1限发35.780%、LGJ-400/50高温事故载流裕度很小、35kV 3150A柜持续电流裕度约1.04%，以及35kV MOA持续电压裕度仅约0.74%。这些项目均已在计算书中保留完整计算链，并在最终工程边界中列为优先复核项。

## 6.2 课程假设与待复核项目

课程设计必须在信息不完备时形成可检验方案，但不能把假设写成施工结论。下表按“当前已完成的课程闭环”和“仍需真实场址、标准全文、保护专题或厂家资料关闭的项目”进行分层，便于后续替换输入时同步重算、重绘和重写。

表6-1 课程冻结值与最终工程边界

项目 | 课程设计采用 | 最终工程复核
短路方法 | 100MVA标幺X-only；k=1.8；变流器1.1~1.2倍 | 按GB/T 15544.1-2023完整R/X、电压系数、κ和开断时刻
设备 | 额定值等级预筛 | 精确厂家型号、41℃修正、外绝缘与型式试验
无功 | 目标pf=0.98；2×±12Mvar | 无功电压、谐波与SVG动态专题
CT/PT/ZCT | 三相CT/PT目标及35/10kV电缆回路零序CT | 负担、饱和、暂态性能、窗口尺寸、二次容量和电缆压降
导体与母线 | 220kV载流/热稳/简化弯曲/电晕；35/10kV载流/热稳 | 35/10kV电动力与支撑机械、厂家温升、共振和连接金具
MOA | Ur/Uc/In/残压与LIWV裕度课程预筛 | 接地方式、10s TOV、能量、引线压降和厂家型号
场址与布置 | 海拔≤1000m、污秽d级、课程几何 | 真实场址、DL/T 5352全文和厂家外形基础图
接地与直击雷 | 接地设备包、母联切换顺序和设备接地接口 | 单相接地/零序、厂家联锁、土壤电阻率、接触/跨步电压和避雷针范围

## 6.3 图纸和计算成果清单

表6-2 本阶段成果

编号 | 成果 | 文件
SLD-01 | 电气主接线简图 | drawings/exports/ single_line_a1.pdf
LAY-220-01 | 220kV户外AIS平面布置图 | drawings/exports/ switchyard_plan_a1.pdf
SEC-220-01 | 220kV户外AIS典型间隔断面图 | drawings/exports/ switchyard_section_a1.pdf
SEC-220-L1-01 | 220kV I段L1线路间隔断面详图 | drawings/exports/ switchyard_line_bay_detail_a1.pdf
CALC-LT | 负荷、变压器与持续电流结果 | calculations/results/ load_and_transformer_summary.md
CALC-SC | 短路计算结果 | calculations/results/short_circuit/ short_circuit_summary.md
CALC-EQ | 设备额定值预筛 | calculations/results/equipment_selection/ equipment_selection_summary.md

# 参考文献

[1] 苗世洪等. 发电厂电气部分（第五版）[M]. 北京: 中国电力出版社, 2015.

[2] 西北电力设计院. 电力工程电气设计手册: 电气一次部分[M]. 北京: 中国电力出版社.

[3] GB/T 15544.1-2023 三相交流系统短路电流计算 第1部分: 电流计算.

[4] DL/T 5222-2021 导体和电器选择设计规程.

[5] DL/T 5352-2018 高压配电装置设计规范.

[6] GB 50060-2008 3~110kV高压配电装置设计规范.

[7] GB/T 3906-2020 3.6kV~40.5kV交流金属封闭开关设备和控制设备.

[8] GB/T 1984-2024 高压交流断路器.

[9] GB/T 1985-2023 高压交流隔离开关和接地开关.

[10] GB/T 20840.1-2010 互感器 第1部分: 通用技术要求.

[11] GB/T 50064-2014 交流电气装置的过电压保护和绝缘配合设计规范.

[12] GB/T 50065-2011 交流电气装置的接地设计规范.

220kV新能源汇集变电所课程设计—技术设计说明书

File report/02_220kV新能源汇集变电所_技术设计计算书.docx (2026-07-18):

《发电厂电气部分》课程设计

220kV新能源汇集变电所电气一次部分初步设计

技术设计计算书

学 院 | 电气与信息工程学院
专 业 | 电气工程及其自动化
班 级 | ____________________________
姓 名 | ____________________________
学 号 | ____________________________
同组设计者 | ____________________________
指导教师 | ____________________________
任务起止日期 | 2026年7月6日—2026年7月17日

公开版：姓名、学号、班级及签字字段留空，提交时由学生手工填写。

课程设计底稿，非施工图；工程实施前须按现行标准及厂家资料复核。

目 录

# 计算说明与统一基准

本计算书保留负荷、容量、持续电流、标幺电抗、短路电流和设备校验的公式、代入和中间结果。除特别说明外，功率单位采用MW/Mvar/MVA，电压采用kV，电流采用A或kA。短路计算为任务书X-only课程初算，最终工程值仍须按现行标准和厂家模型复核。

计算遵循“原始数据—通用公式—参数代入—中间结果—判据比较—结论”的顺序。表格用于汇总同类对象，关键选择不直接从表格读取结论，而是在正文中给出至少一个完整代入示例和控制因素分析。所有未取整数值由计算脚本保存，正文通常保留3~6位小数，设备等级按额定标准值向上选择。

标量相加、P-Q向量合成、正常分段、事故转供和禁止并列属于不同计算口径。本书在每次使用这些口径时均说明适用对象；禁止方式仅用于敏感性，不自动转化为日常设备必选职责。课程假设值在式中正常参与计算，但最终结论仍保留被教师口径、标准全文或厂家数据覆盖的接口。

表0-1 统一计算条件

项目 | 采用值 | 说明
短路基准容量SB | 100MVA | 全网统一
平均额定电压UB | 230/37/10.5kV | 220/35/10kV级
35kV同时出力系数 | 0.95 | 仅用于主变综合容量
10kV同时系数 | 0.80 | 辅助负荷综合计算
线损率 | 5% | 主结果按乘1.05
最高环境温度 | 41℃ | 导体和设备环境校核
峰值系数k | 1.8 | 课程假设
热稳定等值时间 | 1.10s | 后备保护1.00s+总开断0.08s向上取整
变流器短路贡献 | 1.1~1.2倍额定电流 | 算术相加课程上界

## 主要符号

P、Q、S分别表示有功、无功和视在功率；cosφ为功率因数；Imax为最大持续工作电流；X*为标幺电抗；Ik为三相短路初始对称电流；ip为课程峰值电流；Ith和tr分别为设备短时耐受电流及持续时间。

下标B表示基准量，N表示额定量，Σ表示故障点至电源的总等值量；normal表示正常运行，N-1表示任一关键元件退出，closed表示分段或母联条件闭合。式中电压均取线电压，除接地电阻计算明确使用相电压Uφ外，不混用相、线电压。

# 第一章 负荷及变压器容量计算

## 1.1 35kV新能源负荷

35kV负荷由风电场A/B、光伏电站A/B和储能电站组成。容量计算先把各项有功功率按自身功率因数折算为视在功率和无功功率；主变综合容量再统一施加0.95最大同时出力系数和5%线损。单回馈线电流另按该类最大出力除以实际回路数计算，不施加0.95系数。

Sᵢ = Pᵢ / cosφᵢ (1-1)

Qᵢ = Pᵢ tan(arccos(cosφᵢ)) (1-2)

式中：Pᵢ以MW计，Sᵢ以MVA计，Qᵢ以Mvar计；单回设计电流Iᵢ=Pᵢ(1+0.05)/(n√3Ucosφᵢ)，其中n为回路数。

以风电场A为例：

SWA = 80 / 0.95 = 84.210526 MVA

QWA = 80 × tan(arccos0.95) = 26.294728 Mvar

IWA = 84.210526 × 1.05 / (4 × √3 × 35) × 1000 = 364.642 A

风电场B为60MW、3回，单回有功同样为20MW，因此与风电场A得到相同的单回电流364.642A。光伏电站A功率因数较高但每回承担30MW，单回电流增至530.220A；储能只有1回线路，形成全站最大35kV单回馈线电流546.963A。

表1-1 35kV负荷逐项计算

负荷 | P/MW | cosφ | 回路 | S/MVA | Q/Mvar | 单回设计电流/A
风电场A | 80.0 | 0.95 | 4 | 84.211 | 26.295 | 364.642
风电场B | 60.0 | 0.95 | 3 | 63.158 | 19.721 | 364.642
光伏电站A | 60.0 | 0.98 | 2 | 61.224 | 12.184 | 530.220
光伏电站B | 40.0 | 0.98 | 2 | 40.816 | 8.122 | 353.480
储能电站 | 30.0 | 0.95 | 1 | 31.579 | 9.861 | 546.963

注：单回设计电流已计5%线损，不乘0.95同时出力系数。

ΣS = 280.988185 MVA (1-3)

S35 = 280.988185 × 0.95 × 1.05 = 280.285714 MVA (1-4)

逐项无功合计为76.182164Mvar。若按P、Q向量合成，计同时系数和线损后的有功、无功分别为269.325MW和75.991709Mvar，故：

S35,vector = √(269.325² + 75.991709²) = 279.840482 MVA

向量法按P、Q分别计同时系数和线损得到279.840482MVA；任务书课程主口径采用逐项视在功率和的标量处理，得到280.285714MVA。两者接近，正式容量校验取后者。

结果分析：标量口径比向量口径高0.445232MVA，保持了课程计算的偏保守性。后续主变容量和220kV送出电流均以280.285714MVA为主结果，单回馈线电流仍按各类自身最大值计算，以免同时系数被重复使用。

## 1.2 10kV辅助负荷

10kV负荷包括站用电备用电源、无功补偿及冷却系统、集控通信及监控系统。综合容量计算采用0.80同时系数和5%线损；各馈线设备电流仍按本回路额定最大负荷计5%线损，不乘0.80，以保证单回路选型不因全站同时系数而偏小。

ΣS10 = 0.8/0.85 + 0.6/0.85 + 0.4/0.90 = 2.091503 MVA

Istation-backup = 0.8×1.05/(√3×10×0.85)×1000 = 57.056 A

表1-2 10kV辅助负荷逐项计算

负荷 | P/MW | cosφ | S/MVA | 单回设计电流/A
站用电备用电源 | 0.8 | 0.85 | 0.941 | 57.056
无功补偿及冷却系统 | 0.6 | 0.85 | 0.706 | 42.792
集控通信及监控系统 | 0.4 | 0.90 | 0.444 | 26.943

S10 = 2.091503 × 0.80 × 1.05 = 1.756863 MVA (1-5)

结果分析：1.756863MVA用于10kV辅助负荷综合分析；57.056A、42.792A和26.943A分别用于三类单回馈线额定电流选择。两种结果的用途不同，不能用101.433A的综合母线电流替代任一具体馈线，也不能用单回最大值简单推回主变综合容量。

## 1.3 主变压器容量与N-1

主变容量按35kV新能源汇集主口径280.285714MVA校验。正常方式下两台主变均衡分担；N-1方式假定任一台退出，另一台不允许超过180MVA额定容量，超出部分由新能源限发消除。该策略适用于可控新能源汇集站，但必须作为运行约束写入说明书。

Snormal,each = 280.285714 / 2 = 140.142857 MVA (1-6)

βnormal = 140.142857 / 180 × 100% = 77.857% (1-7)

KN-1 = 180 / 280.285714 × 100% = 64.220% (1-8)

ΔS = 280.285714 − 180 = 100.285714 MVA (1-9)

Kcurtail = (1 − 180 / 280.285714) × 100% = 35.7798% (1-10)

主变课程型式冻结为2×180MVA、220/35kV双绕组、YNd11、uk=14%；220kV星形中性点经专用CT直接接地，35kV侧为三角形绕组。

IT,220 = 180/(√3×220) = 472.377 A

Imax,T,220 = 1.05×472.377 = 495.996 A

IT,35 = 180/(√3×35) = 2969.230 A

Imax,T,35 = 1.05×2969.230 = 3117.691 A

若保守叠加10kV辅助负荷，所需容量为282.042577MVA，正常负载率78.345%，N-1缺口102.042577MVA。该值作为敏感性，不改变主校核口径。

结果分析：正常负载率77.857%说明2×180MVA容量配置在日常方式下具有合理裕度；N-1覆盖率64.220%则表明该裕度不足以无条件承担全站最大出力。1.05系数只用于回路设备额定电流选择，不能被解释为主变本体允许长期过载5%。

## 1.4 所用变压器

所用电清单先按项目电压等级筛选，110kV配电装置电源和110kV断路器加热两项因本站无110kV系统而剔除。其余负荷按连续、经常短时和不经常短时分类；空气压缩机总装机44kW，基准场景按一台22kW同时投入，最严经常场景按44kW全部投入。

表1-3 所用电负荷统计结果

统计口径 | 功率/kW
连续适用负荷 | 96.3
短时适用负荷 | 89.0
明确经常负荷 | 81.2
明确不经常负荷 | 68.1
未标频度连续负荷 | 36.0
经常短时负荷 | 44.0
短时同时投入值 | 22.0

连续负荷96.3kW包括主变风机、充电及通风、照明和冬季加热等项目。基准场景Pbase=96.3+22.0=118.3kW；最严经常场景Pworst=96.3+44.0=140.3kW。容量计算统一取功率因数0.80并留10%裕度。

ST = Pscenario(1+Km)/cosφ

式中：Km=0.10，cosφ=0.80；标准容量从100、125、160、200、250、315kVA序列中向上选取。

Sbase = 118.3 × 1.10 / 0.80 = 162.6625 kVA (1-11)

Sworst = 140.3 × 1.10 / 0.80 = 192.9125 kVA (1-12)

选用2×200kVA、10/0.4kV、SCB14干式、Dyn11、uk=4%的所用变，暗备用；正常一台运行。

结果分析：192.9125kVA决定标准容量取200kVA。两台设备并非各承担一半负荷，而是每台都应能独立承担最严课程场景；正常一台运行、0.4kV母联闭合，备用投入时必须防止两进线并列。电动机启动压降和精确负荷功率因数仍需在最终设备资料齐全后复核。

## 1.5 SVG与T10

Qc = P [tanφ1 − tanφ2] (1-13)

T10冻结为2×31.5MVA、35/10.5kV、YNd11、uk=8%，两段各设±12Mvar SVG。补偿计算不抵扣新能源变流器自身无功裕度，先对35kV汇集负荷计算，再保守叠加10kV辅助负荷。

Qc,35 = 75.991709 − 269.325×tan(arccos0.98) = 21.302935 Mvar (1-14)

Qc,Σ = 76.883260 − 270.837×tan(arccos0.98) = 21.887462 Mvar (1-15)

Kmargin = (24/21.887462 − 1)×100% = 9.65% (1-16)

cosφ' = 270.837 / √[270.837² + (76.883260−24)²] = 0.98147 (1-17)

T10容量按两套SVG的无功交换范围和10kV辅助有功共同校验。正常均衡时每台承担一半辅助有功、辅助无功和一套12Mvar SVG；N-1最严吸收工况由单台T10承担全部辅助负荷和两套SVG吸收无功。

ST10,normal = √[(1.512/2)² + (12+0.891552/2)²] = 12.468716 MVA，β=39.583% (1-18)

ST10,N-1 = √[1.512² + (24+0.891552)²] = 24.937431 MVA，β=79.166% (1-19)

IT10,35 = 31.5 / (√3 × 35) = 519.615 A (1-20)

1.05 IT10,35 = 545.596 A (1-21)

IT10,10.5 = 31.5 / (√3 × 10.5) = 1732.051 A (1-22)

1.05 IT10,10.5 = 1818.653 A (1-23)

1.05 IT10,10kV设备口径 = 31.5/(√3×10)×1.05 = 1909.586 A (1-24)

结果分析：2×±12Mvar使补偿后功率因数达到0.98147，且单台T10在最严N-1吸收工况下负载率仍低于80%。式(1-23)按10.5kV绕组电压计算，式(1-24)按10kV开关设备校核电压计算，二者对象不同；最终仍须由无功电压、谐波和SVG厂家持续过载曲线覆盖。

# 第二章 各回路最大持续工作电流计算

## 2.1 通用公式与主变回路

持续电流必须针对具体回路和运行方式确定。主变回路按设备额定容量乘1.05选型裕度；220kV线路正常按两回均分，N-1按单回承担全部本期送出；母联按可能转供的最大设备容量确定。1.05只用于电器及导体选型，不改变变压器额定容量。

Imax = Smax / (√3 Un) (2-1)

IT,220 = 180 / (√3 × 220) × 1.05 = 495.996 A (2-2)

IT,35 = 180 / (√3 × 35) × 1.05 = 3117.691 A (2-3)

IL,normal = 280.285714 / (2√3 × 220) = 367.780 A (2-4)

IL,N-1 = 280.285714 / (√3 × 220) = 735.559 A (2-5)

结果分析：220kV线路与分段回路的持续职责取735.559A，以覆盖一回线路退出或一段事故转供。主变高、低压侧分别取495.996A和3117.691A。这些值来自不同事故路径，不能用正常双回每回367.780A替代主变或母联设备职责。
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

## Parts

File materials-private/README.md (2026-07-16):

# 本地私有材料区

此目录保存课程任务书原件、模板、课程讲义、教材/手册、他人设计书、参考图纸、扫描手稿和其他仅供本地核对的资料。

除本说明文件外，目录内容全部由 .gitignore 排除，原因包括：

- 含第三方版权材料或明确限制传播的文件；
- 含真实姓名、班级、教室、时间、GPS、设备型号或文档作者元数据；
- 含组员共同成果，公开权属尚未确认；
- 大型 PDF/DWG 会显著膨胀仓库历史；
- 云盘、Office 和 CAD 临时文件没有版本价值。

公开成果应从这里提取必要技术参数后重新编写，并在发布前完成脱敏、版权和元数据检查。不得通过强制添加将本目录原件提交到公开仓库。

## 任务书分组规则

任务书原件按组别保存，避免把不同题目的参数混用：

```text
01_taskbooks/
  all-groups/  全部组别的原始压缩包，仅用于核对
  group-05/    第5组：220kV新能源汇集变电所
  group-07/    第7组：220kV城市负荷中心变电所
```

当前公开仓库及根目录成果对应第5组。第7组采用独立工作目录、独立 Git 历史和独立公开仓库；两组仅共享通用方法、课程模板和公开标准，不共享设计输入、计算结果、图纸或报告正文。

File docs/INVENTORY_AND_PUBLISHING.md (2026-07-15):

# 资料盘点与公开发布边界

## 盘点结论

初始化时共发现 128 个文件、13 个目录，总量约 283MiB。资料覆盖任务书、模板、课程讲义、学生指导书、设备手册、参考设计书、手稿照片、17 个参考 DWG，以及本组已有的接线、断路器和母线资料截图。

关键技术来源已经读取并归纳：

- 本组任务书：8 页，确定题目、系统参数、负荷、统一计算原则、交付物和建议目录。
- 课程设计安排：两周，第一周以主接线、负荷、主变和短路计算为主，第二周完成设备选择、文档、图纸和答辩。
- 学校模板：规定封面、摘要、目录、章节、公式、表格、图题和参考文献位置。
- 课程资料：覆盖主接线、厂用电、导体与设备选择、配电装置等理论。
- 参考 DWG：可帮助理解图框、间隔和布置，但存在版权、字体缺失和二进制历史膨胀风险。

## 公开风险

| 风险 | 发现 | 处理 |
| --- | --- | --- |
| 明确限制传播 | 存在文件名直接标注不可传播的资料 | 永不进入公开历史 |
| 第三方版权 | 课程讲义、教材手册、他人设计书和工程 DWG | 仅本地参考 |
| 个人信息 | 姓名、班级、教室、课程时间、作者和修改者元数据 | 公开文档重新编写并脱敏 |
| 精确位置与设备信息 | 图片含 GPS、手机型号和拍摄信息 | 原图不公开；必要预览先清除元数据 |
| 团队成果权属 | 本组目录可能包含共同成果 | 未获组员同意前不公开原件 |
| 仓库体积与二进制元数据 | 多个 PDF/DWG，且 DWG 保存时写入机器登录信息 | 第三方文件排除；原创 DWG 本地生成，公开 DXF/PDF/PNG |

## 允许清单

公开仓库仅允许以下内容：

- 脱敏后的项目范围、设计输入、计划、决策和追踪矩阵；
- 自行完成的计算过程、结果表和校验脚本；
- 自行绘制的 CAD 源图、标准、块库和 PDF/PNG 预览；
- 自行撰写的说明书、计算书、总结和答辩材料；
- 项目健康检查、生成和转换脚本；
- 不包含个人信息的最终交付说明。

## 发布前检查

1. 检查 Git 跟踪清单，不使用无审查的 git add .。
2. 检查文档作者、最后修改者、自定义属性和修订记录。
3. 检查图片 EXIF、DWG 摘要信息、外部参照绝对路径和字体依赖。
4. 检查文件名是否包含姓名、学号、班级或限制传播提示。
5. 检查 DWG 未被公开跟踪，压缩包和媒体已被忽略。
6. 运行 scripts/project_health_check.ps1 后再提交。

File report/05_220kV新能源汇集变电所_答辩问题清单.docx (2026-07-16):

《发电厂电气部分》课程设计

220kV新能源汇集变电所电气一次部分初步设计

答辩提纲与问题清单

学 院 | 电气与信息工程学院
专 业 | 电气工程及其自动化
班 级 | ____________________________
姓 名 | ____________________________
学 号 | ____________________________
同组设计者 | ____________________________
指导教师 | ____________________________
任务起止日期 | 2026年7月6日—2026年7月17日

公开版：姓名、学号、班级及签字字段留空，提交时由学生手工填写。

课程设计底稿，非施工图；工程实施前须按现行标准及厂家资料复核。

# 答辩提纲与常见问题

## 一、90秒开场陈述

本设计为220kV新能源汇集变电所电气一次部分初步设计。本站以12回35kV集电线路汇集270MW风电、光伏和储能，经2×180MVA主变升压后由两回220kV线路送出。主接线采用220kV、35kV、10kV单母线分段；220kV分段断路器、35/10kV母联正常断开，0.4kV母联闭合并由一台200kVA所用变供电。35kV综合计算容量为280.286MVA，主变正常负载率77.857%，N-1时需限发35.780%。为满足无功和辅助系统需求，设置2×31.5MVA T10和2×±12Mvar SVG。短路初算采用100MVA标幺法，10kV条件性最大综合电流15.638kA，设备按31.5kA等级预筛。35/10kV每段配置ZN接地变+低电阻，母联转供时仅保留健康侧1套接地源。220kV配电装置采用户外AIS，并完成三张必交图和SEC-220-L1-01线路间隔增强详图，共四张课程设计底图。

## 二、汇报主线

- 题目与原始资料：220/35/10kV、270MW新能源、两回220kV送出。
- 主接线：为什么选择分段分列，以及各母联正常状态。
- 容量：2×180MVA主变、2×31.5MVA T10、2×±12Mvar SVG、2×200kVA所用变。
- 关键计算：280.286MVA、77.857%、35.780%、15.638kA、475.242A。
- 设备和配电装置：额定等级预筛、CT/PT/ZCT、MOA、母线/绝缘、接地设备包及不设限流电抗器等结论。
- 边界：哪些是任务书值、哪些是课程假设、哪些必须由厂家和现行标准覆盖。

# 三、常见答辩问题

## 1. 为什么220kV侧选单母线分段，而不是双母线？

- 本期只有两回线路、两台主变和一回预留，单母线分段能把母线故障限制在一段，接线清晰、经济。
- 双母线检修灵活性更高，但隔离开关多、占地和投资大、倒闸复杂，与本期规模不匹配。
- 若教师要求母线检修时线路和主变不停电，可升级为双母线不带旁路。

## 2. 2×180MVA主变是否合理？

- 35kV综合计算容量为280.286MVA，两台均分时每台140.143MVA，负载率77.857%，正常方式合理。
- N-1时单台只能覆盖64.220%，但任务书允许新能源汇集站限发，因此通过35.780%限发满足运行。

## 3. 主变N-1和220kV线路N-1谁控制限发？

- 单回线路在41℃课程载流量475.242A约束下需限发35.390%。
- 主变N-1需要限发35.780%，略严格；限发后线路电流472.377A，小于课程允许值，余量2.864A。
- 所以当前控制元件是主变，但线路裕度很小，厂家热额定值必须复核。

## 4. 为什么35kV和10kV母联正常断开？

- 两台主变和两台T10分别带一段，分列可以限制短路电流并缩小故障影响范围。
- 母联只在一侧电源隔离且故障清除后用于事故转供，不能把两个健康电源长期并列。

## 5. 35kV或10kV母联事故转供时，接地源怎样切换？

- 正常分列时每个独立带电母线段各投入1套接地变+低电阻。
- 母联合闸前先退出受电侧或故障侧接地源，只保留健康电源侧1套；联锁禁止母联闭合且两套同时投入。
- 母联断开、两段恢复独立供电后，再恢复每段各1套，否则两套低电阻并联会改变目标接地故障电流和保护配合。

## 6. 为什么0.4kV母联正常闭合？

- 所用变采用暗备用，正常只运行一台，闭合母联后该台可同时带两段低压母线。
- 另一台所用变及其进线保持断开；切换时先隔离故障进线，再投入备用进线，防止并列。

## 7. 为什么另设35/10.5kV T10，而不用三绕组主变？

- 任务书给出了220/35kV双绕组和35/10.5kV变压器阻抗，独立T10与给定资料一致。
- 独立T10可限制10kV短路电流，并使10kV故障不直接迫使主变退出。
- 2×31.5MVA还能在N-1下承担两套SVG最严吸收工况，负载率约79.17%。

## 8. SVG容量为什么选2×±12Mvar？

- 目标功率因数0.98，保守计入10kV辅助无功后需21.8875Mvar。
- 选24Mvar后容量裕度9.65%，补偿后功率因数约0.98147。
- 该值是课程冻结值，最终仍由无功电压和谐波专题确定。

## 9. 短路点为什么这样选择？

- 设备选择主要受各级母线故障控制，因此至少计算220kV、35kV I/II段和10kV I/II段。
- 另外计算220kV分段断路器条件闭合、健康主变低压侧并列和健康T10并列，用于最大方式和误操作敏感性。

## 10. 为什么禁止并列敏感性不作为设备必选职责？

- 这些方式在运行规程和联锁中被禁止，不属于正常或允许事故转供方式。
- 把禁止方式直接作为设备必选职责会掩盖运行边界并导致不必要抬高等级，但其结果必须用于联锁和风险提示。

## 11. 10kV最大短路电流是多少？

- 单台T10供本段、上游220kV分段条件闭合时，计SVG课程上界为15.638kA。
- 两台健康T10并列的禁止敏感性为28.472kA；正常设备按31.5kA开断等级预筛。

## 12. 设备热稳定如何校验？

- 采用Ik²t≤Ith²tr，热等值时间取1.10s。
- 220kV候选50kA/3s，35kV和10kV候选31.5kA/4s，按条件性最大Ik计算均有较大I²t裕度。

## 13. 35kV 3150A和10kV 2500A选型有什么风险？

- 35kV主变进线需3117.691A，3150A柜仅余32.309A、约1.04%；10kV进线需1909.586A，2500A柜余590.414A。
- 两级室内开关柜均按受控≤40℃。35kV余量尤其小，必须依赖厂家温升确认；10kV虽有较大余量，精确柜型和散热条件仍需闭合。

## 14. CT/PT为什么没有写成精确订货型号？

- 一次安装位置和变比量级可以由持续电流确定，但准确级、芯数、暂态性能和二次负荷依赖保护、计量和电缆清册。
- 缺少这些输入时写精确型号会造成虚假闭环，因此本阶段只冻结配置原则。

## 15. 任务书没有逐字列避雷器和零序CT，为什么仍要配置？

- 任务书要求主要电气设备和互感器完整选择，MOA属于过电压保护完整性，零序CT属于电缆单相接地保护接口。
- 7回35kV架空馈线入口配置MOA；5回35kV电缆和10kV电缆/SVG回路配置零序CT，职责与三相CT分开。
- 课程阶段只冻结位置和参数目标，MOA的TOV/能量及ZCT窗口、负担、拐点和精确型号仍待专题。

## 16. 35kV和10kV母线是否已经完成动稳定校验？

- 没有笼统宣称完成。两级矩形母线当前只完成载流和1.10s热稳定课程预筛。
- 电动力、支撑绝缘子受力、连接金具和厂家温升仍待精确布置与厂家参数；220kV管母另完成了简化弯曲和电晕预筛。

## 17. 为什么220kV配电装置选户外AIS？

- 本站回路数量有限、场地课程假设允许，AIS经济、直观且便于扩建和手绘表达。
- GIS占地小、环境适应性强，但投资高且本题无紧凑场地约束。

## 18. 图纸中的尺寸能否施工使用？

- 不能。站区145×90m、14m节距、设备轮廓和构架标高均为课程设计几何。
- 净距来自课程讲义，正式工程仍须按DL/T 5352-2018全文、真实场址和厂家外形基础图复核。

# 四、答辩时容易说错的边界

表1 表述边界

不建议说 | 建议说
设备已经最终定型 | 额定值等级预筛通过，精确厂家型号和41℃条件待核
短路电流符合现行标准最终值 | 采用任务书标幺X-only课程初算，最终按GB/T 15544.1-2023复核
图纸可以施工 | 图纸为课程设计和手绘临摹底图
35kV/10kV母联可长期闭合 | 仅在故障源隔离且故障清除后事故转供
母联合闸后两套接地源仍可同时投入 | 合母联前退出受电/故障段接地源，仅保留健康侧1套
35/10kV母线机械动稳定已全部完成 | 当前只完成载流和热稳；电动力与支撑机械待复核
CT/PT型号已选定 | 一次变比、芯级/准确级目标已冻结；二次负担、暂态性能和最终型号等待保护计量清册

220kV新能源汇集变电所课程设计—答辩提纲

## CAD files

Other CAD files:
drawings/source/single_line_a1.dxf
drawings/source/switchyard_section_a1.dxf
drawings/source/switchyard_plan_a1.dxf
drawings/source/switchyard_line_bay_detail_a1.dxf

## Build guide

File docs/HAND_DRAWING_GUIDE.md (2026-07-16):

# 四张CAD图纸手绘临摹指南（三张必交图 + 一张增强详图）

## 通用顺序

1. 先画A1图框、标题栏、图名、图号和比例。
2. 用2H铅笔轻画母线、设备中心线、道路/构架和主要尺寸定位线。
3. 按“母线/导线→设备→编号→尺寸→说明”的顺序描深；母线最粗，一次导线次之，尺寸与文字最细。
4. 预留对象使用虚线；正常断开的断路器必须画出开口状态。
5. 最后核对四图中的L1/L2/L3、T1/T2、T10-1/T10-2、SVG-1/SVG-2、MOA、ES及母联状态是否一致。

## SLD-01 电气主接线简图

- 从上到下依次画220kV、35kV、10kV、0.4kV四层母线。
- 220kV分段断路器、35/10kV母联正常断开，0.4kV母联正常闭合。
- 220kV：L1、L2在运，L3预留；两台180MVA、220/35kV、YNd11、uk=14%主变分别接两段。
- L1/L2旁同时保留“正常367.780A”和“N-1需735.559A（须限发）”，不得只抄后一个数值。
- 35kV：12回集电线路按6+6分配；WA-1～4、WB-1～3标“架空+入口MOA”，PVA-1～2、PVB-1～2、ES-1标“电缆+ZCT”，另有R1/R2和T10-1-HV/T10-2-HV。
- 10kV：T10为2×31.5MVA、35/10.5kV、YNd11、uk=8%；每段各接1套±12Mvar SVG。
- 10kV三类辅助负荷各画1回：站用电备用电源、无功补偿及冷却、集控通信及监控；不要把三类负荷在两段各重复画一遍。两回SVG和三类电缆辅助馈线标“ZCT”。
- 35kV各段按“1000kVA ZN接地变+低电阻”画出并标400A/10s、R≈50.5Ω；10kV各段按“200kVA ZN接地变+低电阻”标200A/10s、R≈28.9Ω。容量和10s短时过载均属课程假设，最终由接地故障、保护配合和厂家成套资料覆盖。
- 在运行说明中抄写：正常分列时每段1套接地源；35/10kV母联合闸前退出受电/故障段接地源，只保留健康侧1套；禁止母联闭合且两套接地源并联；重新分列后恢复每段1套。
- 220kV线路入口与主变端配置YH10W-204/532；35kV母线PT柜/主变端配置YH5WZ-51/134；10kV母线PT柜及T10/SVG端配置YH5WZ-17/45。
- 220kV线路侧隔离开关的线路一侧画常开ES，不得把ES支路接在QS母线侧；35/10kV柜内ES按常开表达并注明机械/电气联锁。
- 0.4kV：TS1运行、TS2暗备用，所用变为2×200kVA、SCB14、Dyn11、uk=4%，母联闭合；两进线不得同时闭合。

## LAY-220-01 平面布置图

- 比例1:200，北向上；先画145m×90m站区边界、围栏和4m检修道路。
- 三相母线按4.0m相间中心距画三条平行线；I、II段中间为正常断开的分段间隔。
- 典型功能中心按14m节距组织：L1、T1、PT-I、分段、PT-II、T2、L2、L3预留。
- 平断面纵向尺寸同源：母线至线路构架29m、至主变构架20m、至主变中心27m；临摹时不要分别估算。
- L1/L2/L3均向西北引出，分别标70km、85km、60km和LGJ-400/50。
- 图中道路、建筑和设备外形为课程设计占位，不要删去“精确厂家图覆盖”的说明。

## SEC-220-01 典型间隔断面图

- 比例1:100；左侧画线路间隔A-A，右侧画主变间隔B-B。
- 线路A-A设备顺序：管形母线→母线侧隔离开关→SF6断路器→CT→线路侧隔离开关→CVT→避雷器→出线构架。
- 主变B-B设备顺序：管形母线→母线侧隔离开关→SF6断路器→CT→避雷器→主变构架→180MVA主变。
- 标高：母线+9.0m、线路构架+14.5m、主变构架+11.5m；相间距4.0m。
- 净距表照抄：A1=1800、A2=2000、B1=2550、B2=1900、C=4300、D=3800mm。

## SEC-220-L1-01 L1线路间隔增强详图

- A1横向、比例1:50，按“220kV I段管形母线→母线侧QS→QF→TA→线路侧QS+常开ES→CVT→YH10W-204/532 MOA→出线构架”从左到右临摹。
- 补齐设备编号、额定等级表、基础轮廓、构架与设备接地线、地下接地网接口、水平尺寸、主要标高以及A1/A2/C净距。
- 地下接地网只画接口和示意，不填写臆测的接地电阻、接触电压或跨步电压；没有雷暴日、建筑高度和保护模型时，不声称避雷针保护范围已完成。
- 设备外形和基础仍为课程占位，临摹时保留“最终厂家图覆盖”说明。

## 临摹前终检

- 使用最新版PDF：`single_line_a1.pdf`、`switchyard_plan_a1.pdf`、`switchyard_section_a1.pdf`、`switchyard_line_bay_detail_a1.pdf`。
- 不从PNG量取真实尺寸；尺寸只读图中标注和统一YAML。
- 不把课程几何假设改写成任务书原始条件或厂家定值。
- 若教师要求改变图幅、比例或35/10kV平断面范围，先改统一数据并重新出图，再临摹。

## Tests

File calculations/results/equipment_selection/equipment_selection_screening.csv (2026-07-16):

selection_id | circuit_group | device_kind | candidate_id | required_current_a | rated_current_a | provisional_required_rms_ka | rated_breaking_current_ka | course_peak_precheck_ka | rated_peak_withstand_ka | numeric_precheck_status | final_selection_status
SEL-CB-220-LINE | 220-line-bays | circuit_breaker | TARGET-CB-220 | 735.5592390584715 | 3150 | 7.384571960617697 | 50 | 18.798051274246124 | 125 | provisional_pass | pending
SEL-DS-220-LINE | 220-line-bays | disconnector | TARGET-DS-220 | 735.5592390584715 | 3150 | 7.384571960617697 |  | 18.798051274246124 | 125 | provisional_pass | pending
SEL-CB-220-TX | 220-transformer-bays | circuit_breaker | TARGET-CB-220 | 495.99636762199674 | 3150 | 7.384571960617697 | 50 | 18.798051274246124 | 125 | provisional_pass | pending
SEL-DS-220-TX | 220-transformer-bays | disconnector | TARGET-DS-220 | 495.99636762199674 | 3150 | 7.384571960617697 |  | 18.798051274246124 | 125 | provisional_pass | pending
SEL-CB-220-BS | 220-bus-section | circuit_breaker | TARGET-CB-220 | 735.5592390584715 | 3150 | 7.384571960617697 | 50 | 18.798051274246124 | 125 | provisional_pass | pending
SEL-SWGR-35-IN | 35-transformer-incomers | switchgear | TARGET-SWGR-35-3150 | 3117.691453623979 | 3150 | 16.290983445518524 | 31.5 | 41.47007351948617 | 80 | provisional_pass | pending
SEL-SWGR-35-BT | 35-bus-tie | switchgear | TARGET-SWGR-35-3150 | 3117.691453623979 | 3150 | 16.290983445518524 | 31.5 | 41.47007351948617 | 80 | provisional_pass | pending
SEL-SWGR-35-WA | 35-feeder-wind-A | switchgear | TARGET-SWGR-35-1250 | 364.6422752776585 | 1250 | 16.290983445518524 | 31.5 | 41.47007351948617 | 80 | provisional_pass | pending
SEL-SWGR-35-WB | 35-feeder-wind-B | switchgear | TARGET-SWGR-35-1250 | 364.6422752776585 | 1250 | 16.290983445518524 | 31.5 | 41.47007351948617 | 80 | provisional_pass | pending
SEL-SWGR-35-PVA | 35-feeder-pv-A | switchgear | TARGET-SWGR-35-1250 | 530.2196349700645 | 1250 | 16.290983445518524 | 31.5 | 41.47007351948617 | 80 | provisional_pass | pending
SEL-SWGR-35-PVB | 35-feeder-pv-B | switchgear | TARGET-SWGR-35-1250 | 353.47975664670975 | 1250 | 16.290983445518524 | 31.5 | 41.47007351948617 | 80 | provisional_pass | pending
SEL-SWGR-35-ES | 35-feeder-storage | switchgear | TARGET-SWGR-35-1250 | 546.9634129164876 | 1250 | 16.290983445518524 | 31.5 | 41.47007351948617 | 80 | provisional_pass | pending
SEL-SWGR-35-T10 | 35-aux-transformer-feeders | switchgear | TARGET-SWGR-35-1250 | 545.5960043841964 | 1250 | 16.290983445518524 | 31.5 | 41.47007351948617 | 80 | provisional_pass | pending
SEL-SWGR-35-GT | 35-grounding-transformer-feeders | switchgear | TARGET-SWGR-35-1250 | 400.0 | 1250 | 16.290983445518524 | 31.5 | 41.47007351948617 | 80 | provisional_pass | pending
SEL-SWGR-10-IN | 10-transformer-incomers | switchgear | TARGET-SWGR-10-2500 | 1909.5860153446874 | 2500 | 15.638094419605405 | 31.5 | 39.808089392178566 | 80 | provisional_pass | pending
SEL-SWGR-10-BT | 10-bus-tie | switchgear | TARGET-SWGR-10-2500 | 1909.5860153446874 | 2500 | 15.638094419605405 | 31.5 | 39.808089392178566 | 80 | provisional_pass | pending
SEL-SWGR-10-GT | 10-grounding-transformer-feeders | switchgear | TARGET-SWGR-10-1250 | 200.0 | 1250 | 15.638094419605405 | 31.5 | 39.808089392178566 | 80 | provisional_pass | pending
SEL-SWGR-10-SVG | 10-svg-feeders | switchgear | TARGET-SWGR-10-1250 | 692.820323027551 | 1250 | 15.638094419605405 | 31.5 | 39.808089392178566 | 80 | provisional_pass | pending
SEL-SWGR-10-SSB | 10-load-station-service-backup | switchgear | TARGET-SWGR-10-1250 | 57.05579130815127 | 1250 | 15.638094419605405 | 31.5 | 39.808089392178566 | 80 | provisional_pass | pending
SEL-SWGR-10-RC | 10-load-reactive-and-cooling | switchgear | TARGET-SWGR-10-1250 | 42.791843481113446 | 1250 | 15.638094419605405 | 31.5 | 39.808089392178566 | 80 | provisional_pass | pending
SEL-SWGR-10-CM | 10-load-control-and-monitoring | switchgear | TARGET-SWGR-10-1250 | 26.943012562182542 | 1250 | 15.638094419605405 | 31.5 | 39.808089392178566 | 80 | provisional_pass | pending

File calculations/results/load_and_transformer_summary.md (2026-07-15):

# 负荷、持续电流与变压器容量初算

本文件由计算脚本生成。所有数值应在主接线与供电路径冻结后再转为最终设计值。

## 综合负荷

| 项目 | 结果 |
| --- | ---: |
| 35kV 负荷视在功率原始合计 | 280.988185 MVA |
| 35kV 计 0.95 同时出力后 | 266.938776 MVA |
| 35kV 再计 5% 线损 | 280.285714 MVA |
| 10kV 计 0.80 同时系数和 5% 线损 | 1.756863 MVA |
| 主变本期校核容量（35kV汇集负荷） | 280.285714 MVA |
| 保守叠加10kV负荷的敏感性容量 | 282.042577 MVA |

## 主变压器校验

| 项目 | 结果 |
| --- | ---: |
| 装机容量 | 360.000 MVA |
| 正常每台承担 | 140.142857 MVA |
| 正常负载率 | 77.857% |
| N-1 单台可覆盖比例 | 64.220% |
| N-1 需限发/缺口 | 100.285714 MVA |
| 叠加10kV敏感性场景正常负载率 | 78.345% |

## 35kV 单回线路基础电流

| 回路类别 | 回路数 | 自身最大电流/A | 计5%线损设计电流/A |
| --- | ---: | ---: | ---: |
| 风电场A | 4 | 347.278 | 364.642 |
| 风电场B | 3 | 347.278 | 364.642 |
| 光伏电站A | 2 | 504.971 | 530.220 |
| 光伏电站B | 2 | 336.647 | 353.480 |
| 储能电站 | 1 | 520.918 | 546.963 |

## 10kV 单回线路基础电流

| 回路类别 | 自身最大电流/A | 计5%线损设计电流/A |
| --- | ---: | ---: |
| 站用电备用电源 | 54.339 | 57.056 |
| 无功补偿及冷却系统 | 40.754 | 42.792 |
| 集控通信及监控系统 | 25.660 | 26.943 |

## 220kV出线LGJ-400/50温度修正与N-1

| 项目 | 结果 |
| --- | ---: |
| 25℃、导体70℃课程参考载流量 | 592.000 A |
| 41℃温度修正系数 | 0.802773 |
| 41℃课程保守允许载流量 | 475.242 A |
| 正常双回每回电流 | 367.780 A |
| 单回承担全部送出所需电流 | 735.559 A |
| 导线单独约束所需限发 | 35.390% |
| 主变N-1限发后的线路电流 | 472.377 A |
| 主变N-1后导线余量 | 2.864 A |
| N-1控制因素 | main_transformer |

592A来自旧版二手课程参数表，只作为偏保守课程参考；风速、日照、环境和现行厂家热额定值明确前，不作为工程保证值。

## 所用电变压器初选

| 项目 | 结果 |
| --- | ---: |
| 连续适用负荷 | 96.300 kW |
| 短时适用负荷 | 89.000 kW |
| 明确标为经常的负荷 | 81.200 kW |
| 明确标为不经常的负荷 | 68.100 kW |
| 未标频度的连续负荷 | 36.000 kW |
| 基准场景所需容量 | 162.662 kVA |
| 经常短时负荷全投入场景 | 192.912 kVA |
| 每台建议标准容量 | 200 kVA |

初选建议为两台所用变、单母线分段、暗备用；按课程指导书口径正常一台运行、另一台暗备用，0.4kV母联闭合。0.80功率因数属于显式假设，最终型号需结合实际设备功率因数、启动条件和教师口径复核。

## 计算口径

- 0.95 新能源同时出力系数仅用于主变综合容量计算。
- 单回馈线电流采用该类最大负荷除以回路数，不叠加系统同时系数。
- 主结果按乘 1.05 处理 5% 线损。
- 同时保留除以 (1-线损率) 的敏感性数值。
- 主变主校核按35kV汇集负荷；另保留叠加10kV负荷的保守敏感性场景。
- 所用变 kVA 建议为初选值，因其功率因数属于显式假设。

## 10kV动态无功补偿与35/10.5kV电源变

| 项目 | 结果 |
| --- | ---: |
| 目标功率因数 | 0.980 |
| 仅35kV汇集负荷所需补偿 | 21.3029 Mvar |
| 保守叠加10kV辅助负荷所需补偿 | 21.8875 Mvar |
| 选定SVG容量 | 2×±12 Mvar |
| 选定容量裕度 | 9.65% |
| 补偿后保守口径功率因数 | 0.98147 |
| T10配置 | 2×31.5 MVA，35/10.5kV，uk=8% |
| T10正常均衡负载率 | 39.58% |
| T10 N-1最严满额吸收负载率 | 79.17% |
| T10 35kV侧1.05倍电流 | 545.60 A |
| T10 10.5kV侧1.05倍电流 | 1818.65 A |
| 单套SVG 10.5kV侧1.05倍电流 | 692.82 A |

`2×±12Mvar SVG`与`2×31.5MVA T10`属于任务书缺项下的课程设计冻结值。最终接入系统无功电压专题、谐波研究和41℃设备确认可覆盖本结果。

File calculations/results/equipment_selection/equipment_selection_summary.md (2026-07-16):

# 主要电气设备与课程设计专项校核

本文件由脚本生成。开关设备完成额定值等级预筛；母线、避雷器、CT/PT、ZCT、绝缘子/套管、接地开关及35/10kV接地变压器+中性点电阻设备包完成课程级选择与校核。所有厂家订货型号和施工参数仍保持待定。

- 数值预筛选总状态：`provisional_pass`
- 最终选型总状态：`pending`
- 课程专项预校核状态：`provisional_pass`；最终工程状态：`pending`
- 主回路热稳定统一按C=87、t=1.10s进行课程预校核；接地电阻按限定单相接地电流10s职责计算。精确型号、厂家温升、保护配合、接地与绝缘配合研究仍保持待定，不按零或自动通过处理。

## 回路负荷职责

| 回路组 | 成员 | 最大持续工作电流/A | 来源/状态 |
| --- | --- | ---: | --- |
| 220-line-bays | L1, L2, L3-reserved | 735.559 | outgoing_220kv.single_circuit_contingency_current_a / known |
| 220-transformer-bays | T1-HV, T2-HV | 495.996 | main_transformer.rated_current_with_1_05_margin_a.220kv / known |
| 220-bus-section | 220-BS | 735.559 | conservative_equal_to_outgoing_220kv.single_circuit_contingency_current_a / known_conservative |
| 35-transformer-incomers | T1-LV, T2-LV | 3117.691 | main_transformer.rated_current_with_1_05_margin_a.35kv / known |
| 35-bus-I | 35kV-I | 2230.732 | baseline_feeder_allocation.35kV-I / known |
| 35-bus-II | 35kV-II | 2404.371 | baseline_feeder_allocation.35kV-II / known |
| 35-bus-tie | 35-BT | 3117.691 | main_transformer.rated_current_with_1_05_margin_a.35kv / known |
| 35-aux-transformer-feeders | T10-1-HV, T10-2-HV | 545.596 | auxiliary_transformer.rated_current_with_1_05_margin_a.35kv / known |
| 35-grounding-transformer-feeders | GT35-I, GT35-II | 400.000 | grounding_package_35kv_fault_current_course_feeder_target / known_course_target |
| 35-feeder-wind-A | WA-1, WA-2, WA-3, WA-4 | 364.642 | load_35kv.items.wind_farm_A.per_circuit_current_a / known |
| 35-feeder-wind-B | WB-1, WB-2, WB-3 | 364.642 | load_35kv.items.wind_farm_B.per_circuit_current_a / known |
| 35-feeder-pv-A | PVA-1, PVA-2 | 530.220 | load_35kv.items.pv_plant_A.per_circuit_current_a / known |
| 35-feeder-pv-B | PVB-1, PVB-2 | 353.480 | load_35kv.items.pv_plant_B.per_circuit_current_a / known |
| 35-feeder-storage | ES-1 | 546.963 | load_35kv.items.energy_storage.per_circuit_current_a / known |
| 10-load-station-service-backup | station_service_backup | 57.056 | load_10kv.items.station_service_backup.per_circuit_current_a / known |
| 10-transformer-incomers | T10-1-IN, T10-2-IN | 1909.586 | auxiliary_transformer.rated_current_with_1_05_margin_a.10kv_equipment_basis / known |
| 10-bus-tie | 10-BT | 1909.586 | auxiliary_transformer.rated_current_with_1_05_margin_a.10kv_equipment_basis / known |
| 10-grounding-transformer-feeders | GT10-I, GT10-II | 200.000 | grounding_package_10kv_fault_current_course_feeder_target / known_course_target |
| 10-svg-feeders | SVG-1, SVG-2 | 692.820 | reactive_compensation.svg_rated_current_a.10_5kv_each_with_1_05_margin / known |
| 10-load-reactive-and-cooling | reactive_compensation_and_cooling | 42.792 | load_10kv.items.reactive_compensation_and_cooling.per_circuit_current_a / known |
| 10-load-control-and-monitoring | control_communications_and_monitoring | 26.943 | load_10kv.items.control_communications_and_monitoring.per_circuit_current_a / known |

## 短路职责场景

| 电压级 | 必选运行方式RMS/kA | 条件性预校核RMS/kA | 禁止方式仅提示/kA | 峰值预校核/kA | 完整性 |
| --- | ---: | ---: | ---: | ---: | --- |
| 220_bus | 4.033 | 7.385 | 待定 | 18.798 | course_model_complete_exact_converter_model_pending |
| 35_bus | 13.265 | 16.291 | 25.694 | 41.470 | known_with_incomplete_peak_scope |
| 10_bus | 14.492 | 15.638 | 28.472 | 39.808 | course_model_complete_exact_svg_and_motor_model_pending |

## 候选额定值等级

| 选择项 | 回路组 | 候选等级 | 额定电流/A | 开断电流/kA | 峰值耐受/kA | 数值预筛 | 最终状态 |
| --- | --- | --- | ---: | ---: | ---: | --- | --- |
| SEL-CB-220-LINE | 220-line-bays | TARGET-CB-220 | 3150 | 50.000 | 125.000 | provisional_pass | pending |
| SEL-DS-220-LINE | 220-line-bays | TARGET-DS-220 | 3150 | 待定 | 125.000 | provisional_pass | pending |
| SEL-CB-220-TX | 220-transformer-bays | TARGET-CB-220 | 3150 | 50.000 | 125.000 | provisional_pass | pending |
| SEL-DS-220-TX | 220-transformer-bays | TARGET-DS-220 | 3150 | 待定 | 125.000 | provisional_pass | pending |
| SEL-CB-220-BS | 220-bus-section | TARGET-CB-220 | 3150 | 50.000 | 125.000 | provisional_pass | pending |
| SEL-SWGR-35-IN | 35-transformer-incomers | TARGET-SWGR-35-3150 | 3150 | 31.500 | 80.000 | provisional_pass | pending |
| SEL-SWGR-35-BT | 35-bus-tie | TARGET-SWGR-35-3150 | 3150 | 31.500 | 80.000 | provisional_pass | pending |
| SEL-SWGR-35-WA | 35-feeder-wind-A | TARGET-SWGR-35-1250 | 1250 | 31.500 | 80.000 | provisional_pass | pending |
| SEL-SWGR-35-WB | 35-feeder-wind-B | TARGET-SWGR-35-1250 | 1250 | 31.500 | 80.000 | provisional_pass | pending |
| SEL-SWGR-35-PVA | 35-feeder-pv-A | TARGET-SWGR-35-1250 | 1250 | 31.500 | 80.000 | provisional_pass | pending |
| SEL-SWGR-35-PVB | 35-feeder-pv-B | TARGET-SWGR-35-1250 | 1250 | 31.500 | 80.000 | provisional_pass | pending |
| SEL-SWGR-35-ES | 35-feeder-storage | TARGET-SWGR-35-1250 | 1250 | 31.500 | 80.000 | provisional_pass | pending |
| SEL-SWGR-35-T10 | 35-aux-transformer-feeders | TARGET-SWGR-35-1250 | 1250 | 31.500 | 80.000 | provisional_pass | pending |
| SEL-SWGR-35-GT | 35-grounding-transformer-feeders | TARGET-SWGR-35-1250 | 1250 | 31.500 | 80.000 | provisional_pass | pending |
| SEL-SWGR-10-IN | 10-transformer-incomers | TARGET-SWGR-10-2500 | 2500 | 31.500 | 80.000 | provisional_pass | pending |
| SEL-SWGR-10-BT | 10-bus-tie | TARGET-SWGR-10-2500 | 2500 | 31.500 | 80.000 | provisional_pass | pending |
| SEL-SWGR-10-GT | 10-grounding-transformer-feeders | TARGET-SWGR-10-1250 | 1250 | 31.500 | 80.000 | provisional_pass | pending |
| SEL-SWGR-10-SVG | 10-svg-feeders | TARGET-SWGR-10-1250 | 1250 | 31.500 | 80.000 | provisional_pass | pending |
| SEL-SWGR-10-SSB | 10-load-station-service-backup | TARGET-SWGR-10-1250 | 1250 | 31.500 | 80.000 | provisional_pass | pending |
| SEL-SWGR-10-RC | 10-load-reactive-and-cooling | TARGET-SWGR-10-1250 | 1250 | 31.500 | 80.000 | provisional_pass | pending |
| SEL-SWGR-10-CM | 10-load-control-and-monitoring | TARGET-SWGR-10-1250 | 1250 | 31.500 | 80.000 | provisional_pass | pending |

## 课程设计专项闭环

> all supplementary rows are course target classes, not purchase specifications or construction release data

### 方案取舍

| 电压级 | 条件性短路职责/kA | 开关设备开断能力/kA | 限流电抗器结论 |
| --- | ---: | ---: | --- |
| v35 | 16.291 | 31.500 | 不设置（provisional_pass） |
| v10 | 15.638 | 31.500 | 不设置（provisional_pass） |

- 限流电抗器：35/10kV条件性短路水平低于31.5kA开关设备能力，课程方案不设置；reassess if the final grid, converter or parallel-operation study exceeds the selected 31.5kA switchgear rating。
- 高压熔断器：不作为主回路设备选型；only a manufacturer-coordinated primary protection component inside 35kV/10kV VT panels where required。

### 35/10kV接地源运行联锁

| 电压级 | 正常运行 | 母联合闸转供前 | 禁止状态 | 分段恢复 | 课程预校核 |
| --- | --- | --- | --- | --- | --- |
| v35 | 每段一套，共2套投入 | 先断开受电/故障段接地源，仅健康电源侧1套保持投入 | 母联合闸且两套接地源并联 | 母联断开后恢复每段一套，共2套 | provisional_pass |
| v10 | 每段一套，共2套投入 | 先断开受电/故障段接地源，仅健康电源侧1套保持投入 | 母联合闸且两套接地源并联 | 母联断开后恢复每段一套，共2套 | provisional_pass |

> 联锁原则：母联闭合许可必须同时确认受电/故障段接地源已断开，禁止两套低电阻接地源经母联并联。硬接点、软件逻辑、控制电源失效模式及保护跳闸矩阵仍由最终厂家设计。

### 接地变压器+中性点电阻课程设备包

| 设备包 | 每段配置 | Ig/A×s | R计算/选取Ω | 10s等效功率/MVA | 10倍短时过载最小容量/kVA | 选用/kVA | 馈线柜 | 相/中性CT目标 | 课程预校核 |
| --- | --- | ---: | ---: | ---: | ---: | ---: | --- | --- | --- |
| GRD-PKG-35 | 2套ZN中性点形成、每段一套 | 400×10 | 50.518/50.5 | 8.083 | 808.290 | 1000 | SEL-SWGR-35-GT | 600/1A / 400/1A | provisional_pass |
| GRD-PKG-10 | 2套ZN中性点形成、每段一套 | 200×10 | 28.868/28.9 | 1.155 | 115.470 | 200 | SEL-SWGR-10-GT | 300/1A / 200/1A | provisional_pass |

设备包包含接地变馈线开关柜、相CT与中性点CT课程目标、相/零序过流、母线零序过压、接地变与电阻温度/连续性监视及断路器失灵接口；零序阻抗、损耗温升、NGR结构、CT饱和和完整保护定值由同一最终厂家协调。

### 导体与母线

| 项目 | 方案 | 持续职责/A | 修正后载流量/A | K | 1.10s热稳定允许/kA | 课程预校核 | 最终工程状态 |
| --- | --- | ---: | ---: | ---: | ---: | --- | --- |
| BUS-220-TUBE-100-90 | 220kV aluminum-alloy tubular busbar, phi100/90mm | 735.559 | 1605.546 | 0.8028 | 123.785 | provisional_pass | pending_exact_conductor_and_support_manufacturer_data |
| BUS-35-3X125X10 | 35kV rectangular aluminum busbar, 3x125x10mm per phase | 3117.691 | 4194.000 | 1.0000 | 311.067 | provisional_pass | pending_exact_busbar_arrangement_and_manufacturer_temperature_rise_data |
| BUS-10-2X125X10 | 10kV rectangular aluminum busbar, 2x125x10mm per phase | 1909.586 | 3282.000 | 1.0000 | 207.378 | provisional_pass | pending_exact_busbar_arrangement_and_manufacturer_temperature_rise_data |

> BUS-35-3X125X10, BUS-10-2X125X10仅完成载流与热稳定课程预校核；支撑间距、共振、连接受力和机械动稳定明确保持pending，不作自动通过。

220kV管形母线附加课程校核：

| 项目 | 计算值 | 允许/要求值 | 结论 |
| --- | ---: | ---: | --- |
| 简化动稳定弯曲应力/MPa（校核相距3.0m≤布置4.0m） | 10.048 | 70.000 | provisional_pass |
| 简化电晕起始相电压/kV | 330.444 | 运行相电压 145.492 | provisional_pass |

### 金属氧化物避雷器

| 电压级 | 课程目标型号 | Uc/kV | 持续电压要求/kV | 持续裕度/kV | In/kA | 残压/kV | 设备LIWV/kV | LIWV/残压 | 课程预校核 |
| --- | --- | ---: | ---: | ---: | ---: | ---: | ---: | ---: | --- |
| v220 | YH10W-204/532 | 159.000 | 145.492 | 13.508 | 10.000 | 532.000 | 950.000 | 1.786 | provisional_pass |
| v35 | YH5WZ-51/134 | 40.800 | 40.500 | 0.300 | 5.000 | 134.000 | 185.000 | 1.381 | provisional_pass |
| v10 | YH5WZ-17/45 | 13.600 | 12.000 | 1.600 | 5.000 | 45.000 | 75.000 | 1.667 | provisional_pass |

> MOA-35-OHL-ENTRY：overhead_line_entry覆盖35-feeder-wind-A, 35-feeder-wind-B，回路WA-1, WA-2, WA-3, WA-4, WB-1, WB-2, WB-3；映射校核provisional_pass。

### CT课程选择与动热稳定预校核

| CT目标 | 覆盖回路 | 变比 | 持续职责/额定A | 短路职责/额定kA | 峰值职责/额定kA | 课程预校核 | 最终工程状态 |
| --- | --- | --- | ---: | ---: | ---: | --- | --- |
| CT-220-LINE | 220-line-bays | 1000/1A | 735.559/1000 | 7.385/50.000×3s | 18.798/125.000 | provisional_pass | pending_burden_knee_point_and_exact_model |
| CT-220-TRANSFORMER | 220-transformer-bays | 600/1A | 495.996/600 | 7.385/50.000×3s | 18.798/125.000 | provisional_pass | pending_burden_knee_point_and_exact_model |
| CT-220-TRANSFORMER-NEUTRAL | 220-transformer-bays | 600/1A | 待定/600 | 待定/50.000×3s | 待定/125.000 | pending | pending_grounding_fault_study_burden_knee_point_and_exact_model |
| CT-220-BUS-SECTION | 220-bus-section | 1000/1A | 735.559/1000 | 7.385/50.000×3s | 18.798/125.000 | provisional_pass | pending_burden_knee_point_and_exact_model |
| CT-35-INCOMER-TIE | 35-transformer-incomers, 35-bus-tie | 4000/1A | 3117.691/4000 | 16.291/31.500×4s | 41.470/80.000 | provisional_pass | pending_burden_knee_point_and_exact_model |
| CT-35-FEEDER | 35-aux-transformer-feeders, 35-feeder-wind-A, 35-feeder-wind-B, 35-feeder-pv-A, 35-feeder-pv-B, 35-feeder-storage | 800/1A | 546.963/800 | 16.291/31.500×4s | 41.470/80.000 | provisional_pass | pending_burden_knee_point_and_exact_model |
| CT-10-INCOMER-TIE | 10-transformer-incomers, 10-bus-tie | 2500/1A | 1909.586/2500 | 15.638/31.500×4s | 39.808/80.000 | provisional_pass | pending_burden_knee_point_and_exact_model |
| CT-10-FEEDER-SVG | 10-svg-feeders, 10-load-station-service-backup, 10-load-reactive-and-cooling, 10-load-control-and-monitoring | 1000/1A | 692.820/1000 | 15.638/31.500×4s | 39.808/80.000 | provisional_pass | pending_burden_knee_point_and_exact_model |

> 主变220kV中性点CT的600/1A、PX+5P30仅为课程配置目标。其持续、短时和峰值职责必须按单相接地及零序电流专题确定，不能沿用主变相回路的三相短路电流，因此本表保持待定。

### 电缆馈线ZCT课程目标与接口校核

| ZCT目标 | 电压级 | 覆盖回路组 | 覆盖电缆回路 | 变比 | 接地电流目标/最小线性范围A | 课程预校核 | 最终工程状态 |
| --- | --- | --- | --- | --- | ---: | --- | --- |
| ZCT-35-CABLE-FEEDERS | v35 | 35-feeder-pv-A, 35-feeder-pv-B, 35-feeder-storage | PVA-1, PVA-2, PVB-1, PVB-2, ES-1 | 100/1A | 400/400 | provisional_pass | pending_window_size_cable_shield_routing_burden_knee_point_and_exact_model |
| ZCT-10-CABLE-FEEDERS | v10 | 10-svg-feeders, 10-load-station-service-backup, 10-load-reactive-and-cooling, 10-load-control-and-monitoring | SVG-1, SVG-2, station_service_backup, reactive_compensation_and_cooling, control_communications_and_monitoring | 50/1A | 200/200 | provisional_pass | pending_window_size_cable_shield_routing_burden_knee_point_and_exact_model |

> 35kV电缆回路PVA-1/2、PVB-1/2、ES-1和10kV电缆馈线均已映射至ZCT；窗口尺寸、电缆屏蔽层接地回流路径、负担、拐点和厂家准确级保持pending。

### PT课程选择表

| PT目标 | 电压级 | 型式 | 一次额定 | 二次绕组 | 准确级目标 | 最终工程状态 |
| --- | --- | --- | --- | --- | --- | --- |
| PT-220-BUS | v220 | single-phase CVT set | 220/sqrt(3)kV | 100/sqrt(3)V measurement; 100/sqrt(3)V protection; 100/3V open-delta | 0.2, 3P | pending_burden_resonance_and_exact_model |
| PT-35-BUS | v35 | three single-phase inductive VT set | 35/sqrt(3)kV | 100/sqrt(3)V measurement; 100/sqrt(3)V protection; 100/3V open-delta | 0.5, 3P | pending_burden_ferroresonance_and_exact_model |
| PT-10-BUS | v10 | three single-phase inductive VT set | 10/sqrt(3)kV | 100/sqrt(3)V measurement; 100/sqrt(3)V protection; 100/3V open-delta | 0.5, 3P | pending_burden_ferroresonance_and_exact_model |

### 绝缘子与套管课程选择表

| 目标 | 应用 | Um/kV | LIWV/kV | 套管持续职责/额定A | 短时职责/额定kA×s | 峰值职责/额定kA | 课程预校核 | 最终工程状态 |
| --- | --- | ---: | ---: | ---: | ---: | ---: | --- | --- |
| INS-BUSH-220 | outdoor post insulators and main-transformer 220kV bushings | 252.000 | 950.000 | 495.996/630 | 7.385/50.000×3 | 18.798/125.000 | provisional_pass | pending_creepage_mechanical_load_and_exact_model |
| INS-BUSH-35 | indoor supports and main-transformer or switchgear 35kV bushings | 40.500 | 185.000 | 3117.691/4000 | 16.291/31.500×4 | 41.470/80.000 | provisional_pass | pending_creepage_mechanical_load_and_exact_model |
| INS-BUSH-10 | indoor supports and T10 or switchgear 10kV bushings | 12.000 | 75.000 | 1909.586/2500 | 15.638/31.500×4 | 39.808/80.000 | provisional_pass | pending_creepage_mechanical_load_and_exact_model |

> 套管已完成Um、LIWV、持续电流及动热稳定课程预校核；绝缘子/套管爬电距离、端子与悬臂机械负荷、抗震和精确型号仍明确保持pending。

### 接地开关课程选择与动热稳定预校核

| 目标 | 覆盖回路 | Um/kV | 短时耐受 | 峰值耐受/kA | 课程预校核 | 特殊边界 |
| --- | --- | ---: | --- | ---: | --- | --- |
| ES-220-LINE | 220-line-bays | 252.000 | 50.000kA×3s | 125.000 | provisional_pass | line-side induced-current switching duty pending study |
| ES-35-SWITCHGEAR | 35-transformer-incomers, 35-bus-tie, 35-aux-transformer-feeders, 35-grounding-transformer-feeders, 35-feeder-wind-A, 35-feeder-wind-B, 35-feeder-pv-A, 35-feeder-pv-B, 35-feeder-storage | 40.500 | 31.500kA×4s | 80.000 | provisional_pass | integrated switchgear earthing switch course target |
| ES-10-SWITCHGEAR | 10-transformer-incomers, 10-bus-tie, 10-grounding-transformer-feeders, 10-svg-feeders, 10-load-station-service-backup, 10-load-reactive-and-cooling, 10-load-control-and-monitoring | 12.000 | 31.500kA×4s | 80.000 | provisional_pass | integrated switchgear earthing switch course target |

## 关键边界

- 220kV线路一回退出及分段回路均按735.559A保守持续职责闭环；最终潮流研究只能提高精度，不能将该课程预筛值重新置空。
- 35kV I、II段按实际馈线分配计算，不把4623.515A全站总电流或2311.758A简单均分值当成物理母线段职责。
- 35kV条件性预校核采用计入新能源RMS上界的16.291kA；两台健康主变低压侧并列25.694kA仅作禁止方式提示。
- 220kV新能源与10kV SVG贡献已按额定电流1.1～1.2倍的课程上界计入；固定k得到的综合峰值仍只作设备等级预筛。
- 热稳定采用后备保护1.00s与全开断0.08s向上取1.10s，通过I²t与候选设备额定短时耐受能力比较。
- 35kV 3150A进线/母联按室内最高40℃受控环境、K=1.0进行课程预校核；空调可靠性和厂家温升资料未冻结，因此最终型号仍为pending。
- 10kV进线及母联升级为2500A目标；采用2×±12Mvar SVG和2×31.5MVA T10，单电源条件性综合上限15.638kA，禁止的两台健康T10并列综合上限28.472kA。
- Φ100/90管形母线的温度修正、热稳定、简化动稳定和电晕校核，以及35/10kV矩形母线热稳定均为可再生课程计算；35/10kV母线机械动稳定、支撑共振、端部效应和厂家温升明确保持pending。
- 35kV每段采用ZN接地变+约50.5Ω电阻，400A/10s、等效功率约8.083MVA，按10倍短时过载最小约808kVA并选1000kVA；10kV相应为约28.9Ω、200A/10s、约1.155MVA、最小约115.5kVA并选200kVA。
- 正常运行35/10kV每段各一套接地源；母联转供前先断开受电/故障段接地源，仅健康电源侧一套投入，联锁禁止母联闭合且两套并联；分段恢复后各段一套。
- 35kV架空入口MOA及35/10kV电缆馈线ZCT已建立回路映射；避雷器能量、ZCT窗口/屏蔽层回流、CT负担饱和和精确型号仍待厂家复核。
- 避雷器型号、CT/PT/ZCT变比与准确级、绝缘子/套管绝缘水平和接地开关耐受等级是课程目标表，不是订货规范；接地、能量、负担、饱和、爬距、机械负荷和感应电流开合研究仍待完成。

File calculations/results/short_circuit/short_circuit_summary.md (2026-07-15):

# 220kV、35kV与10kV三相短路电流初算

基准：100MVA；平均额定电压230/37/10.5kV；初算电阻处理：忽略；课程假设峰值系数k=1.8。

本结果采用任务书标幺制X-only初算方法，并非GB/T 15544.1-2023的完整实现；最终设备校验须按标准原文复核电压系数、变压器修正系数和κ。

| 计算点 | 运行方式 | 正常运行许可 | XΣ/pu | 电网对称电流/kA | 变流器RMS范围/kA | 保守综合上限/kA | 课程综合峰值/kA |
| --- | --- | --- | ---: | ---: | ---: | ---: | ---: |
| SC-220-BUS-CLOSED | 分段闭合最大基准 | 待系统并列许可 | 0.038621 | 6.500 | 0.811～0.885 | 7.385 | 18.798 |
| SC-220-I-SEPARATE | 220kV分列 | 允许分列运行 | 0.069597 | 3.607 | 0.390～0.426 | 4.033 | 10.266 |
| SC-220-II-SEPARATE | 220kV分列 | 允许分列运行 | 0.086772 | 2.893 | 0.421～0.459 | 3.352 | 8.533 |
| SC-35-I-220-CLOSED | 35kV分段、220kV分段闭合 | 待系统并列许可 | 0.116398 | 13.406 | 2.454～2.677 | 16.083 | 40.940 |
| SC-35-II-220-CLOSED | 35kV分段、220kV分段闭合 | 待系统并列许可 | 0.116398 | 13.406 | 2.645～2.885 | 16.291 | 41.470 |
| SC-35-I-220-SEPARATE | 220kV分列 | 允许分列运行 | 0.147375 | 10.588 | 2.454～2.677 | 13.265 | 33.767 |
| SC-35-II-220-SEPARATE | 220kV分列 | 允许分列运行 | 0.164550 | 9.483 | 2.645～2.885 | 12.368 | 31.484 |
| SC-35-BOTH-TRANSFORMERS-SENSITIVITY | 主变低压侧非正常并列 | 不允许，仅敏感性 | 0.077509 | 20.132 | 5.099～5.562 | 25.694 | 65.406 |
| SC-10-I-220-SEPARATE | 10kV分段、单台T10供本段 | 允许分列运行 | 0.401343 | 13.700 | 0.726～0.792 | 14.492 | 36.891 |
| SC-10-I-220-CLOSED | 10kV分段、220kV分段条件闭合 | 仅调度许可后条件允许 | 0.370367 | 14.846 | 0.726～0.792 | 15.638 | 39.808 |
| SC-10-II-220-SEPARATE | 10kV分段、单台T10供本段 | 允许分列运行 | 0.418518 | 13.138 | 0.726～0.792 | 13.930 | 35.460 |
| SC-10-II-220-CLOSED | 10kV分段、220kV分段条件闭合 | 仅调度许可后条件允许 | 0.370367 | 14.846 | 0.726～0.792 | 15.638 | 39.808 |
| SC-10-BOTH-T10-SENSITIVITY | 两台T10非正常并列 | 不允许，仅敏感性 | 0.204494 | 26.889 | 1.452～1.584 | 28.472 | 72.479 |

## 关键结论

- 220kV分段闭合的条件性最大基准电网贡献：6.500kA；该方式等待系统并列许可确认。
- 35kV-I段在220kV分段闭合时的电网贡献：13.406kA；计入新能源RMS保守上界后为16.083kA。
- 35kV-II段在220kV分段闭合时计入新能源RMS保守上界后为16.291kA。
- 两台健康主变低压侧并列的非正常电网敏感性值：20.132kA；计入新能源RMS保守上界后为25.694kA。
- 10kV单台T10供电、220kV分段闭合的条件性最大电网贡献：14.846kA；计入单套SVG课程上界后为15.638kA。
- 两台健康T10经10kV母联并列属于禁止方式，仅保留敏感性：28.472kA。
- 峰值列把固定课程系数k应用于电网与变流器RMS算术上界，只用于设备等级预筛，不替代标准短路峰值与厂家变流器模型。

## 注意

- 220kV分段断路器闭合场景须以系统1、系统2允许并列为前提，目前仅作最大基准敏感性。
- 35kV正常保持分段运行，不允许两台健康主变低压侧长期并列。
- 两台主变低压侧并列值仅保留为非正常敏感性场景。
- 新能源贡献采用算术相加的课程设计保守上界，不等同于变流器电磁暂态模型。
- grid_peak_current_ka字段仅表示电网贡献；报告中的课程综合峰值另把固定k用于变流器RMS算术上界，二者均待按R/X和厂家模型复核。
- 220kV与35kV新能源、10kV SVG贡献采用额定电流1.1～1.2倍算术上界；精确变流器和电动机反馈仍需专题复核。
- 第三回220kV线路L3不参加本期基准计算，远期投入场景另行计算。

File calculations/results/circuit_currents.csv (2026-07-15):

voltage_level | name | label_zh | active_power_mw | power_factor | circuits | base_apparent_mva | base_per_circuit_mva | base_per_circuit_current_a | per_circuit_design_mva | per_circuit_current_a | simultaneity_applied_to_circuit
35kV | wind_farm_A | 风电场A | 80.0 | 0.95 | 4 | 84.21052631578948 | 21.05263157894737 | 347.27835740729375 | 22.10526315789474 | 364.6422752776585 | False
35kV | wind_farm_B | 风电场B | 60.0 | 0.95 | 3 | 63.15789473684211 | 21.05263157894737 | 347.27835740729375 | 22.10526315789474 | 364.6422752776585 | False
35kV | pv_plant_A | 光伏电站A | 60.0 | 0.98 | 2 | 61.224489795918366 | 30.612244897959183 | 504.971080923871 | 32.142857142857146 | 530.2196349700645 | False
35kV | pv_plant_B | 光伏电站B | 40.0 | 0.98 | 2 | 40.816326530612244 | 20.408163265306122 | 336.64738728258067 | 21.42857142857143 | 353.47975664670975 | False
35kV | energy_storage | 储能电站 | 30.0 | 0.95 | 1 | 31.578947368421055 | 31.578947368421055 | 520.9175361109407 | 33.15789473684211 | 546.9634129164876 | False
10kV | station_service_backup | 站用电备用电源 | 0.8 | 0.85 | 1 | 0.9411764705882354 | 0.9411764705882354 | 54.33884886490597 | 0.9882352941176472 | 57.05579130815127 | False
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

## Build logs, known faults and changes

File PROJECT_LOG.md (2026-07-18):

# 项目日志

本文件记录每次形成可交付价值的修改批次。每次提交前更新，提交后同步 GitHub。

## 2026-07-15 - 项目初始化与资料治理

### 完成

- 阅读并提取本组任务书、课程要求、模板目录和三类图纸要求。
- 盘点 128 个文件、约 283MiB 本地资料，识别第三方版权、个人信息、GPS/设备元数据和明确禁止传播材料。
- 将原始任务书、模板、课程资料、示例和旧参考资料整理到 materials-private/，并建立公开仓库允许清单。
- 确认 AutoCAD Core Console、GB 图框模板和 PDF 打印配置可用。
- 建立项目目录、设计输入、需求追踪、总体计划、CAD 工作流和健康检查脚本。
- 决定公开仓库不包含原始教学材料、他人设计书、参考 DWG、扫描手稿和个人字段。

### 下一步

- 冻结 220kV、35kV、10kV 和 0.4kV 主接线方案。
- 完成负荷计算与主变/所用变压器配置校验。
- 建立短路等值网络和计算点清单。

## 2026-07-15 - GitHub Actions 跨平台修正

- 修正项目健康检查在 Linux Runner 上读取点文件大小时的兼容性问题。
- 对 Git 跟踪清单进行 Trim 和空行过滤，文件大小检查改用 .NET FileInfo。
- 本地复核通过后同步公开仓库，并重新验证工作流。

## 2026-07-15 - 负荷与变压器初算

- 建立从 data/design_inputs.yaml 读取参数的 Python 计算模块。
- 生成负荷、主变、所用变和单回线路电流的 JSON、CSV、Markdown 结果。
- 新增 6 项单元测试，覆盖同时系数、线损、单回电流、N-1、110kV项排除和非法功率因数。
- 35kV 汇集负荷计算值为 280.285714MVA；2×180MVA 正常负载率 77.857%，N-1 单台覆盖 64.220%。
- 所用变保守初选为 2×200kVA、10/0.4kV、单母线分段、暗备用；正常一台运行、0.4kV母联闭合。
- GitHub Actions 增加 Python 测试、结果再生成和漂移检查。

## 2026-07-15 - 主接线与变压器配置基线

- 比较220kV内桥、单母线分段和双母线方案，基线采用单母线分段、不设旁路。
- 35kV采用单母线两分段，12回本期馈线按6+6、130MW/140MW分配，预留按1+1布置。
- 10kV采用两段母线和两台35/10.5kV独立电源变；0.4kV采用2×200kVA所用变轮换暗备用，正常一台运行、母联闭合。
- 主变基线采用2×180MVA、220/35kV双绕组；若后续10kV无功补偿容量很大，再复核三绕组方案。
- 新增结构化接线基线和3项拓扑一致性测试，为短路计算和CAD共用。

## 2026-07-15 - 220kV、35kV短路电流初算

- 建立100MVA基准下的系统、线路和主变标幺电抗计算模块，生成JSON、CSV和Markdown结果。
- 计算220kV母线闭合分段的条件性最大基准方式，以及220kV分列、35kV分段和两台主变低压侧并列的敏感性方式。
- 得到220kV母线条件性最大电网对称贡献6.500kA、电网峰值16.546kA；35kV单段电网贡献13.406kA、34.125kA。
- 对35kV新能源场站按额定电流1.1～1.2倍另列RMS保守贡献范围；两段综合上限分别为16.083kA和16.291kA。该范围不替代并网变换器、线路阻抗及峰值模型。
- 10kV短路点因35/10.5kV电源变容量及无功补偿Mvar未确认，保留为显式待定项。
- 单元测试增至14项；GitHub Actions同步重算负荷与短路结果并检查结果漂移。

## 2026-07-15 - 设计标准台账

- 按2026-07-15官方状态核验主接线、短路计算、设备选择、配电装置、接地和CAD制图所需标准。
- 明确采用GB/T 15544.1-2023、DL/T 5222-2021、DL/T 5352-2018、DL/T 5452-2025等现行版本，并列出必须排除的废止版本。
- 建立数值性条文复核门槛：安全净距、系数、温度、接地限值和设备尺寸必须回到合法取得的标准全文或厂家正式样本，并记录条文、表号和适用条件。
- 海拔、污秽等级、10kV无功容量和系统并列许可未确认前，不冻结相关设备参数和CAD尺寸。

## 2026-07-15 - 主要电气设备额定值预筛

- 建立回路职责注册表，分别管理持续电流、必选短路方式、条件性方式和禁止方式，缺失数据显式传播为pending。
- 220kV线路N-1职责为735.559A，主变高压侧为495.996A；220kV分段潮流等待间隔与潮流确认。
- 按35kV实际馈线分配得到I、II段基础电流2230.732A和2404.371A，避免误用全站4623.515A或简单均分值。
- 35kV条件性预校核采用16.291kA新能源RMS上界；两台健康主变低压侧并列25.694kA只作禁止方式提示。
- 目标等级暂按220kV断路器252kV/3150A/50kA、35kV进线与母联3150A/31.5kA、馈线1250A/31.5kA预筛；所有精确型号、环境与完整动热稳定仍保持待定。
- 官方厂家页面只作为家族可得性证据；若页面、目录或精确配置不一致，不把家族上限写成已选设备参数。
- 新增12项设备职责、场景与配置安全测试，全项目测试增至29项；CI将依次重算负荷、短路和设备预筛结果。

## 2026-07-15 - 正式制图前拓扑复核

- 在35kV-I、II段分别补入`T10-1-HV`、`T10-2-HV`电源变馈线间隔，打通35kV至10kV的完整供电链；该回路电流在无功补偿容量和35/10.5kV电源变容量确认前保持pending。
- 依据学生指导书第9页修正所用电暗备用解释：正常仅一台所用变运行，另一台停运暗备用，0.4kV母联闭合；切换时禁止两台所用变低压侧并列。
- 同步设计基线、计算输入、设备职责、计划、追踪矩阵和单元测试，为A1电气主接线CAD生成建立一致数据源。
- 重新生成负荷、短路和设备预筛结果；全项目31项单元测试与CI模式健康检查通过。

## 2026-07-15 - A1电气主接线工程底图

- 建立A1横向主接线布局、图层/线型/线宽/字体标准和可复用一次设备图块库，以统一基线驱动220/35/10/0.4kV全图。
- 生成R2018/AC1032、毫米单位的`single_line_a1.dxf`，包含8段母线、4个母联、L1/L2/L3、T1/T2、12回35kV集电馈线、2回预留、T10-1/T10-2、10kV待定负荷组和0.4kV暗备用拓扑。
- 使用 AutoCAD Core Console 执行原生 AUDIT，结果为 0 错误；保存 2018 DWG，并通过 `DWG To PDF.pc3` 与 `monochrome.ctb` 输出 A1 横向 PDF。
- 将AutoCAD PDF规范化后渲染为PNG逐图目检；首轮发现TTC中文字体被替换为问号，改用本机验证可用的`txt.shx + gbcbig.shx`后重出图，中文恢复正常。
- 新增6项图纸拓扑、状态、图层、块属性、R2018单位与中文往返测试，全项目测试增至37项；CI新增主接线DXF再生成与漂移检查。
- 本批次采用 Core Console、PDF 渲染和逐页目检完成制图闭环。图中未确认的 T10 容量、10kV 无功 Mvar、并列许可和精确设备参数均继续以 P/条件项表达。

## 2026-07-15 - 缺失参数冻结与10kV计算闭环

- 根据用户授权建立完整执行提示词与设计假设台账，明确“任务书/教师—现行标准与官方资料—课程设计假设”的取值优先级，以及CAD工程底图后续手绘临摹策略。
- 冻结海拔≤1000m、污秽d级、220kV分段正常断开、主保护0.05s、后备保护1.00s、断路器固有分闸0.04s、全开断0.08s和热稳定等值时间1.10s；全部标记为可由教师或真实工程资料覆盖的课程设计假设。
- 按35kV与10kV负荷P/Q重算，目标功率因数0.98时保守所需补偿21.8875Mvar；采用2×±12Mvar SVG后容量裕度9.65%，补偿后保守功率因数0.98147。
- T10冻结为2×31.5MVA、35/10.5kV、uk=8%；N-1满额吸收无功时最严负载率79.17%，35kV侧1.05倍职责545.596A，10kV设备口径职责1909.586A。
- 完成10kV短路模型：单台T10、220kV分段条件闭合时电网贡献14.846kA，计入单套SVG课程上界后15.638kA；两台健康T10并列为禁止方式，综合上限28.472kA。
- 220kV新能源贡献和10kV SVG贡献统一按额定电流1.1～1.2倍的课程算术上界计入；设备预筛扩展到10kV 2000A/1250A、31.5kA/80kA等级，并完成1.10s I²t校核。
- 单元测试由37项增至41项并全部通过；精确设备型号、41℃厂家适配、爬电距离、谐波与变流器专题模型继续保持最终复核边界。

## 2026-07-15 - LGJ温度校核与三张CAD工程底图闭环

- 对任务书指定LGJ-400/50建立显式证据等级：采用旧版二手课程参数表592A与本地课程温度修正公式，在41℃下得到课程保守允许载流量475.242A；正常双回367.780A通过，单回独立承担全送出需限发35.390%。
- 主变N-1限发35.780%略严，对应线路电流472.377A，导线仍有约2.864A余量；当前N-1控制因素仍是180MVA主变，但厂家在明确风速、日照和环境下的热额定值仍需最终覆盖。
- 更新A1主接线图：220kV分段正常断开，线路同时标明正常367.780A与单回N-1需735.559A且须限发；T10标注2×31.5MVA，两段分别配置±12Mvar SVG，三类10kV辅助负荷各画1回，35/10kV接地变加小电阻按课程假设同步。
- 新建220kV户外AIS平断面统一数据与制图标准；平面图按A1/1:200表达两段三相母线、14m典型功能节距、L1/L2/L3、T1/T2、分段、PT/CVT、道路和建筑；断面图按A1/1:100同页表达线路A-A与主变B-B，母线至线路构架29m、至主变构架20m、至主变中心27m在平断面中保持同源。
- 课程第七章表7-2的A1/A2/B1/B2/C/D净距与14m间隔、4m相距、9m母线标高、设备/道路/建筑课程几何假设分开记录，避免把课程底稿误当施工放样。
- 三张 DXF 均由脚本再生；AutoCAD Core Console 完成原生 AUDIT、2018 DWG 保存和 A1 PDF 打印，随后规范化 PDF 并按 150dpi 渲染 PNG 逐图目检。
- 新增5项平断面数据、结构、中文和可再生性测试，全项目测试增至47项；CI采用语义指纹检查两张平断面DXF，忽略时间戳、GUID和类表顺序伪差异。

## 2026-07-15 - 正式报告生成与终审

- 形成技术设计说明书、技术设计计算书、课程设计总结和答辩问题清单四组 DOCX/PDF，页数分别为20、17、4和7页，全部为 A4。
- 修复表格中单位、数值、设备名称和长路径的异常拆行，处理参考文献孤行，并为文档图片补充替代文本。
- 四份正式 PDF 逐页只读终审 PASS；未发现裁切、重叠、表格破损、异常空白页或数值歧义。
- 四份 DOCX 已清除作者、最后修改者、自定义属性和 rsid；批注、修订、隐藏文字和外部关系检查无阻断项。
- 公开版的姓名、学号、班级和签字字段继续保持留空。

## 2026-07-15 - 11页答辩汇报

- 生成`04_220kV新能源汇集变电所_答辩汇报.pptx`及对应 PDF，共11页、16:9，覆盖项目范围、主接线、主变 N-1、T10/SVG、持续电流、短路与设备等级、AIS 平断面和运行方式。
- 完成 PPTX 逐页渲染、PDF 11 页逐页检查和画布溢出检测；修复第6页纵轴刻度和第9页尺寸文字拆行后复核通过。
- 将 PPTX/PDF 标题统一为正式答辩标题，作者和最后修改者统一为“课程设计项目组（公开版）”；元数据清理前后 11 页渲染哈希完全一致。

## 2026-07-15 - 交付文档状态同步

- 更新根 README、总体计划、需求追踪、报告说明和交付说明，将四份正式报告、11页答辩 PPTX/PDF 及三张 A1 CAD 图纳入已完成成果。
- 保留工程精确设备型号、41℃适配、CT/PT 二次参数和外绝缘复核等明确边界，不将课程等级预筛误写为工程定型。
- 本次文档同步时尚未宣称最终全仓隐私扫描、47项测试复跑、项目健康检查、GitHub Actions 和远端一致性已完成；这些在后续发布收尾日志中完成闭环。

## 2026-07-15 - 公开发布门与隐私收尾

- 固化 `report/scripts/sanitize_public_metadata.py`，统一清理 DOCX/PPTX/PDF 公开元数据；DOCX 页数更新为 20/17/4/7，正文、图片、样式与关系部件哈希保持不变，Word 只读打开验证通过。
- 修复 PPTX 元数据重写的 OOXML 命名空间兼容性，清理主题来源标记；PowerPoint 实际打开、11 页画布溢出检测和 PPTX/PDF 逐页像素一致性检查通过，PDF 保持 Tagged 结构。
- 新增 4 项报告交付测试，全项目测试由 CAD 闭环阶段的 47 项增至 51 项；64 项健康检查、计算结果再生成、三张 DXF 语义漂移检查和 `git diff --check` 均通过。
- 将 AutoCAD Core Console 路径改为参数、环境变量、PATH 与注册表自动发现，移除公开文档中的机器诊断细节。
- AutoCAD 每次保存 DWG 会写入只读的 Windows `LastAuthor`。公开树改为版本化 DXF/PDF/PNG，DWG 继续保留本地且由 `.gitignore` 排除；本地三份 DWG 文件未删除。
- 截至本阶段，公开候选树的文本、Office/PDF 包、DXF 与 PDF 内容隐私扫描无命中，仓库级 Git 身份已改为 GitHub noreply；当时既有两个提交和旧 LFS DWG 仍在公开历史中，待用户授权后处理。该事项随后在“公开历史重写与远端收尾”阶段完成。

## 2026-07-15 - 公开历史重写与远端收尾

- 用户明确授权后，先在本地 `tmp/history-backup/` 生成不入库的回滚 bundle，再使用 `git-filter-repo` 从全部可达历史移除三份 `drawings/source/*.dwg`，并将作者与提交者身份统一为 `wzgig <176552148+wzgig@users.noreply.github.com>`。
- 重写前后当前树哈希保持不变；三份 DWG 未删除，继续仅在本地保留并由 `.gitignore` 排除。重写后的可达历史中未发现旧身份、DWG 路径或 LFS 对象。
- 使用精确租约将远端 `main` 从重写前 HEAD 更新为重写后 HEAD；51 项测试、64 项健康检查、`git fsck` 和当前树隐私扫描均通过。
- GitHub Issues #1-#6 已全部关闭；历史重写后的 GitHub Actions Run `29425905651` 成功，并删除了仍引用旧提交/DWG 历史的可控旧 Actions 记录。
- 远端分支引用和仓库内可控引用已完成清理。GitHub 仍可能暂存不可达提交或 LFS 对象；若旧 SHA 在后台回收前仍可直接访问，立即物理清除需等待 GitHub GC 或联系 GitHub Support。

## 2026-07-16 - 设备完整性、第四图与报告源同步

- 将主变、T10和所用变联结组/阻抗统一为2×180MVA YNd11 uk=14%、2×31.5MVA YNd11 uk=8%和2×200kVA SCB14 Dyn11 uk=4%。
- 冻结35kV架空/电缆接口分配、35/10kV接地变+低电阻参数、220kV分段735.559A课程持续职责及三类MOA参数/绝缘裕度。
- 补齐课程级CT/PT、母线、绝缘子/套管、接地开关，并记录“不设限流电抗器、主回路不选高压熔断器、阻波器仅随电力载波需求”的负面选择结论。
- 将10kV进线/母联开关柜课程等级由早期较低额定电流口径统一提升为2500A，相对1909.586A职责保留590.414A裕度；35/10kV室内柜统一按受控≤40℃复核。
- 统一文档口径为“三张必交图+一张增强详图/四张CAD图”；SEC-220-L1-01 A1/1:50的DXF/PDF/PNG已按冻结路径生成。
- 同步`report/scripts/build_reports.py`，加入第四图存在性引用及防雷/接地工程边界。本批次按主线程要求不生成或覆盖正式DOCX/PDF，生成、目录更新、隐私清理和逐页QA由后续统一执行。

## 2026-07-16 - 完整性复盘、四图与本地发布闭环

- 对照任务书、指导资料和参考方案完成设计完整性复盘；确认避雷器属于主要电气设备完整性范围，补齐220/35/10kV三类MOA课程选型与绝缘裕度，以及CT/PT、母线/导体、绝缘子/套管和接地开关；同时固化“不设限流电抗器、主回路不采用高压熔断器、阻波器仅随电力载波需求设置”的适用性结论。
- 新增图号`SEC-220-L1-01`的220kV I段L1线路间隔A1/1:50断面详图，形成“三张必交图+一张增强详图”；四张DXF均为AC1032、范围`[10,10,831,584]`，最新AutoCAD原生AUDIT均为0错误、stderr为0且打印视口2；逐图复核修复标题栏横线穿图名及平面图L1/L2/L3围栏线穿字。
- 以最新四张CAD图重新生成说明书、计算书、课程总结和答辩问题清单DOCX/PDF；修复`export_reports.ps1`在Windows PowerShell 5.1参数默认值中读取`$PSScriptRoot`为空的问题，Word COM目录/域更新、PDF导出和公开元数据清理闭环。正式PDF页数为23/17/4/7页，四份DOCX与PDF逐页视觉QA未见裁切、重叠、断表、缺字或异常分页。
- 将答辩PPTX/PDF第8页平面图和第9页L1线路间隔详图同步为最终CAD版本；第3页主接线图原已与最终PNG一致。最终11页逐页检查、画布溢出、模板一致性、媒体哈希、PDF页数及公开元数据复核均通过。
- 本地最终发布门复跑60项单元测试、67项健康检查、10份计算结果再生成/漂移检查、四图DXF语义校验、`git diff --check`及最新四份AutoCAD日志。101个公开候选文件的Office/PDF审阅残留与元数据、当前树隐私、PNG元数据和禁止跟踪文件检查均无阻断项；公开候选树中DWG、`*_raw.pdf`、AutoCAD日志、`tmp/`、LFS对象及私有资料正文均为0（仅保留`materials-private/README.md`边界说明）。

## 2026-07-16 - 接地设备补强、图纸精修与最终发布收尾

- 将完整性复盘固化为`docs/DESIGN_COMPLETENESS_AUDIT.md`并纳入仓库健康门；明确避雷器、接地开关、零序CT、接地变+低电阻、绝缘子/套管和母线属于课程设备闭环，同时继续把直击雷保护范围、接地网、TOV/能量、完整二次负荷、35/10kV母线机械与厂家定型保留为工程待复核边界。
- 冻结35kV每段1000kVA、400A/10s、R≈50.5Ω和10kV每段200kVA、200A/10s、R≈28.9Ω的ZN接地变+低电阻课程设备包；正常每段1套，母联合闸前退出受电/故障段接地源，仅保留健康侧1套，禁止母联闭合且两套低电阻接地源并联。
- 统一220kV控制短路职责为分列4.033kA/10.266kA、分段条件闭合7.385kA/18.798kA，3.607/6.500kA只保留为电网分量；220kV设备术语统一为“分段断路器”，35/10kV才使用“母联”。
- 重新生成并精修四张A1图，修复线路侧ES位置、接地设备容量标签压叠、平面图净距说明与线路标签交叠等问题。四份DXF/DWG均为AC1032，AutoCAD AUDIT均为0错误；PDF均为单页A1，规范化脚本清除AutoCAD SHX文字批注层后`/Annots=0`，四张PNG像素哈希保持不变。
- 使用最终CAD哈希重新生成并终验四份报告和答辩稿：正式Word PDF为25/18/4/7页A4，答辩PPTX/PDF为11页16:9；说明书和答辩稿内嵌主接线、平面图、断面/详图媒体哈希与最终CAD逐字一致。报告与PPT逐页检查、模板/溢出、批注/修订、外链、字体和公开元数据检查通过。
- 最终本地发布门通过62项单元测试、68项仓库健康检查、10份计算结果独立SHA256复算、四图DXF语义再生成、CAD PDF零批注、Office/PDF隐私与审阅残留、禁止跟踪/LFS/大文件以及`git diff --check`检查。DWG、`*_raw.pdf`、AutoCAD日志、`tmp/`和私有资料正文继续仅保留本地，不进入公开Git历史。

## 2026-07-16 - 第5组身份澄清与第7组任务书隔离

- 确认本仓库、全部计算结果、四张CAD图和正式报告均对应第5组“220kV新能源汇集变电所”任务书；第7组“220kV城市负荷中心变电所”将使用独立目录、独立Git历史和独立公开仓库。
- 将原名“本组任务书”的第5组原件与新上传第7组原件按`group-05`、`group-07`重新归档到本地私有材料区，并保留全部组别压缩包作为只读核对源；原件含个人信息和Office/WPS元数据，不进入公开历史。
- 在根`.gitignore`增加中英文任务书原件拦截规则，并扩展项目健康检查：任何文件名含“任务书”或`taskbook`的DOC/DOCX/PDF/ZIP一旦被跟踪即失败，降低误执行`git add -A`导致公开泄漏的风险。
- 本批次通过项目健康检查、62项单元测试和`git diff --check`；第5组计算、图纸和报告内容未改动。
- 第7组独立公开仓库建立后，在第5组README增加交叉链接，明确两个仓库的题目边界和数据隔离规则。

## 2026-07-18 - 说明书与计算书正式化补充重构

- 先在 `docs/EXECUTION_PROMPT.md` 增补本轮专用提示词，明确按“设计目的与依据—方法—符号与单位—公式—参数取值—逐步代入—结果—校验—工程含义与边界”重构报告，并保留原始可靠数据和修改前备份。
- 对技术设计说明书和计算书进行实质性扩写：说明书强化主接线方案比较、运行方式、事故转供、设备选择理由和工程边界；计算书补齐负荷、容量、持续电流、短路、设备、母线、接地与MOA等计算链和结果分析。
- 最终 Word PDF 页数由原25/18页扩展为35/29页；目录采用罗马数字前置页和正文阿拉伯数字，章节、公式编号、表格和图纸引用保持一致。
- 修复窄列孤立字符、表格续排、孤立单行、章节分页和列表编号问题；§6.1保持真正项目符号，事故转供步骤保持十进制1—5且显式从1重启，正式章节另起页造成的结构性留白予以保留。
- 重新生成DOCX，使用Word更新目录、域和页码并导出PDF，完成公开元数据清理；DOCX内部页数统计同步更新为35/29。课程总结与答辩问题清单经文本、媒体哈希和逐页像素对比确认无实质变化后恢复到HEAD，避免无关Word往返保存噪声进入提交。
- 三组计算结果重新生成无漂移；35kV母线段四组分析口径及主变进线/事故母联3117.691A设备职责保持不变。正式报告深度、前置页/正文页码、表格版式、列表语义、公开元数据和页数均已固化为回归测试。
- 最终35+29页渲染复核未见裁切、重叠、断表或缺字；70项单元测试及40项子测试全部通过，68项必需路径项目健康检查通过，`git diff --check` 通过。

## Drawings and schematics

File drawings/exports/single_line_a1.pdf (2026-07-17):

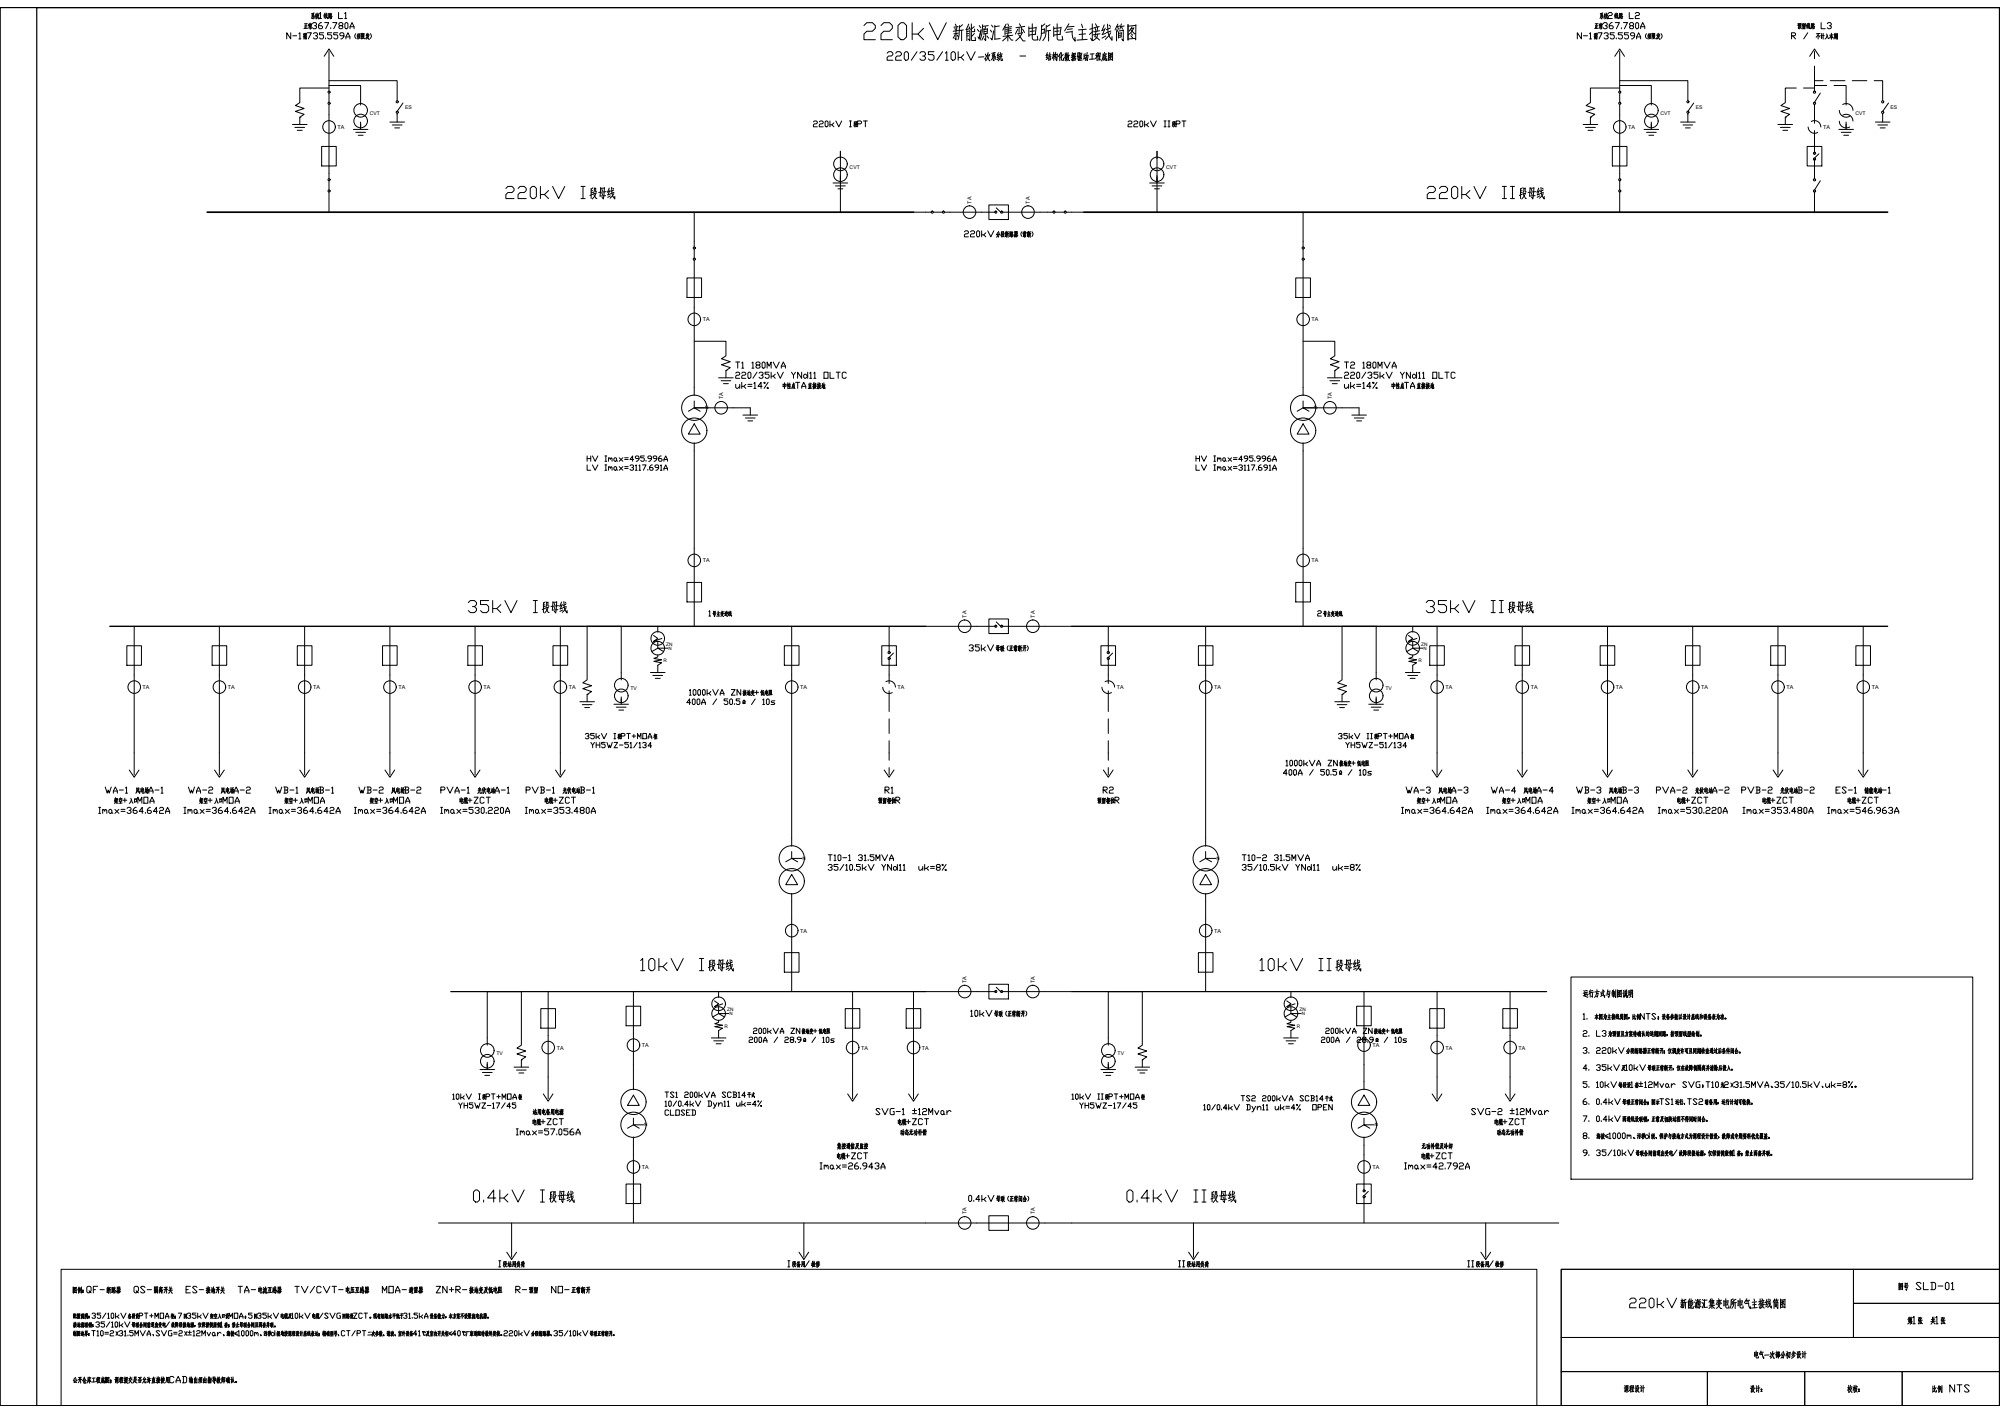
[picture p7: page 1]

TATA TATA

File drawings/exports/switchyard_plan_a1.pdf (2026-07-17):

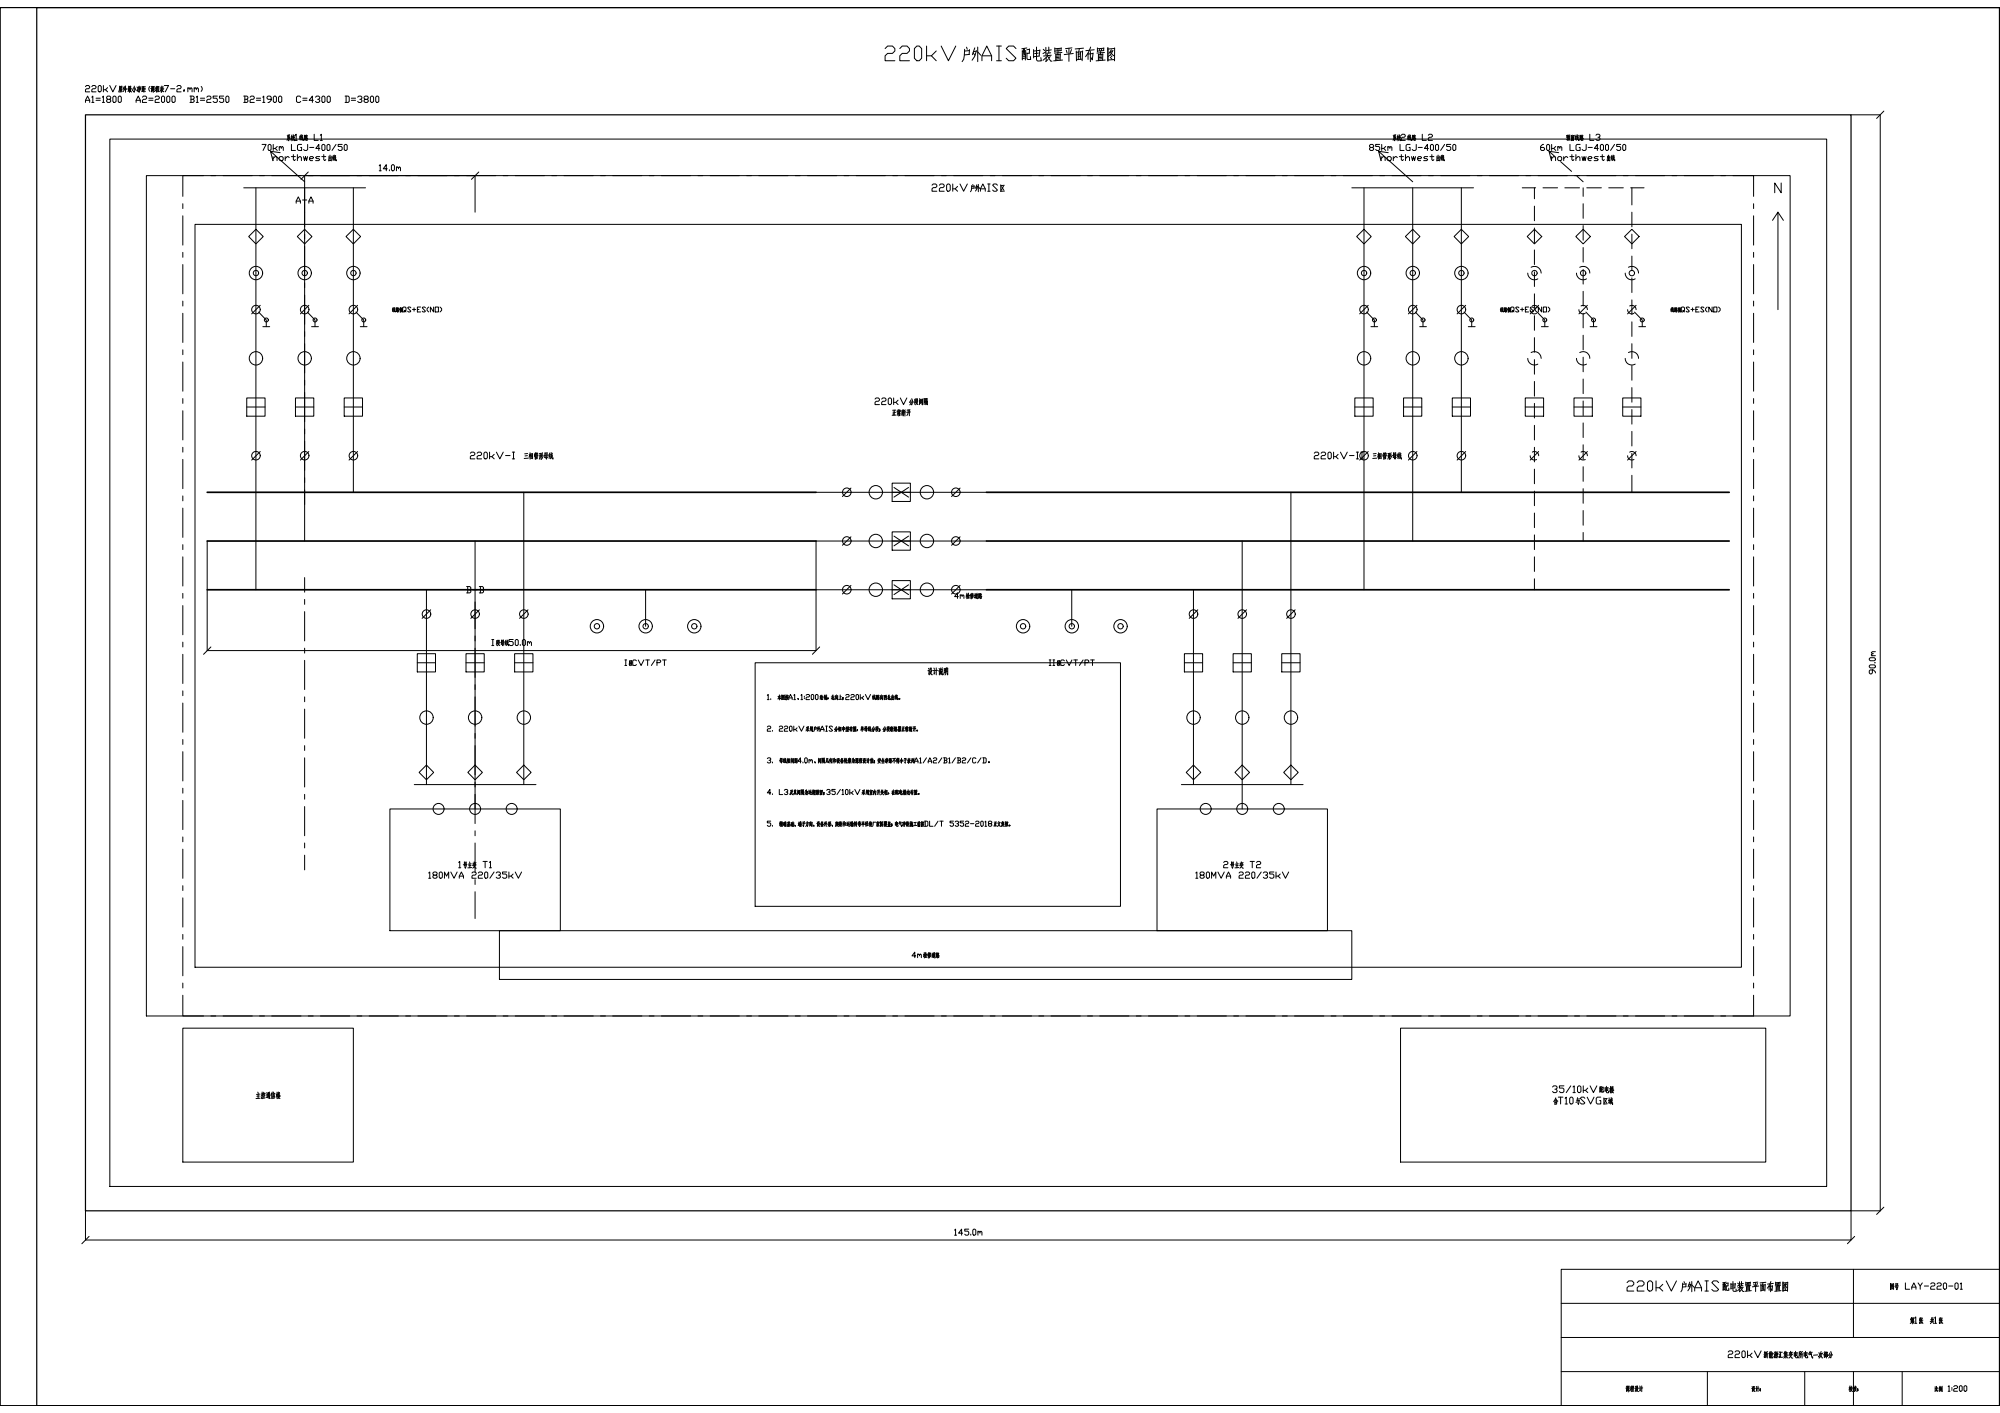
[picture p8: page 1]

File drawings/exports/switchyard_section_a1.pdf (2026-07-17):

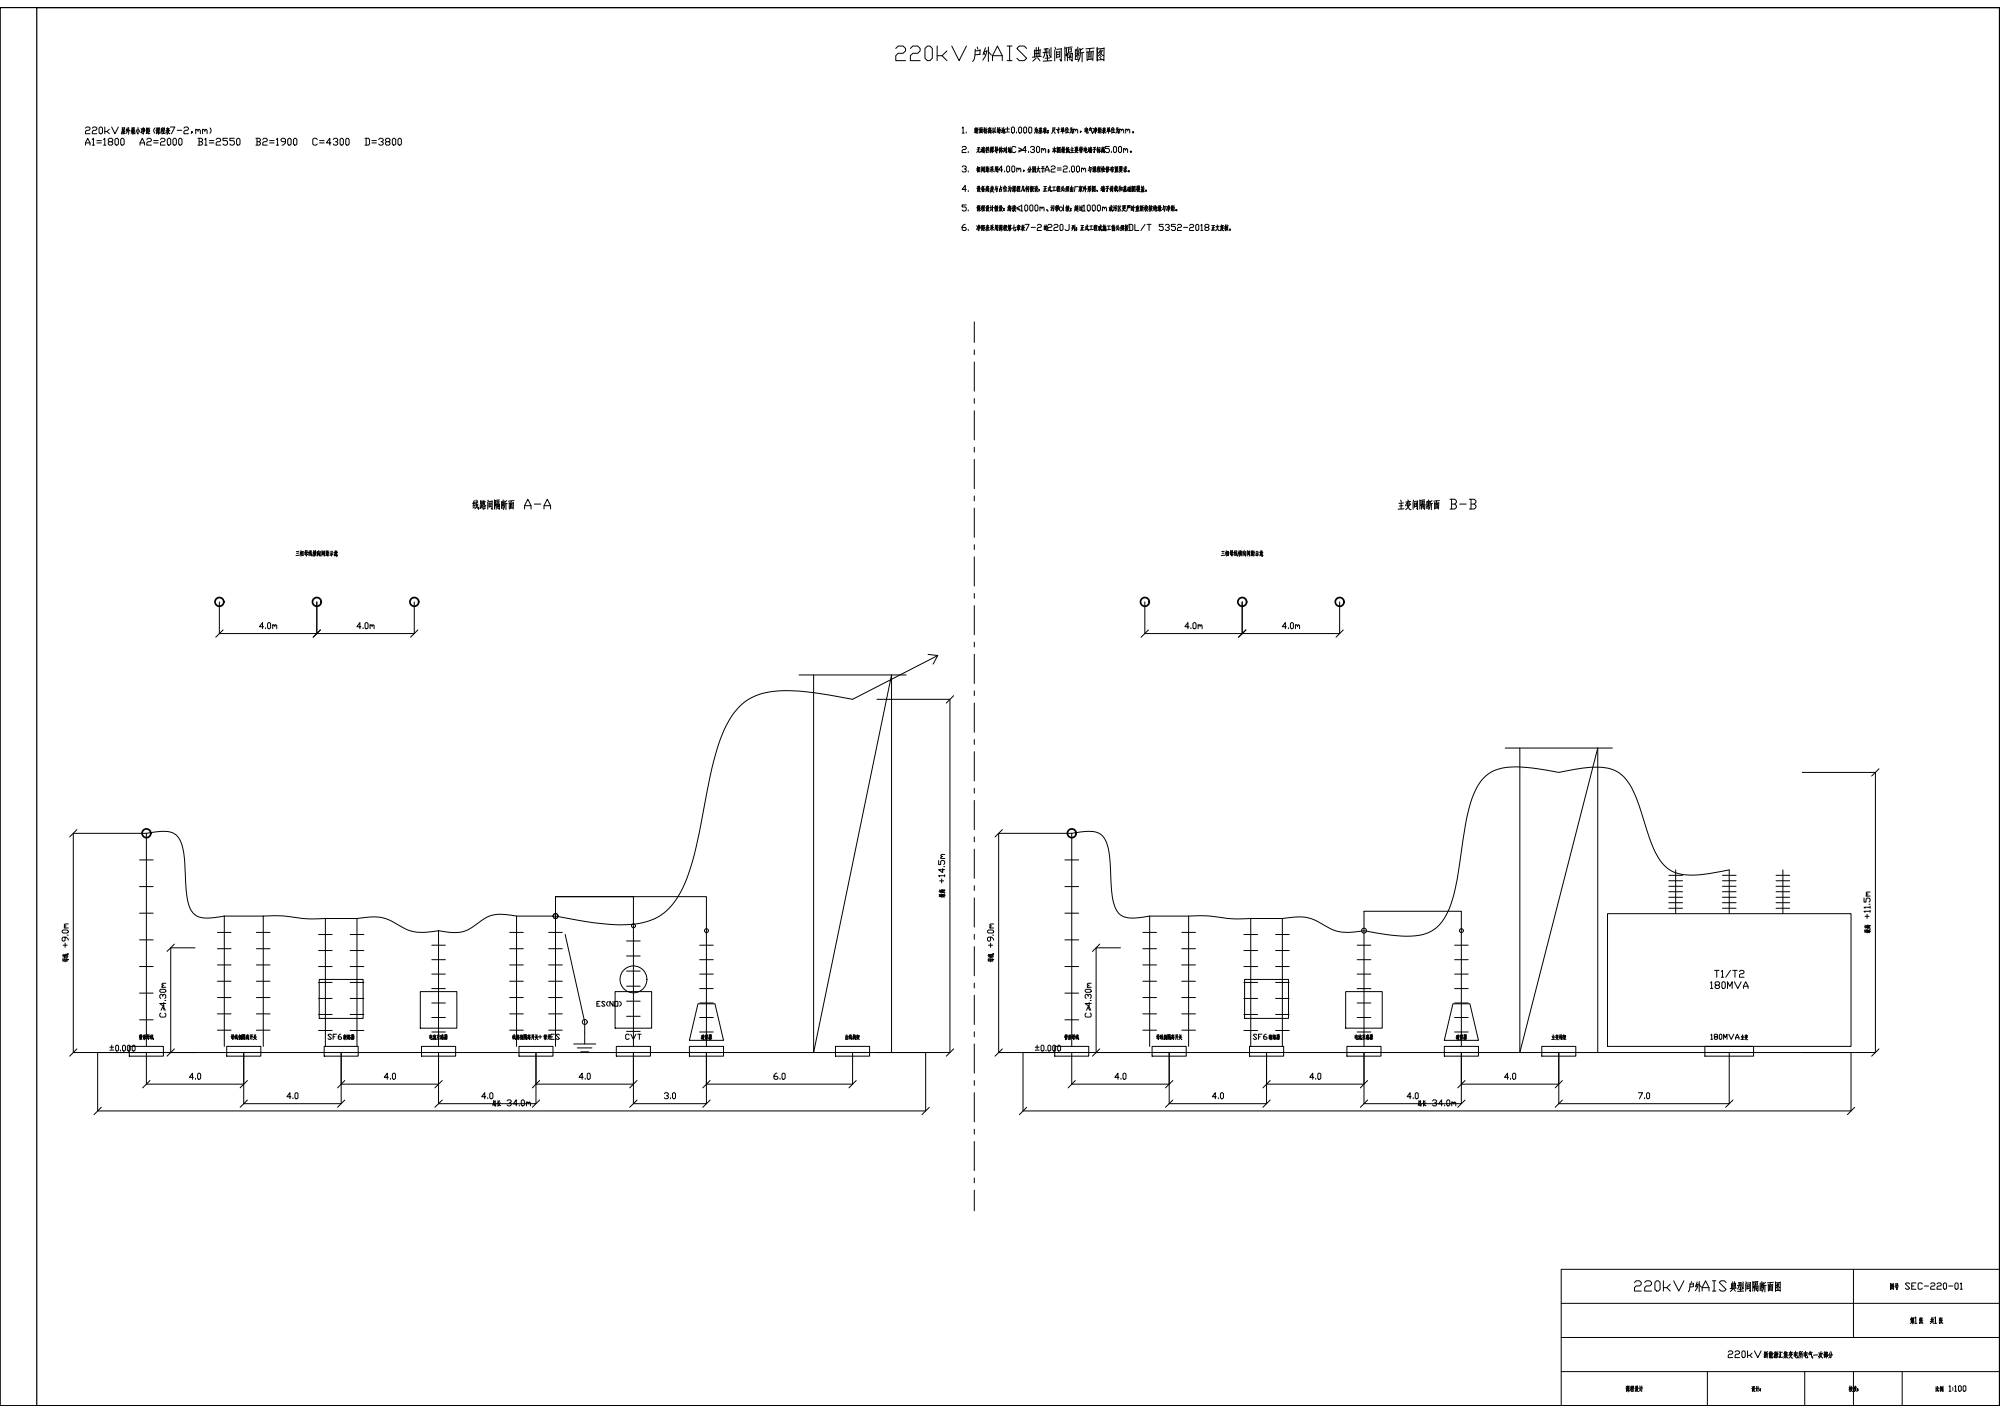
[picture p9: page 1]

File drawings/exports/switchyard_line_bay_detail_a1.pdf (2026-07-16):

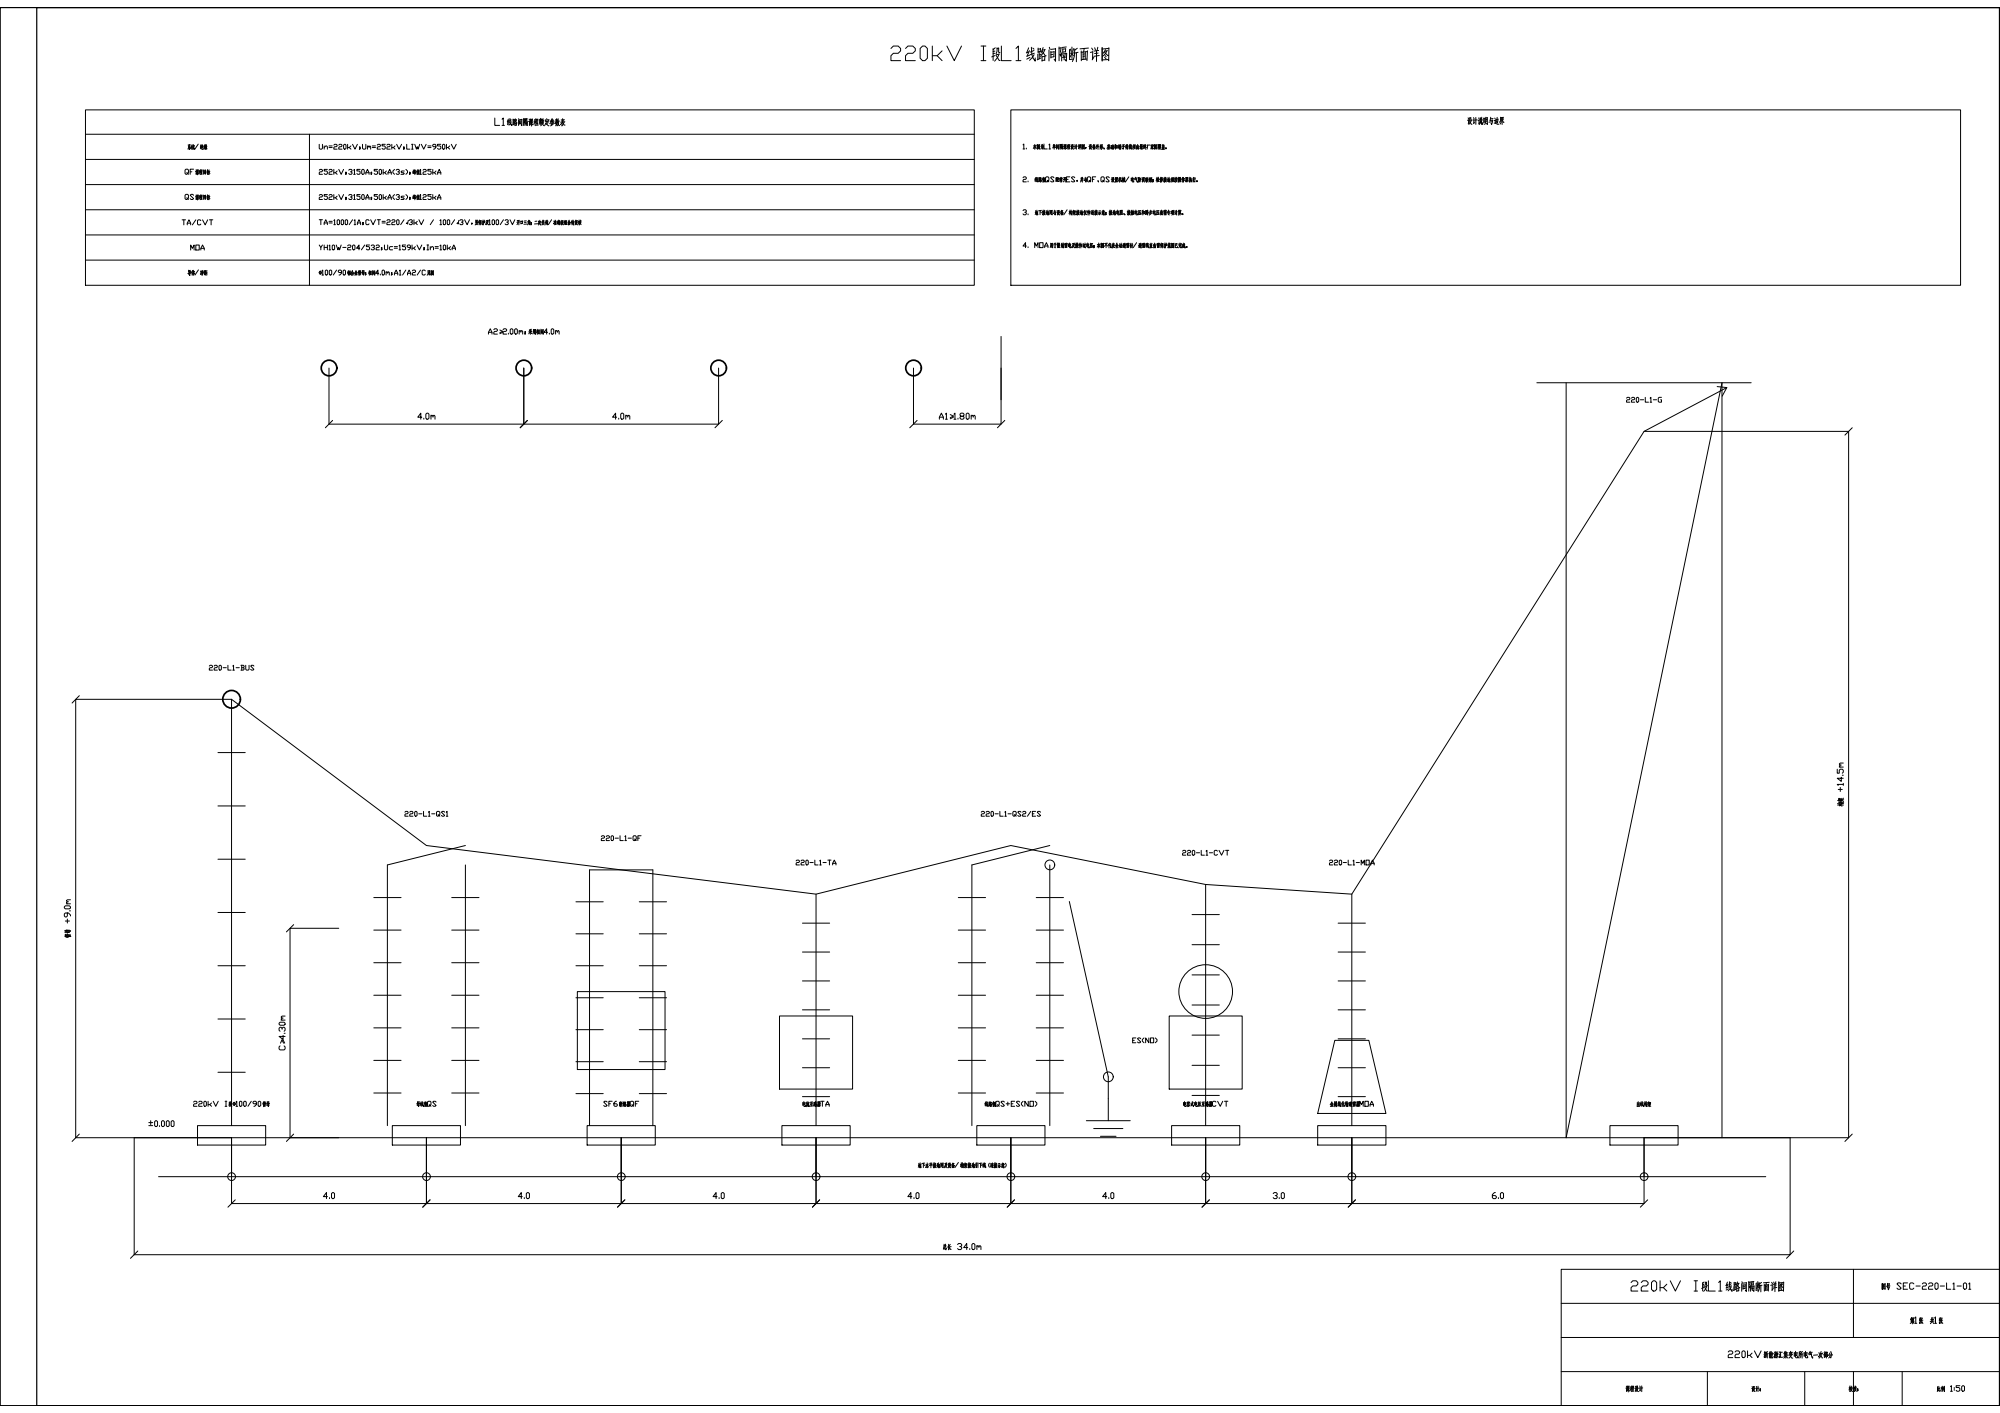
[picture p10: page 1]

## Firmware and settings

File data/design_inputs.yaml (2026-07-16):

project:
  title: "220kV新能源汇集变电所电气一次部分初步设计"
  taskbook_group: 5
  assignment_start: "2026-07-06"
  assignment_end: "2026-07-17"
  source_status: "confirmed_from_local_taskbook"

submission_requirements:
  technical_design_description: true
  technical_calculation_book: true
  single_line_diagram: true
  switchyard_section_drawing: true
  switchyard_plan_drawing: true
  course_summary_and_defense: true
  document_mode: "generally_handwritten_per_taskbook"
  drawing_mode: "CAD_engineering_base_confirmed_by_user; final_submission_to_be_hand_copied"
  cad_engineering_base_authorized: true
  final_hand_copy_required: true

system:
  voltage_levels_kv: [220, 35, 10, 0.4]
  main_transformer_proposal:
    count: 2
    rated_capacity_mva_each: 180
    installation: "outdoor_oil_immersed_on_load_tap_changing"
    winding_scheme: "220_35_two_winding_plus_two_35_10_5kv_source_transformers"
    vector_group: "YNd11"
    neutral_arrangement: "220kv_star_neutral_direct_grounding; 35kv_delta"
  auxiliary_transformer_proposal:
    count: 2
    rated_capacity_mva_each: 31.5
    voltage_ratio_kv: [35, 10.5]
    short_circuit_voltage_percent: 8
    installation: "oil_immersed_power_transformer"
    vector_group: "YNd11"
    evidence_class: "course_design_assumption_supported_by_official_standard_metadata_and_manufacturer_catalog"
  outgoing_220kv:
    in_service_circuits: 2
    reserved_circuits: 1
    conductor: "LGJ-400/50"
    direction: "northwest"
    conductor_ampacity_course_reference:
      reference_ambient_temperature_c: 25
      maximum_conductor_temperature_c: 70
      reference_ampacity_a: 592
      project_ambient_temperature_c: 41
      correction_formula: "sqrt((theta_allow-theta_project)/(theta_allow-theta_reference))"
      evidence_status: "legacy_GB1179_83_secondary_table_course_conservative_reference"
      final_engineering_status: "pending_current_manufacturer_thermal_rating_with_weather_conditions"
  collector_35kv:
    in_service_circuits: 12
    reserved_circuits: 2
    line_type: "mixed_overhead_and_cable"
    circuit_interfaces:
      overhead: ["WA-1", "WA-2", "WA-3", "WA-4", "WB-1", "WB-2", "WB-3"]
      cable: ["PVA-1", "PVA-2", "PVB-1", "PVB-2", "ES-1"]
    directions: ["east", "south"]
  auxiliary_10kv:
    purposes: ["station_service", "reactive_compensation", "cooling", "auxiliary_systems", "backup_supply"]
    direction: "within_station_and_backup_source"

system_sources:
  base_capacity_mva: 100
  source_1:
    equivalent_capacity_mva: 2400
    reactance_pu_on_own_base: 0.40
    line_length_km: 70
  source_2:
    equivalent_capacity_mva: 2000
    reactance_pu_on_own_base: 0.45
    line_length_km: 85
  future_or_tie_line:
    line_length_km: 60
    in_service_for_base_case: false
    status: "sensitivity_case_pending_final_operating_mode"

loads_35kv:
  simultaneous_output_factor: 0.95
  total_installed_active_power_mw: 270
  items:
    - {name: "wind_farm_A", label_zh: "风电场A", active_power_mw: 80, power_factor: 0.95, circuits: 4}
    - {name: "wind_farm_B", label_zh: "风电场B", active_power_mw: 60, power_factor: 0.95, circuits: 3}
    - {name: "pv_plant_A", label_zh: "光伏电站A", active_power_mw: 60, power_factor: 0.98, circuits: 2}
    - {name: "pv_plant_B", label_zh: "光伏电站B", active_power_mw: 40, power_factor: 0.98, circuits: 2}
    - {name: "energy_storage", label_zh: "储能电站", active_power_mw: 30, power_factor: 0.95, circuits: 1}

loads_10kv:
  simultaneity_factor: 0.80
  items:
    - {name: "station_service_backup", label_zh: "站用电备用电源", active_power_mw: 0.8, power_factor: 0.85, circuits: 1}
    - {name: "reactive_compensation_and_cooling", label_zh: "无功补偿及冷却系统", active_power_mw: 0.6, power_factor: 0.85, circuits: 1}
    - {name: "control_communications_and_monitoring", label_zh: "集控通信及监控系统", active_power_mw: 0.4, power_factor: 0.90, circuits: 1}
  reactive_compensation:
    status: "provisional_frozen_for_course_design"
    technology: "dynamic_svg"
    target_power_factor: 0.98
    inverter_reactive_headroom_credited: false
    selected_total_mvar: 24
    selected_dynamic_range_mvar: [-24, 24]
    units:
      - {id: "SVG-1", source_section: "10kV-I", rated_mvar: 12, rated_range_mvar: [-12, 12]}
      - {id: "SVG-2", source_section: "10kV-II", rated_mvar: 12, rated_range_mvar: [-12, 12]}
    control_modes: ["voltage", "reactive_power", "power_factor"]
    harmonic_study_status: "pending_final_special_study"
    exact_vendor_model_status: "pending"
    assumption_note: "Taskbook omits Mvar; selected from project P-Q calculation with conservative 10kV auxiliary-load inclusion."
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

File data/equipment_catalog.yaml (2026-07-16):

schema_version: 1

metadata:
  status: "target_rating_classes_pending_exact_models"
  verified_on: "2026-07-15"
  rule: "target classes support provisional arithmetic only; final selection requires an exact current manufacturer model and page-level evidence"

candidates:
  - id: "TARGET-CB-220"
    kind: "circuit_breaker"
    manufacturer: null
    family: null
    model: null
    installation: "outdoor_sf6"
    evidence:
      status: "target_only"
      document_title: null
      edition_or_revision: null
      issue_date: null
      url: null
      page: null
      verified_on: null
    availability_evidence:
      - manufacturer: "CHINT"
        family: "LW43-252"
        scope: "official 252kV outdoor SF6 live-tank family and drawing only; current and breaking ratings not public on the cited page"
        url: "https://www.chintglobal.com/global/en/products/power-transmission-and-distribution/transmission/lw43-252.html"
        verified_on: "2026-07-15"
      - manufacturer: "Hitachi Energy"
        family: "LTB E"
        scope: "official family-level availability up to 4000A standard-table current and 63kA; not an exact project configuration"
        url: "https://www.hitachienergy.com/products-and-solutions/high-voltage-switchgear-and-breakers/air-insulated-switchgear/live-tank-circuit-breaker-ltb-e-72-5-800-kv"
        verified_on: "2026-07-15"
    ratings:
      highest_voltage_kv: 252
      continuous_current_a: 3150
      short_circuit_breaking_current_ka_rms: 50
      short_circuit_making_current_ka_peak: 125
      peak_withstand_current_ka: 125
      short_time_withstand: {current_ka_rms: 50, duration_s: 3}
    service_conditions:
      max_ambient_c: null
      max_altitude_m: null
      pollution_level: null
      current_correction_factor: null

  - id: "TARGET-DS-220"
    kind: "disconnector"
    manufacturer: null
    family: null
    model: null
    installation: "outdoor"
    evidence:
      status: "target_only"
      document_title: null
      edition_or_revision: null
      issue_date: null
      url: null
      page: null
      verified_on: null
    availability_evidence:
      - manufacturer: "CHINT"
        family: "GW4-.../252 and JW-.../252"
        scope: "official pages list 252kV disconnector and earthing-switch families; exact current and withstand data are not public"
        url: "https://www.chintglobal.com/global/en/products/power-transmission-and-distribution/transmission/gw4-disconnector-gw4.html"
        companion_url: "https://www.chintglobal.com/global/en/products/power-transmission-and-distribution/transmission/jw-earthing-switch-jw.html"
        verified_on: "2026-07-15"
      - manufacturer: "Hitachi Energy"
        family: "GW55"
        scope: "245kV benchmark up to 3150A and 50kA; not proof of a Chinese Um=252kV configuration"
        url: "https://www.hitachienergy.com/products-and-solutions/disconnectors/center-break-disconnectors/center-break-up-to-245-kv"
        verified_on: "2026-07-15"
    ratings:
      highest_voltage_kv: 252
      continuous_current_a: 3150
      peak_withstand_current_ka: 125
      short_time_withstand: {current_ka_rms: 50, duration_s: 3}
    service_conditions:
      max_ambient_c: null
      max_altitude_m: null
      pollution_level: null
      current_correction_factor: null

  - id: "TARGET-SWGR-35-3150"
    kind: "switchgear"
    manufacturer: null
    family: null
    model: null
    installation: "indoor_metal_clad_withdrawable"
    evidence:
      status: "target_only"
      document_title: null
      edition_or_revision: null
      issue_date: null
      url: null
      page: null
      verified_on: null
    availability_evidence:
      - manufacturer: "Siemens"
        family: "NXAirS"
        scope: "official page verifies 40.5kV, up to 3150A and 31.5kA; peak and short-time-duration values still require the exact datasheet"
        url: "https://www.siemens.com/zh-cn/products/energy-systems/nxairs/"
        verified_on: "2026-07-15"
    ratings:
      highest_voltage_kv: 40.5
      continuous_current_a: 3150
      short_circuit_breaking_current_ka_rms: 31.5
      short_circuit_making_current_ka_peak: 80
      peak_withstand_current_ka: 80
      short_time_withstand: {current_ka_rms: 31.5, duration_s: 4}
    service_conditions:
      max_ambient_c: 40
      max_altitude_m: null
      pollution_level: null
      current_correction_factor: 1.0
      temperature_basis: "indoor_controlled"
      temperature_basis_source: "design_inputs.natural_conditions.indoor_switchgear_max_temperature_c"
      final_vendor_confirmation_required: true
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

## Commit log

2026-07-15 feat(calculations): add load and transformer baseline
    [circuit_currents.csv, station_service_loads.csv]
2026-07-15 feat(design): add short-circuit and standards baselines
    Add conditional 220/35kV fault scenarios, renewable RMS sensitivity bounds, generated results, validation tests, and current design-standard governance.
    Refs #3
    [short_circuit_points.csv]
2026-07-15 feat(equipment): add duty-based rating screening
    Generate topology-aware circuit duties, gate conditional and prohibited fault scenarios, screen provisional 220/35kV rating classes, and preserve all missing environmental, thermal, and manufacturer evidence as pending.
    Refs #4
    [equipment_selection_screening.csv]
2026-07-15 fix(topology): align auxiliary supply scheme
    [design_baseline.yaml, design_inputs.yaml, equipment_selection.yaml]
2026-07-15 feat(cad): add A1 single-line drawing pipeline
    [single_line_a1.dxf]
2026-07-15 feat(design): freeze 10kV auxiliary system basis
    [equipment_selection_screening.csv, short_circuit_points.csv]
2026-07-15 feat(design): complete CAD bases and LGJ checks
    Add reproducible A1 plan and section drawings, align the single-line diagram with the frozen T10/SVG, auxiliary-load and grounding bases, and document the hand-copy workflow.
    Add the LGJ-400/50 temperature/N-1 check and stable semantic CI verification for generated DXFs.
    Refs #5
    [single_line_a1.dxf, switchyard_plan_a1.dxf, switchyard_section_a1.dxf]
2026-07-15 feat(delivery): add final reports and defense package
    Add the reviewed DOCX/PDF reports, 11-slide defense deck, reproducible report tooling, public metadata sanitization, and deliverable regression tests.
    Keep public CAD sources in DXF/PDF/PNG while retaining machine-authored DWG files locally. Update repository documentation, health checks, and portable AutoCAD discovery.
    Closes #1
    Closes #2
    Closes #3
    Closes #4
    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
2026-07-16 feat(design): complete primary equipment and CAD deliverables
    Add MOA, ZCT, grounding packages, bus and insulation checks with explicit engineering boundaries.
    Regenerate four A1 drawings, formal reports and defense deck; strengthen reproducibility, metadata and public-release validation.
    [equipment_selection_screening.csv, single_line_a1.dxf, switchyard_line_bay_detail_a1.dxf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]
2026-07-17 fix(cad): refine required drawing geometry
    [single_line_a1.dxf, switchyard_plan_a1.dxf, switchyard_section_a1.dxf]
2026-07-17 fix(cad): show transformer winding connections
    [single_line_a1.dxf]
